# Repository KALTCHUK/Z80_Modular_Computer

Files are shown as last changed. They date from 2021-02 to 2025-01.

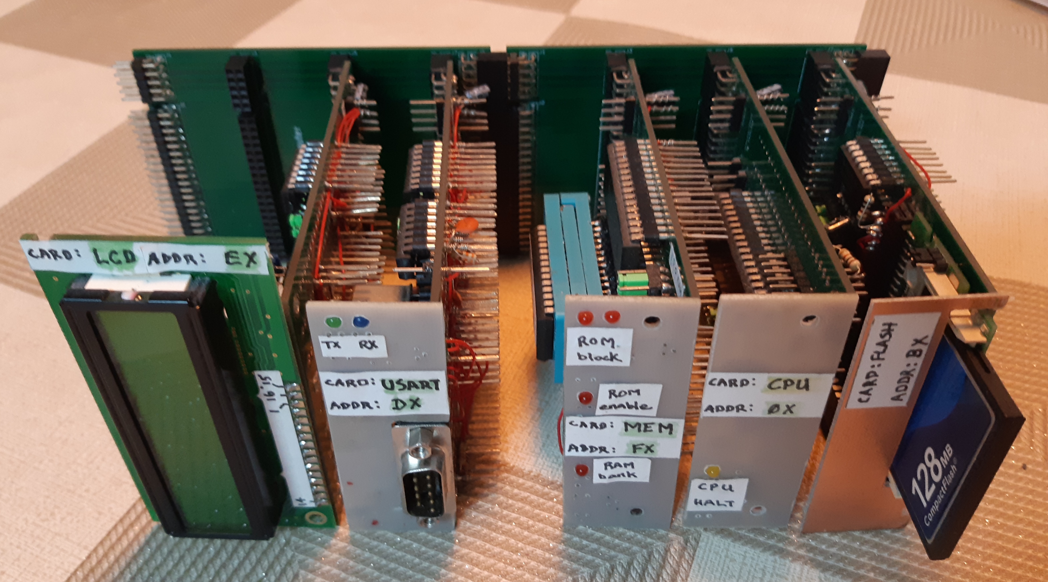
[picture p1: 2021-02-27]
pics and vids/assembly_full_1.jpg

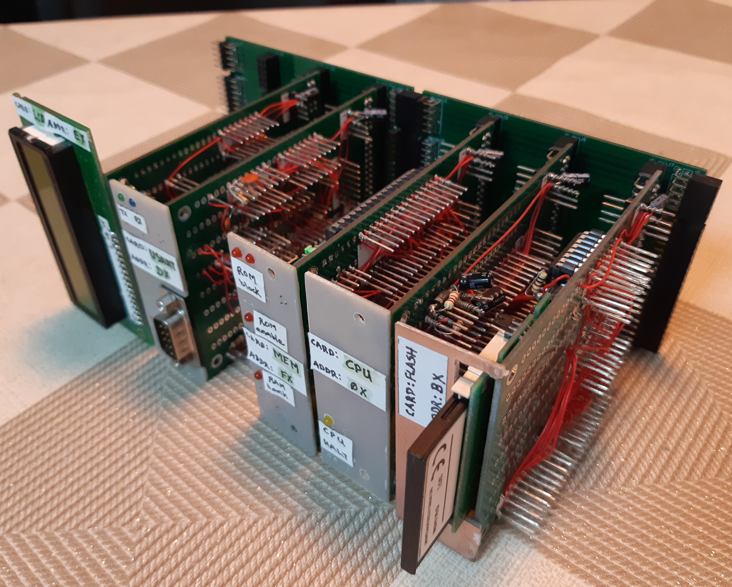
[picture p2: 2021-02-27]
pics and vids/assembly_full_2.jpg

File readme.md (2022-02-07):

# Proton - Z80 Modular Computer #

## Licence ##
This project is made public under the terms of the strongly-reciprocal variant of the CERN Open Hardware Licence version 2. By using any part of this project you abide to this licence.

## Overview ##
Two years ago I was searching for some ICs in my component drawers and came across a Z80 CPU and an Intel 8251 USART. I had an instant flashback and remembered my first contact with a microprocessor back in 1982. It was a Z80. After a few minutes of nostalgia I decided to make good use of these components and build a computer. 

Of course I couldn't avoid thinking about this "new project" with my Systems Engineer mindset. So, I established a few initial goals:

- This project is a hobby, so it has to be fun.
- It should use mainly technologies available in the 1980's.
- The computer has to run commercial software.
- The architecture should be modular allowing for new cards with specific functions.
- It also has to be a hardware/software development platform for students, hobbyists and enthusiasts.

After some research I decided to design the hardware fully compatible with CP/M 2.2.

One and a half years later, I finally had my wire wrapped computer running CP/M. I could write programs using WordStar and compile them with BDS C compiler, Microsoft Basic compiler or SLR Z80 macro assembler. It was fun, exciting and challenging. After that, I decided it was time to turn the prototype into a finished product.

It's gratifying to see that in two years, alone, I was able to transform an idea into a commercial product.

The content of this repo is a small portion of the knowledge gathered during these two years developing the Proton Z80 Modular Computer. Most of the information and results are in my logbook - a notebook (paper, not a computer), where I write everything before executing. During this period, I was the system engineer, hardware engineer, software engineer and project manager. Why did it take me so long to complete this project? Because it's a weekend hobby and also because sometimes I had to wait many weeks to receive some components and PCBs.  

Ricardo Kaltchuk

Ashdod - IL, october 2021.

## About the final product. ##

Is it perfect? No. 
Is it state of the art? No. 
Does I meet the initial goal? Yes. 
Am I happy with it? For sure!

## Github directories ##

All directory names are self-explanatory and you'll find a readme file inside each one with some additional info.

## What's most important ##

Well, if you want to build your own Proton Z80 Modular Computer, you'll need to check at least these directories:

- CPM build,
- CPM software,
- KiCAD files,
- Monitor build,
- System manuals (Proton and Monitor) and
- pics.

## You want your own Proton? So follow these steps: ##

1) Order the PCBs. You can order from PCBway and JLC PCB with the codes in the Proton Manual.
2) Buy the components according to the bill of materials in the Proton Manual.
3) Assemble the cards.
4) Download the software from Github.
5) Burn the EEPROM and microcontrollers.
6) Configure the jumpers on the cards according to instructions in the Proton Manual.
7) Assemble the rack (optional) and insert the cards.

Ready to start! Now you can transfer all the CP/M software from your computer to the Proton.

In the Proton User's Manual there's a section called "Building Procedure" which describes in details all the steps listed above. I suggest you read ALL the manual before starting.

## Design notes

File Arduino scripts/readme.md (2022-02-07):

## What you'll find in this directory ##
Only Arduino scripts. Nothing relevant for the Proton assembly, except if you intend to build your own EEPROM programmer. In this case, you should take a look at EProg_1.3. There you'll find the Arduino script used on the EPROG - EEPROM Programmer, that I made. The circuit diagram and PCB layout are in the "KiCAD files" directory. It's important to note that I designed the EPROG specifically to be used with the W27C512.

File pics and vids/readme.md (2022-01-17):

## What you'll find in this directory ##
Pictures and videos of the Proton, from wire wrapped ptototype phase to final products. Also a few videos of CP/M and the Monitor demo.

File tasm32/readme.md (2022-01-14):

## What you'll find in this directory ##
Tasm is a macro assembler for Z80 and few other CPUs. It runs on DOS and is quite robust and simple. I used it to compile all assembly files in "CPM build" and "Monitor build". The compilation generates a .OBJ file, which is a HEX in Intel format file.

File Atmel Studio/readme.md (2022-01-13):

## What you'll find in this directory ##
Several "projects" built with Atmel Studio. Most of them are only some tests I made in order to get familiar with Atmel Studio, AVRISP mkII programmer and ATmega328 microcontroller.

The important thing here is the directory called "preTTY". (It's called preTTY because I started working on it before the TTY Card was complete). There you'll find the firmware used on the microcontrollers from the TTY Card (two ATmega328, one for each serial port). Both microcontrollers have exactly the same firmware.

Before beginning the Proton project I already had a good experience using Arduino. But, for the TTY Card, I couldn't simply plug an Arduind board and that's it. So I used only the Arduino's microcontroller "bareback", with no bootloader, running at 20MHz.

Yeah, yeah, I know, I'm using sequencial logic to implement combinational tasks. Who cares? It was challenging and I did it.

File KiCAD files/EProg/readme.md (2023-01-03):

## What you'll find in this directory ##
The KiCAD files for a EEPROM programmer, specifically, the W27C512, a 64KB EEPROM, which I used on the Proton MEM Card.

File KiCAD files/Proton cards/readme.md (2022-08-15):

## What you'll find in this directory ##
Each subdirectory contains the KiCAD files for a specific Proton card, assembled in the rack. They all contain the circuit diagrams. Most of them also have the PCB layouts and some even have the Gerber files I sent to the PCB manufacturers (PCBway and JLC PCB)).

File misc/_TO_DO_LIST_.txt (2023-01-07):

- DO-08:
	- design PCB
	- assemble and test

- DI-08:
	- write firmware.
	- build and test prototype
	- design PCB
	- assemble and test

- RS485:
	- design PCB
	- assemble and test

------------------------------------------------------------------
Some ideas for new cards:

- PWM, stepper motor, fast counter, analog I/O (4-20mA, RTD, TC?)
- audio card for .WAV play
- VGA and PS2 keyboard (FPGA, STM32?)

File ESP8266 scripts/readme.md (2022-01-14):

## What you'll find in this directory ##
When I was almost finishing the Proton prototype I had this idea to use an ESP8266 connected to one of the serial ports of the TTY Card and access the Proton via telnet. I didn't complete the idea, but some of the experiences are here. I managed to connect the ESP8266 and the telnet cliente when they were in the same network (WiFi), but didn't succeed using dynamic DNS. To be continued...

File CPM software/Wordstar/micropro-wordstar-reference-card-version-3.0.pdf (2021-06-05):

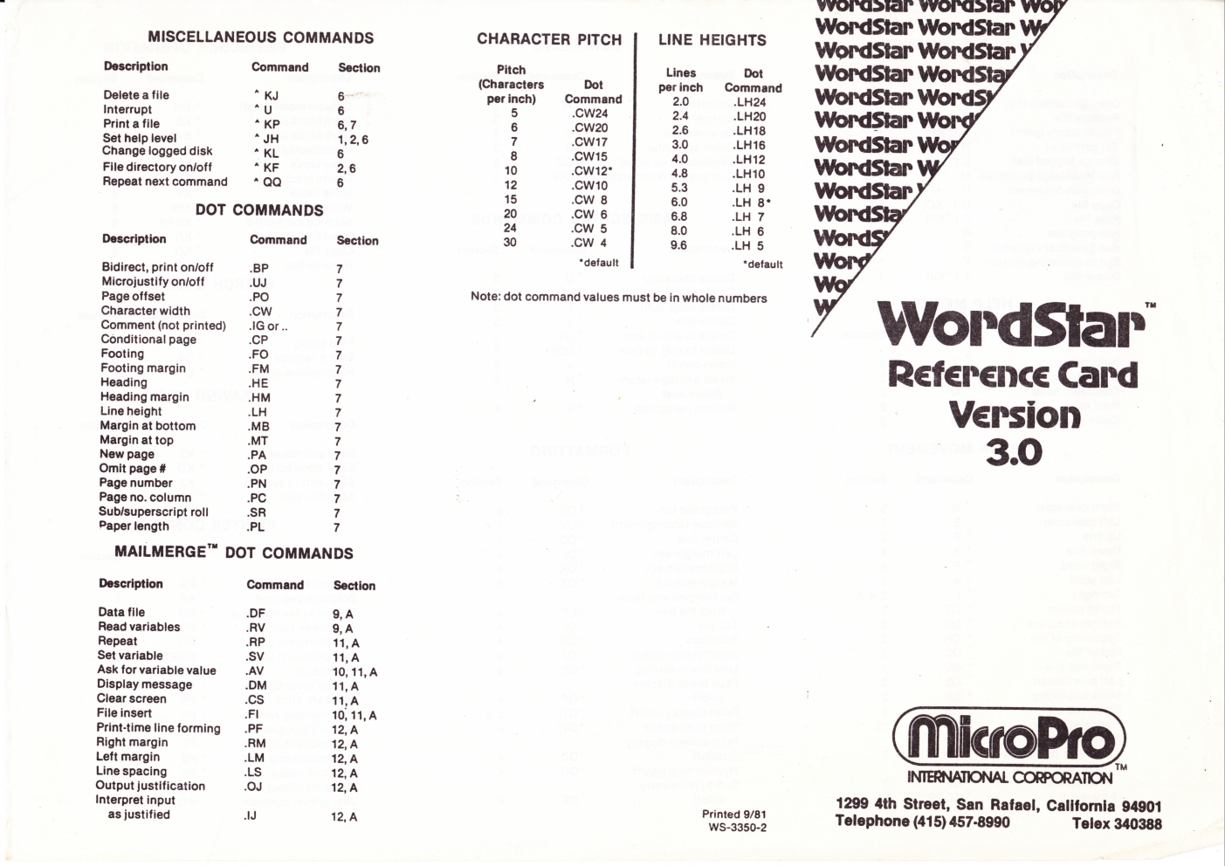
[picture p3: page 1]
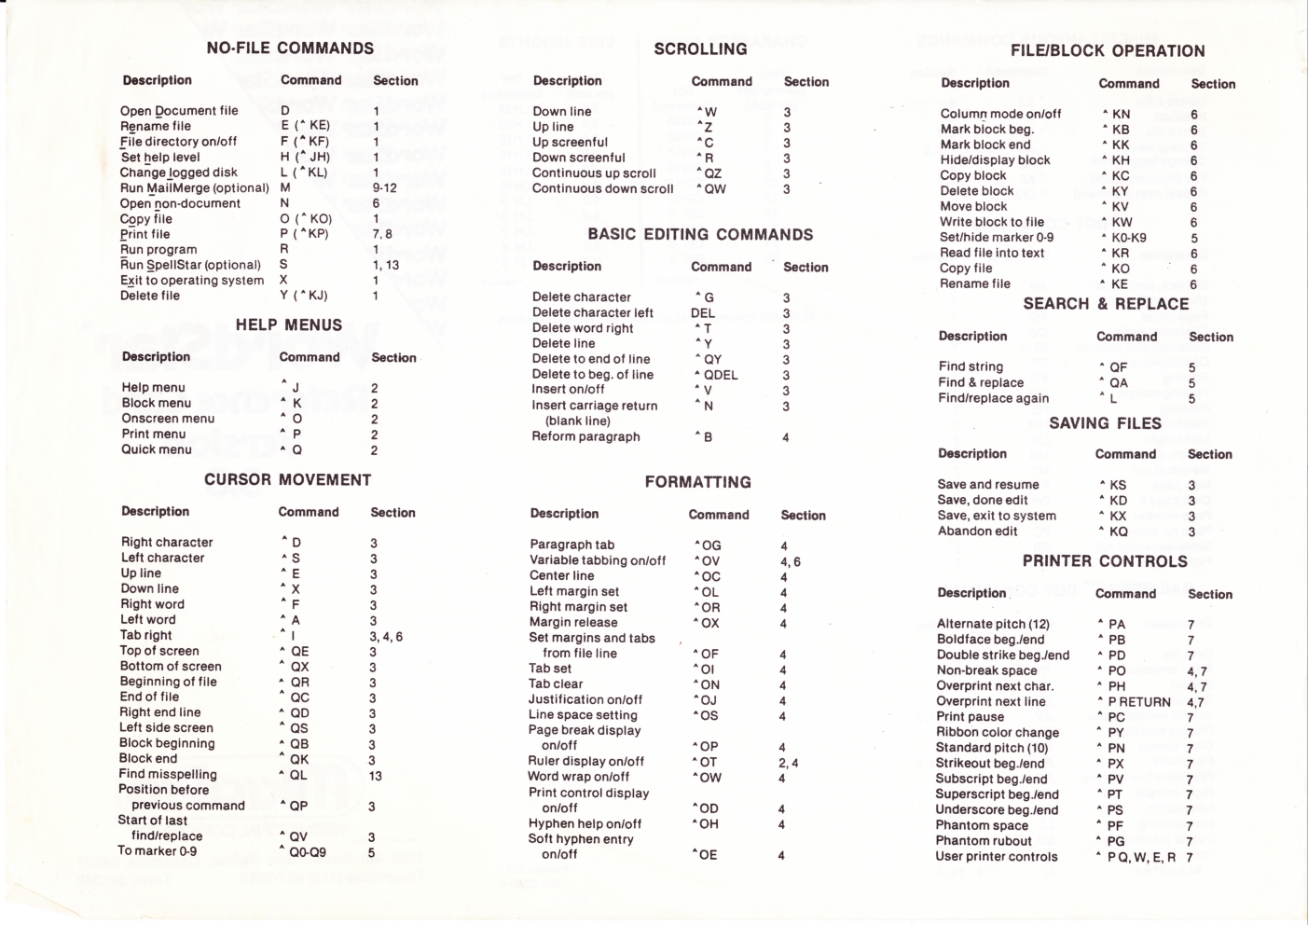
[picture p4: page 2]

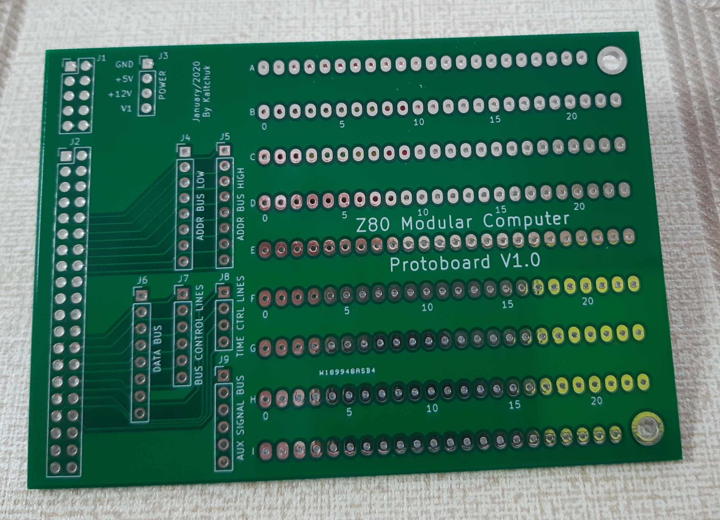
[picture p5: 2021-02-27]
pics and vids/protoboard_1.jpg

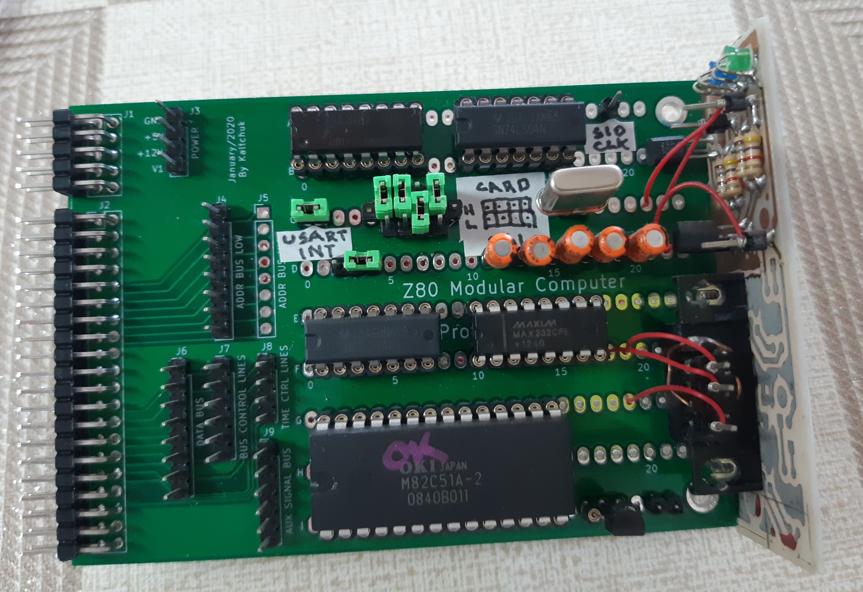
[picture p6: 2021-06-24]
pics and vids/proto_usart_1.jpg

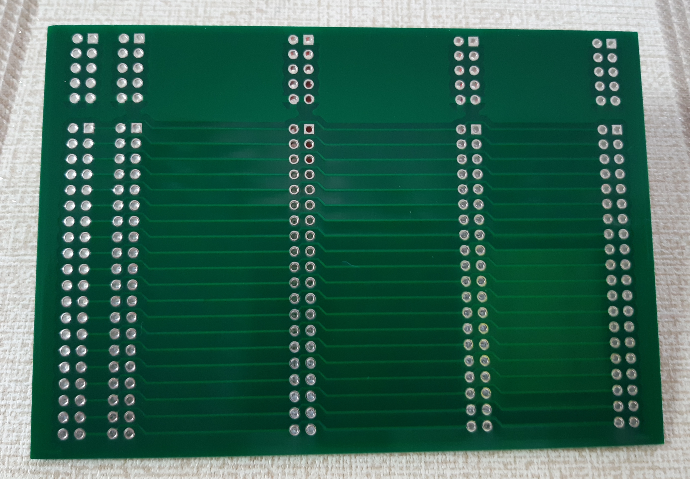
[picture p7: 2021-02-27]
pics and vids/backplane_2.jpg

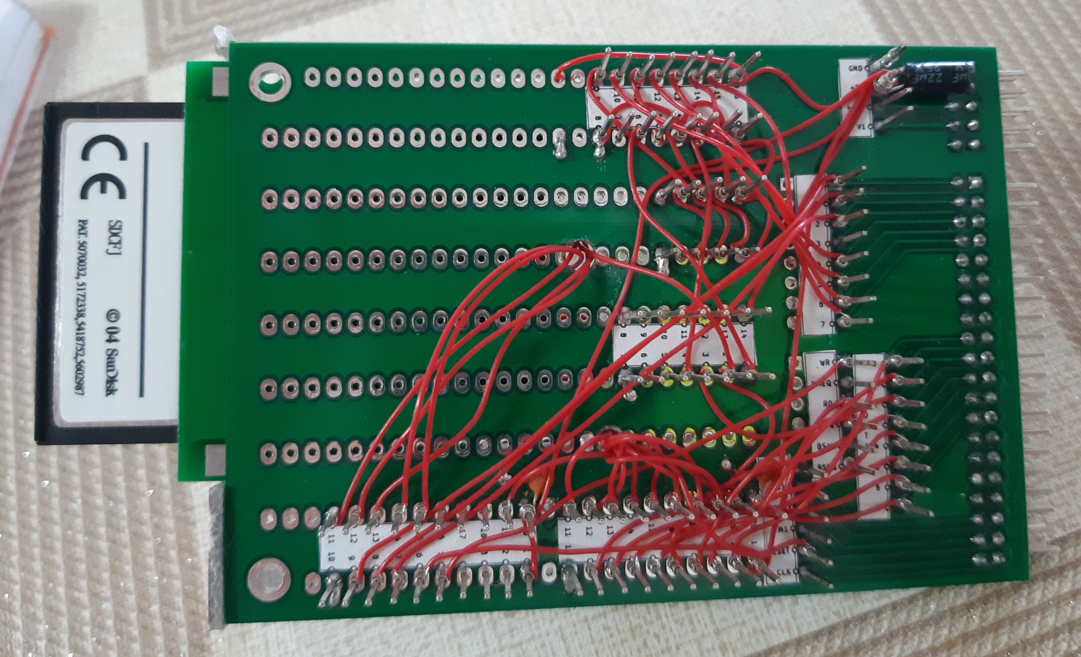
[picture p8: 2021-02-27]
pics and vids/proto_flash_2.jpg

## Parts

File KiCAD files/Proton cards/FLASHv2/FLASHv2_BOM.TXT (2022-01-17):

REFERENCE	VALUE		DESCRIPTION								QTY
-----------------------------------------------------------------------------------------------------------
    C1	10uF		Capacitor_THT:CP_Radial_D5.0mm_P2.50mm						1
  C2-C6	10nF		Capacitor_THT:C_Disc_D3.8mm_W2.6mm_P2.50mm					5
    J1	card addr	Connector_PinHeader_2.54mm:PinHeader_2x04_P2.54mm_Vertical			1
    J2	Power Bus	Connector_PinHeader_2.54mm:PinHeader_2x05_P2.54mm_90_deg_female			1
    J3	Signal Bus	Connector_PinHeader_2.54mm:PinHeader_2x20_P2.54mm_90_deg_female			1
    J4	IDE connector	Connector_PinHeader_2.00mm:PinHeader_2x22_P2.00mm_90_deg_female +		1
			IDE 44 Pin Male to CF Compact Flash Male Adapter Connector +
			Compact Flash 128MB
    R6	1k		Resistor_THT:R_Axial_DIN0207_L6.3mm_D2.5mm_P10.16mm_Horizontal			1
    RN1	4x10k		Resistor_THT:R_Array_SIP5							1
    U1	74LS04		Package_DIP:DIP-14_W7.62mm_Socket_LongPads + 14 pin DIP socket			1
    U2	74LS85		Package_DIP:DIP-16_W7.62mm_Socket_LongPads + 16 pin DIP socket			1
  U3, U4		74LS245	Package_DIP:DIP-20_W7.62mm_Socket_LongPads +20 pin DIP socket		2

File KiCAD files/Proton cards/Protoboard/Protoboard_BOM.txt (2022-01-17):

    J1	Power Bus	Connector_PinHeader_2.54mm:PinHeader_2x05_P2.54mm_Vertical	~	1
    J2	Signal Bus	Connector_PinHeader_2.54mm:PinHeader_2x20_P2.54mm_Vertical	~	1
    J3	Power	Connector_PinHeader_2.54mm:PinHeader_1x04_P2.54mm_Vertical	~	1
    J4	ADDR LO	Connector_PinHeader_2.54mm:PinHeader_1x08_P2.54mm_Vertical	~	1
    J5	ADDR HI	Connector_PinHeader_2.54mm:PinHeader_1x08_P2.54mm_Vertical	~	1
    J6	DATA	Connector_PinHeader_2.54mm:PinHeader_1x08_P2.54mm_Vertical	~	1
    J7	BUS CTRL	Connector_PinHeader_2.54mm:PinHeader_1x06_P2.54mm_Vertical	~	1
    J8	TIME CTRL	Connector_PinHeader_2.54mm:PinHeader_1x04_P2.54mm_Vertical	~	1
    J9	AUX SIGNAL	Connector_PinHeader_2.54mm:PinHeader_1x06_P2.54mm_Vertical	~	1

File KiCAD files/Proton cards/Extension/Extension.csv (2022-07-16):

Source: | C:\Users\kaltc\Documents\GitHub\Z80_Modular_Computer\KiCAD files\Extension\Extension.kicad_sch
Date: | 16/07/2022 6:46:03
Tool: | Eeschema (6.0.4)
Generator: | C:\Program Files\KiCad\6.0\bin\scripting\plugins/bom_csv_grouped_by_value.py
Component Count: | 4
Individual Components:
Item | Qty | Reference(s) | Value | LibPart | Footprint | Datasheet
 |  | J1 | Conn_02x05_Odd_Even | Connector_Generic:Conn_02x05_Odd_Even | Connector_PinHeader_2.54mm:PinHeader_2x05_P2.54mm_Vertical | ~
 |  | J2 | Conn_02x20_Odd_Even | Connector_Generic:Conn_02x20_Odd_Even | Connector_PinHeader_2.54mm:PinHeader_2x20_P2.54mm_Vertical | ~
 |  | J3 | Conn_02x05_Odd_Even | Connector_Generic:Conn_02x05_Odd_Even | Connector_PinHeader_2.54mm:PinHeader_2x05_P2.54mm_Vertical | ~
 |  | J4 | Conn_02x20_Odd_Even | Connector_Generic:Conn_02x20_Odd_Even | Connector_PinHeader_2.54mm:PinHeader_2x20_P2.54mm_Vertical | ~
Collated Components:
Item | Qty | Reference(s) | Value | LibPart | Footprint | Datasheet
1 | 2 | J1, J3 | Conn_02x05_Odd_Even | Connector_Generic:Conn_02x05_Odd_Even | Connector_PinHeader_2.54mm:PinHeader_2x05_P2.54mm_Vertical | ~
2 | 2 | J2, J4 | Conn_02x20_Odd_Even | Connector_Generic:Conn_02x20_Odd_Even | Connector_PinHeader_2.54mm:PinHeader_2x20_P2.54mm_Vertical | ~

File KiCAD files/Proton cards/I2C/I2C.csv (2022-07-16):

Source: | C:\Users\kaltc\Documents\GitHub\Z80_Modular_Computer\KiCAD files\I2C\I2C.kicad_sch
Date: | 16/07/2022 6:00:42
Tool: | Eeschema (6.0.4)
Generator: | C:\Program Files\KiCad\6.0\bin\scripting\plugins/bom_csv_grouped_by_value.py
Component Count: | 33
Individual Components:
Item | Qty | Reference(s) | Value | LibPart | Footprint | Datasheet
 |  | BT1 | 3V | Device:Battery_Cell | MyStuff:Battery-Holder_CR2032 | ~
 |  | C1 | 10nF | Device:C | Capacitor_THT:C_Disc_D3.8mm_W2.6mm_P2.50mm | ~
 |  | C2 | 10nF | Device:C | Capacitor_THT:C_Disc_D3.8mm_W2.6mm_P2.50mm | ~
 |  | C3 | 10nF | Device:C | Capacitor_THT:C_Disc_D3.8mm_W2.6mm_P2.50mm | ~
 |  | C4 | 10nF | Device:C | Capacitor_THT:C_Disc_D3.8mm_W2.6mm_P2.50mm | ~
 |  | C5 | 10nF | Device:C | Capacitor_THT:C_Disc_D3.8mm_W2.6mm_P2.50mm | ~
 |  | C6 | 10nF | Device:C | Capacitor_THT:C_Disc_D3.8mm_W2.6mm_P2.50mm | ~
 |  | C7 | 10nF | Device:C | Capacitor_THT:C_Disc_D3.8mm_W2.6mm_P2.50mm | ~
 |  | C8 | 10nF | Device:C | Capacitor_THT:C_Disc_D3.8mm_W2.6mm_P2.50mm | ~
 |  | C9 | 10uF | Device:CP | Capacitor_THT:CP_Radial_D5.0mm_P2.50mm
 |  | C10 | 33pF | Device:C | Capacitor_THT:C_Disc_D3.8mm_W2.6mm_P2.50mm | ~
 |  | C11 | 33pF | Device:C | Capacitor_THT:C_Disc_D3.8mm_W2.6mm_P2.50mm | ~
 |  | H1 | MountingHole | Mechanical:MountingHole | MountingHole:MountingHole_3mm_Pad_TopBottom | ~
 |  | H2 | MountingHole | Mechanical:MountingHole | MountingHole:MountingHole_3mm_Pad_TopBottom | ~
 |  | J1 | card addr | Connector_Generic:Conn_02x04_Odd_Even | Connector_PinHeader_2.54mm:PinHeader_2x04_P2.54mm_Vertical | ~
 |  | J2 | Power Bus | Connector_Generic:Conn_02x05_Odd_Even | Connector_PinHeader_2.54mm:PinHeader_2x05_P2.54mm_Vertical | ~
 |  | J3 | Signal Bus | Connector_Generic:Conn_02x20_Odd_Even | Connector_PinHeader_2.54mm:PinHeader_2x20_P2.54mm_Vertical | ~
 |  | J4 | I2C int | Connector:Conn_01x04_Male | Connector_PinHeader_2.54mm:PinHeader_1x04_P2.54mm_Vertical | ~
 |  | J5 | I2C ext | Connector_Generic:Conn_02x02_Top_Bottom | Connector_PinHeader_2.54mm:PinHeader_2x02_P2.54mm_Vertical | ~
 |  | R1 | 6k8 | Device:R | Resistor_THT:R_Axial_DIN0207_L6.3mm_D2.5mm_P10.16mm_Horizontal | ~
 |  | R2 | 6k8 | Device:R | Resistor_THT:R_Axial_DIN0207_L6.3mm_D2.5mm_P10.16mm_Horizontal | ~
 |  | RN1 | 4x10k | Device:R_Network04 | Resistor_THT:R_Array_SIP5 | http://www.vishay.com/docs/31509/csc.pdf
 |  | RN2 | 4x10k | Device:R_Network04 | Resistor_THT:R_Array_SIP5 | http://www.vishay.com/docs/31509/csc.pdf
 |  | U1 | 74LS85 | 74xx:74LS85 | Package_DIP:DIP-16_W7.62mm_Socket_LongPads | http://www.ti.com/lit/gpn/sn74LS85
 |  | U2 | 74LS74 | 74xx:74LS74 | Package_DIP:DIP-14_W7.62mm_Socket_LongPads | 74xx/74hc_hct74.pdf
 |  | U3 | 74LS04 | 74xx:74LS04 | Package_DIP:DIP-14_W7.62mm_Socket_LongPads | http://www.ti.com/lit/gpn/sn74LS04
 |  | U4 | 74LS08 | 74xx:74LS08 | Package_DIP:DIP-14_W7.62mm_Socket_LongPads | http://www.ti.com/lit/gpn/sn74LS08
 |  | U5 | 74LS245 | 74xx:74LS245 | Package_DIP:DIP-20_W7.62mm_Socket_LongPads | http://www.ti.com/lit/gpn/sn74LS245
 |  | U6 | AT89C4051-24P | MCU_Microchip_8051:AT89C4051-24P | Package_DIP:DIP-20_W7.62mm_Socket_LongPads | http://ww1.microchip.com/downloads/en/DeviceDoc/doc1001.pdf
 |  | U7 | DS1307+ | Timer_RTC:DS1307+ | Package_DIP:DIP-8_W7.62mm_Socket_LongPads | https://datasheets.maximintegrated.com/en/ds/DS1307.pdf
 |  | U8 | FM24C64B | Memory_NVRAM:FM24C64B | Package_DIP:DIP-8_W7.62mm_Socket_LongPads | http://www.cypress.com/file/41651/download
 |  | Y1 | 24MHz | Device:Crystal | Crystal:Crystal_HC49-U_Vertical | ~
 |  | Y2 | 32.768kHz | Device:Crystal_Small | Crystal:Crystal_Round_D1.5mm_Vertical | ~
Collated Components:
Item | Qty | Reference(s) | Value | LibPart | Footprint | Datasheet
1 | 1 | BT1 | 3V | Device:Battery_Cell | MyStuff:Battery-Holder_CR2032 | ~
2 | 8 | C1, C2, C3, C4, C5, C6, C7, C8 | 10nF | Device:C | Capacitor_THT:C_Disc_D3.8mm_W2.6mm_P2.50mm | ~
3 | 1 | C9 | 10uF | Device:CP | Capacitor_THT:CP_Radial_D5.0mm_P2.50mm
4 | 2 | C10, C11 | 33pF | Device:C | Capacitor_THT:C_Disc_D3.8mm_W2.6mm_P2.50mm | ~
5 | 2 | H1, H2 | MountingHole | Mechanical:MountingHole | MountingHole:MountingHole_3mm_Pad_TopBottom | ~
6 | 1 | J1 | card addr | Connector_Generic:Conn_02x04_Odd_Even | Connector_PinHeader_2.54mm:PinHeader_2x04_P2.54mm_Vertical | ~
7 | 1 | J2 | Power Bus | Connector_Generic:Conn_02x05_Odd_Even | Connector_PinHeader_2.54mm:PinHeader_2x05_P2.54mm_Vertical | ~
8 | 1 | J3 | Signal Bus | Connector_Generic:Conn_02x20_Odd_Even | Connector_PinHeader_2.54mm:PinHeader_2x20_P2.54mm_Vertical | ~
9 | 1 | J4 | I2C int | Connector:Conn_01x04_Male | Connector_PinHeader_2.54mm:PinHeader_1x04_P2.54mm_Vertical | ~
10 | 1 | J5 | I2C ext | Connector_Generic:Conn_02x02_Top_Bottom | Connector_PinHeader_2.54mm:PinHeader_2x02_P2.54mm_Vertical | ~
11 | 2 | R1, R2 | 6k8 | Device:R | Resistor_THT:R_Axial_DIN0207_L6.3mm_D2.5mm_P10.16mm_Horizontal | ~
12 | 2 | RN1, RN2 | 4x10k | Device:R_Network04 | Resistor_THT:R_Array_SIP5 | http://www.vishay.com/docs/31509/csc.pdf
13 | 1 | U1 | 74LS85 | 74xx:74LS85 | Package_DIP:DIP-16_W7.62mm_Socket_LongPads | http://www.ti.com/lit/gpn/sn74LS85
14 | 1 | U2 | 74LS74 | 74xx:74LS74 | Package_DIP:DIP-14_W7.62mm_Socket_LongPads | 74xx/74hc_hct74.pdf
15 | 1 | U3 | 74LS04 | 74xx:74LS04 | Package_DIP:DIP-14_W7.62mm_Socket_LongPads | http://www.ti.com/lit/gpn/sn74LS04
16 | 1 | U4 | 74LS08 | 74xx:74LS08 | Package_DIP:DIP-14_W7.62mm_Socket_LongPads | http://www.ti.com/lit/gpn/sn74LS08
17 | 1 | U5 | 74LS245 | 74xx:74LS245 | Package_DIP:DIP-20_W7.62mm_Socket_LongPads | http://www.ti.com/lit/gpn/sn74LS245
18 | 1 | U6 | AT89C4051-24P | MCU_Microchip_8051:AT89C4051-24P | Package_DIP:DIP-20_W7.62mm_Socket_LongPads | http://ww1.microchip.com/downloads/en/DeviceDoc/doc1001.pdf
19 | 1 | U7 | DS1307+ | Timer_RTC:DS1307+ | Package_DIP:DIP-8_W7.62mm_Socket_LongPads | https://datasheets.maximintegrated.com/en/ds/DS1307.pdf
20 | 1 | U8 | FM24C64B | Memory_NVRAM:FM24C64B | Package_DIP:DIP-8_W7.62mm_Socket_LongPads | http://www.cypress.com/file/41651/download
21 | 1 | Y1 | 24MHz | Device:Crystal | Crystal:Crystal_HC49-U_Vertical | ~
22 | 1 | Y2 | 32.768kHz | Device:Crystal_Small | Crystal:Crystal_Round_D1.5mm_Vertical | ~

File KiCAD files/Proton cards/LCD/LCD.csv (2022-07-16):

Source: | C:\Users\kaltc\Documents\GitHub\Z80_Modular_Computer\KiCAD files\LCD\LCD.kicad_sch
Date: | 16/07/2022 7:41:25
Tool: | Eeschema (6.0.4)
Generator: | C:\Program Files\KiCad\6.0\bin\scripting\plugins/bom_csv_grouped_by_value.py
Component Count: | 12
Individual Components:
Item | Qty | Reference(s) | Value | LibPart | Footprint | Datasheet
 |  | C1 | 10uF | Device:CP
 |  | J1 | card addr | Connector_Generic:Conn_02x04_Odd_Even |  | ~
 |  | J2 | Power Bus | Connector_Generic:Conn_02x05_Odd_Even |  | ~
 |  | J3 | Signal Bus | Connector_Generic:Conn_02x20_Odd_Even |  | ~
 |  | J4 | LCD connector | Connector:Conn_01x16_Female |  | ~
 |  | R1 | 10k | Device:R |  | ~
 |  | R2 | 10k | Device:R |  | ~
 |  | R3 | 10k | Device:R |  | ~
 |  | R4 | 10k | Device:R |  | ~
 |  | RV1 | 10k | Device:R_POT_TRIM
 |  | U1 | 74LS04 | 74xx:74LS04 |  | http://www.ti.com/lit/gpn/sn74LS04
 |  | U2 | 74LS85 | 74xx:74LS85 |  | http://www.ti.com/lit/gpn/sn74LS85
Collated Components:
Item | Qty | Reference(s) | Value | LibPart | Footprint | Datasheet
1 | 1 | C1 | 10uF | Device:CP
2 | 1 | J1 | card addr | Connector_Generic:Conn_02x04_Odd_Even |  | ~
3 | 1 | J2 | Power Bus | Connector_Generic:Conn_02x05_Odd_Even |  | ~
4 | 1 | J3 | Signal Bus | Connector_Generic:Conn_02x20_Odd_Even |  | ~
5 | 1 | J4 | LCD connector | Connector:Conn_01x16_Female |  | ~
6 | 4 | R1, R2, R3, R4 | 10k | Device:R |  | ~
7 | 1 | RV1 | 10k | Device:R_POT_TRIM
8 | 1 | U1 | 74LS04 | 74xx:74LS04 |  | http://www.ti.com/lit/gpn/sn74LS04
9 | 1 | U2 | 74LS85 | 74xx:74LS85 |  | http://www.ti.com/lit/gpn/sn74LS85

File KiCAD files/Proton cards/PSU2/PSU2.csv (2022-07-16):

Source: | C:\Users\kaltc\Documents\GitHub\Z80_Modular_Computer\KiCAD files\PSU2\PSU2.kicad_sch
Date: | 16/07/2022 6:23:53
Tool: | Eeschema (6.0.4)
Generator: | C:\Program Files\KiCad\6.0\bin\scripting\plugins/bom_csv_grouped_by_value.py
Component Count: | 20
Individual Components:
Item | Qty | Reference(s) | Value | LibPart | Footprint | Datasheet
 |  | D1 | LED | Device:LED | LED_THT:LED_D3.0mm | ~
 |  | D2 | LED | Device:LED | LED_THT:LED_D3.0mm | ~
 |  | D3 | LED | Device:LED | LED_THT:LED_D3.0mm | ~
 |  | H1 | MountingHole | Mechanical:MountingHole | MyStuff:Mounting_Hole_0.2in | ~
 |  | H2 | MountingHole | Mechanical:MountingHole | MyStuff:Mounting_Hole_0.2in | ~
 |  | J1 | Ext switch | Connector_Generic:Conn_01x02 | Connector_PinHeader_2.54mm:PinHeader_1x02_P2.54mm_Vertical | ~
 |  | J2 | To switch | Connector_Generic:Conn_01x02 | Connector_PinHeader_2.54mm:PinHeader_1x02_P2.54mm_Vertical | ~
 |  | J3 | Mains | Connector_Generic:Conn_01x02 | MyStuff:IEC60320_2pin | ~
 |  | J4 | Vo enable | Connector_Generic:Conn_02x02_Odd_Even | Connector_PinHeader_2.54mm:PinHeader_2x02_P2.54mm_Vertical | ~
 |  | J5 | Power bus | Connector_Generic:Conn_02x05_Odd_Even | Connector_PinHeader_2.54mm:PinHeader_2x05_P2.54mm_Vertical | ~
 |  | J6 | Mech support | Connector_Generic:Conn_02x05_Odd_Even | Connector_PinHeader_2.54mm:PinHeader_2x05_P2.54mm_Vertical | ~
 |  | K1 | SRD-05VDC-SL-C | Relay:Y14x-1C-xxDS | MyStuff:Relay_SPDT_Songel-15x19mm | http://www.hsinda.com.cn/en/imgdown.asp?FileName=UploadFiles/201431310240386.pdf
 |  | PS1 | MT3608_2-24V_2A | Converter_DCDC:MEE1S0512SC | MyStuff:MT3608_2-24V_2A | https://power.murata.com/pub/data/power/ncl/kdc_mee1.pdf
 |  | PS2 | XPJ-01B_5V_10W | Converter_ACDC:IRM-10-5 | MyStuff:Converter_ACDC_5V_10W_XPJ-01B | https://www.meanwell.com/Upload/PDF/IRM-10/IRM-10-SPEC.PDF
 |  | R1 | 1k2 | Device:R | Resistor_THT:R_Axial_DIN0207_L6.3mm_D2.5mm_P7.62mm_Horizontal | ~
 |  | R2 | 390 | Device:R | Resistor_THT:R_Axial_DIN0207_L6.3mm_D2.5mm_P7.62mm_Horizontal | ~
 |  | R3 | 330 | Device:R | Resistor_THT:R_Axial_DIN0207_L6.3mm_D2.5mm_P7.62mm_Horizontal | ~
 |  | R4 | 240 | Device:R | Resistor_THT:R_Axial_DIN0207_L6.3mm_D2.5mm_P7.62mm_Horizontal | ~
 |  | R5 | 150 | Device:R | Resistor_THT:R_Axial_DIN0207_L6.3mm_D2.5mm_P7.62mm_Horizontal | ~
 |  | U1 | LM317_TO-220 | Regulator_Linear:LM317_TO-220 | Package_TO_SOT_THT:TO-220-3_Vertical | http://www.ti.com/lit/ds/symlink/lm317.pdf
Collated Components:
Item | Qty | Reference(s) | Value | LibPart | Footprint | Datasheet
1 | 3 | D1, D2, D3 | LED | Device:LED | LED_THT:LED_D3.0mm | ~
2 | 2 | H1, H2 | MountingHole | Mechanical:MountingHole | MyStuff:Mounting_Hole_0.2in | ~
3 | 1 | J1 | Ext switch | Connector_Generic:Conn_01x02 | Connector_PinHeader_2.54mm:PinHeader_1x02_P2.54mm_Vertical | ~
4 | 1 | J2 | To switch | Connector_Generic:Conn_01x02 | Connector_PinHeader_2.54mm:PinHeader_1x02_P2.54mm_Vertical | ~
5 | 1 | J3 | Mains | Connector_Generic:Conn_01x02 | MyStuff:IEC60320_2pin | ~
6 | 1 | J4 | Vo enable | Connector_Generic:Conn_02x02_Odd_Even | Connector_PinHeader_2.54mm:PinHeader_2x02_P2.54mm_Vertical | ~
7 | 1 | J5 | Power bus | Connector_Generic:Conn_02x05_Odd_Even | Connector_PinHeader_2.54mm:PinHeader_2x05_P2.54mm_Vertical | ~
8 | 1 | J6 | Mech support | Connector_Generic:Conn_02x05_Odd_Even | Connector_PinHeader_2.54mm:PinHeader_2x05_P2.54mm_Vertical | ~
9 | 1 | K1 | SRD-05VDC-SL-C | Relay:Y14x-1C-xxDS | MyStuff:Relay_SPDT_Songel-15x19mm | http://www.hsinda.com.cn/en/imgdown.asp?FileName=UploadFiles/201431310240386.pdf
10 | 1 | PS1 | MT3608_2-24V_2A | Converter_DCDC:MEE1S0512SC | MyStuff:MT3608_2-24V_2A | https://power.murata.com/pub/data/power/ncl/kdc_mee1.pdf
11 | 1 | PS2 | XPJ-01B_5V_10W | Converter_ACDC:IRM-10-5 | MyStuff:Converter_ACDC_5V_10W_XPJ-01B | https://www.meanwell.com/Upload/PDF/IRM-10/IRM-10-SPEC.PDF
12 | 1 | R1 | 1k2 | Device:R | Resistor_THT:R_Axial_DIN0207_L6.3mm_D2.5mm_P7.62mm_Horizontal | ~
13 | 1 | R2 | 390 | Device:R | Resistor_THT:R_Axial_DIN0207_L6.3mm_D2.5mm_P7.62mm_Horizontal | ~
14 | 1 | R3 | 330 | Device:R | Resistor_THT:R_Axial_DIN0207_L6.3mm_D2.5mm_P7.62mm_Horizontal | ~
15 | 1 | R4 | 240 | Device:R | Resistor_THT:R_Axial_DIN0207_L6.3mm_D2.5mm_P7.62mm_Horizontal | ~
16 | 1 | R5 | 150 | Device:R | Resistor_THT:R_Axial_DIN0207_L6.3mm_D2.5mm_P7.62mm_Horizontal | ~
17 | 1 | U1 | LM317_TO-220 | Regulator_Linear:LM317_TO-220 | Package_TO_SOT_THT:TO-220-3_Vertical | http://www.ti.com/lit/ds/symlink/lm317.pdf

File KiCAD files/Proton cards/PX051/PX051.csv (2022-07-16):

Source: | C:\Users\kaltc\Documents\GitHub\Z80_Modular_Computer\KiCAD files\PX051\PX051.kicad_sch
Date: | 16/07/2022 7:23:38
Tool: | Eeschema (6.0.4)
Generator: | C:\Program Files\KiCad\6.0\bin\scripting\plugins/bom_csv_grouped_by_value.py
Component Count: | 26
Individual Components:
Item | Qty | Reference(s) | Value | LibPart | Footprint | Datasheet
 |  | C1 | 10nF | Device:C |  | ~
 |  | C2 | 10nF | Device:C |  | ~
 |  | C3 | 10nF | Device:C |  | ~
 |  | C4 | 10uF | Device:CP | Capacitor_THT:CP_Radial_D5.0mm_P2.50mm
 |  | C5 | 10nF | Device:C |  | ~
 |  | C6 | 10uF | Device:CP | Capacitor_THT:CP_Radial_D5.0mm_P2.50mm
 |  | J1 | card addr | Connector_Generic:Conn_02x04_Odd_Even | Connector_PinHeader_2.54mm:PinHeader_2x04_P2.54mm_Vertical | ~
 |  | J2 | Power Bus | Connector_Generic:Conn_02x05_Odd_Even | Connector_PinHeader_2.54mm:PinHeader_2x05_P2.54mm_Vertical | ~
 |  | J3 | Signal Bus | Connector_Generic:Conn_02x20_Odd_Even | Connector_PinHeader_2.54mm:PinHeader_2x20_P2.54mm_Vertical | ~
 |  | Q1 | BC547 | Transistor_BJT:BC547 | Package_TO_SOT_THT:TO-92_Inline | http://www.fairchildsemi.com/ds/BC/BC547.pdf
 |  | Q2 | BC328 | Transistor_BJT:BC328 | Package_TO_SOT_THT:TO-92_Inline | http://www.redrok.com/PNP_BC327_-45V_-800mA_0.625W_Hfe100_TO-92.pdf
 |  | Q3 | BC547 | Transistor_BJT:BC547 | Package_TO_SOT_THT:TO-92_Inline | http://www.fairchildsemi.com/ds/BC/BC547.pdf
 |  | Q4 | BC328 | Transistor_BJT:BC328 | Package_TO_SOT_THT:TO-92_Inline | http://www.redrok.com/PNP_BC327_-45V_-800mA_0.625W_Hfe100_TO-92.pdf
 |  | R1 | 82k | Device:R | Resistor_THT:R_Axial_DIN0207_L6.3mm_D2.5mm_P7.62mm_Horizontal | ~
 |  | R2 | 12k | Device:R | Resistor_THT:R_Axial_DIN0207_L6.3mm_D2.5mm_P7.62mm_Horizontal | ~
 |  | R3 | 82k | Device:R | Resistor_THT:R_Axial_DIN0207_L6.3mm_D2.5mm_P7.62mm_Horizontal | ~
 |  | R4 | 12k | Device:R | Resistor_THT:R_Axial_DIN0207_L6.3mm_D2.5mm_P7.62mm_Horizontal | ~
 |  | R5 | 10k | Device:R | Resistor_THT:R_Axial_DIN0207_L6.3mm_D2.5mm_P7.62mm_Horizontal | ~
 |  | R6 | 10k | Device:R |  | ~
 |  | R7 | 10k | Device:R |  | ~
 |  | RN1 | 4x10k | Device:R_Network04 | Resistor_THT:R_Array_SIP5 | http://www.vishay.com/docs/31509/csc.pdf
 |  | U1 | 74LS85 | 74xx:74LS85 | Package_DIP:DIP-16_W7.62mm_Socket_LongPads | http://www.ti.com/lit/gpn/sn74LS85
 |  | U2 | 74LS04 | 74xx:74LS04 | Package_DIP:DIP-14_W7.62mm_Socket_LongPads | http://www.ti.com/lit/gpn/sn74LS04
 |  | U3 | 8255A | Interface:8255A | Package_DIP:DIP-40_W15.24mm | http://aturing.umcs.maine.edu/~meadow/courses/cos335/Intel8255A.pdf
 |  | U4 | AT89C4051-24P | MCU_Microchip_8051:AT89C4051-24P | Package_DIP:DIP-20_W7.62mm | http://ww1.microchip.com/downloads/en/DeviceDoc/doc1001.pdf
 |  | U5 | 74LS04 | 74xx:74LS04 |  | http://www.ti.com/lit/gpn/sn74LS04
Collated Components:
Item | Qty | Reference(s) | Value | LibPart | Footprint | Datasheet
1 | 4 | C1, C2, C3, C5 | 10nF | Device:C |  | ~
2 | 2 | C4, C6 | 10uF | Device:CP | Capacitor_THT:CP_Radial_D5.0mm_P2.50mm
3 | 1 | J1 | card addr | Connector_Generic:Conn_02x04_Odd_Even | Connector_PinHeader_2.54mm:PinHeader_2x04_P2.54mm_Vertical | ~
4 | 1 | J2 | Power Bus | Connector_Generic:Conn_02x05_Odd_Even | Connector_PinHeader_2.54mm:PinHeader_2x05_P2.54mm_Vertical | ~
5 | 1 | J3 | Signal Bus | Connector_Generic:Conn_02x20_Odd_Even | Connector_PinHeader_2.54mm:PinHeader_2x20_P2.54mm_Vertical | ~
6 | 2 | Q1, Q3 | BC547 | Transistor_BJT:BC547 | Package_TO_SOT_THT:TO-92_Inline | http://www.fairchildsemi.com/ds/BC/BC547.pdf
7 | 2 | Q2, Q4 | BC328 | Transistor_BJT:BC328 | Package_TO_SOT_THT:TO-92_Inline | http://www.redrok.com/PNP_BC327_-45V_-800mA_0.625W_Hfe100_TO-92.pdf
8 | 2 | R1, R3 | 82k | Device:R | Resistor_THT:R_Axial_DIN0207_L6.3mm_D2.5mm_P7.62mm_Horizontal | ~
9 | 2 | R2, R4 | 12k | Device:R | Resistor_THT:R_Axial_DIN0207_L6.3mm_D2.5mm_P7.62mm_Horizontal | ~
10 | 1 | R5 | 10k | Device:R | Resistor_THT:R_Axial_DIN0207_L6.3mm_D2.5mm_P7.62mm_Horizontal | ~
11 | 2 | R6, R7 | 10k | Device:R |  | ~
12 | 1 | RN1 | 4x10k | Device:R_Network04 | Resistor_THT:R_Array_SIP5 | http://www.vishay.com/docs/31509/csc.pdf
13 | 1 | U1 | 74LS85 | 74xx:74LS85 | Package_DIP:DIP-16_W7.62mm_Socket_LongPads | http://www.ti.com/lit/gpn/sn74LS85
14 | 1 | U2 | 74LS04 | 74xx:74LS04 | Package_DIP:DIP-14_W7.62mm_Socket_LongPads | http://www.ti.com/lit/gpn/sn74LS04
15 | 1 | U3 | 8255A | Interface:8255A | Package_DIP:DIP-40_W15.24mm | http://aturing.umcs.maine.edu/~meadow/courses/cos335/Intel8255A.pdf
16 | 1 | U4 | AT89C4051-24P | MCU_Microchip_8051:AT89C4051-24P | Package_DIP:DIP-20_W7.62mm | http://ww1.microchip.com/downloads/en/DeviceDoc/doc1001.pdf
17 | 1 | U5 | 74LS04 | 74xx:74LS04 |  | http://www.ti.com/lit/gpn/sn74LS04

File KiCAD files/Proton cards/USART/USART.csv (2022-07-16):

Source: | C:\Users\kaltc\Documents\GitHub\Z80_Modular_Computer\KiCAD files\USART\USART.kicad_sch
Date: | 16/07/2022 8:11:27
Tool: | Eeschema (6.0.4)
Generator: | C:\Program Files\KiCad\6.0\bin\scripting\plugins/bom_csv_grouped_by_value.py
Component Count: | 40
Individual Components:
Item | Qty | Reference(s) | Value | LibPart | Footprint | Datasheet
 |  | C1 | 22pF | Device:C |  | ~
 |  | C2 | 1uF | Device:C_Polarized |  | ~
 |  | C3 | 1uF | Device:C_Polarized |  | ~
 |  | C4 | 1uF | Device:C_Polarized |  | ~
 |  | C5 | 1uF | Device:C_Polarized |  | ~
 |  | C6 | 1uF | Device:C_Polarized |  | ~
 |  | C7 | 100nF | Device:C |  | ~
 |  | C9 | 10uF | Device:C_Polarized |  | ~
 |  | C10 | 10nF | Device:C |  | ~
 |  | D1 | LED | Device:LED |  | ~
 |  | D2 | LED | Device:LED |  | ~
 |  | J1 | Card addr | Connector_Generic:Conn_02x04_Odd_Even |  | ~
 |  | J2 | Power Bus | Connector_Generic:Conn_02x05_Odd_Even |  | ~
 |  | J3 | Signal Buss | Connector_Generic:Conn_02x20_Odd_Even |  | ~
 |  | J4 | RS232 | Connector:DB9_Male |  | ~
 |  | J5 | INT enable | Connector_Generic:Conn_02x01 |  | ~
 |  | J6 | baud rate | Connector_Generic:Conn_01x03 |  | ~
 |  | J7 | Conn_01x03 | Connector_Generic:Conn_01x03 |  | ~
 |  | J8 | Conn_01x04 | Connector_Generic:Conn_01x04 |  | ~
 |  | Q1 | BC328 | Transistor_BJT:BC328 | Package_TO_SOT_THT:TO-92_Inline | http://www.redrok.com/PNP_BC327_-45V_-800mA_0.625W_Hfe100_TO-92.pdf
 |  | Q2 | BC328 | Transistor_BJT:BC328 | Package_TO_SOT_THT:TO-92_Inline | http://www.redrok.com/PNP_BC327_-45V_-800mA_0.625W_Hfe100_TO-92.pdf
 |  | Q3 | BC547 | Transistor_BJT:BC547 | Package_TO_SOT_THT:TO-92_Inline | http://www.fairchildsemi.com/ds/BC/BC547.pdf
 |  | R1 | 10k | Device:R |  | ~
 |  | R2 | 10k | Device:R |  | ~
 |  | R3 | 10k | Device:R |  | ~
 |  | R4 | 10k | Device:R |  | ~
 |  | R5 | 180 | Device:R |  | ~
 |  | R6 | 3k3 | Device:R |  | ~
 |  | R7 | 180 | Device:R |  | ~
 |  | R8 | 330 | Device:R |  | ~
 |  | R9 | 3k3 | Device:R |  | ~
 |  | R10 | 330 | Device:R |  | ~
 |  | R11 | 22k | Device:R |  | ~
 |  | R12 | 10k | Device:R |  | ~
 |  | U1 | 74LS04 | 74xx:74LS04 |  | http://www.ti.com/lit/gpn/sn74LS04
 |  | U2 | 74LS85 | 74xx:74LS85 |  | http://www.ti.com/lit/gpn/sn74LS85
 |  | U3 | 8251 | USART_8251:8251 | Package_DIP:DIP-28_W15.24mm
 |  | U4 | 74LS74 | 74xx:74LS74 |  | 74xx/74hc_hct74.pdf
 |  | U5 | MAX232 | Interface_UART:MAX232 |  | http://www.ti.com/lit/ds/symlink/max232.pdf
 |  | Y1 | 2.4576MHz | Device:Crystal |  | ~
Collated Components:
Item | Qty | Reference(s) | Value | LibPart | Footprint | Datasheet
1 | 1 | C1 | 22pF | Device:C |  | ~
2 | 5 | C2, C3, C4, C5, C6 | 1uF | Device:C_Polarized |  | ~
3 | 1 | C7 | 100nF | Device:C |  | ~
4 | 1 | C9 | 10uF | Device:C_Polarized |  | ~
5 | 1 | C10 | 10nF | Device:C |  | ~
6 | 2 | D1, D2 | LED | Device:LED |  | ~
7 | 1 | J1 | Card addr | Connector_Generic:Conn_02x04_Odd_Even |  | ~
8 | 1 | J2 | Power Bus | Connector_Generic:Conn_02x05_Odd_Even |  | ~
9 | 1 | J3 | Signal Buss | Connector_Generic:Conn_02x20_Odd_Even |  | ~
10 | 1 | J4 | RS232 | Connector:DB9_Male |  | ~
11 | 1 | J5 | INT enable | Connector_Generic:Conn_02x01 |  | ~
12 | 1 | J6 | baud rate | Connector_Generic:Conn_01x03 |  | ~
13 | 1 | J7 | Conn_01x03 | Connector_Generic:Conn_01x03 |  | ~
14 | 1 | J8 | Conn_01x04 | Connector_Generic:Conn_01x04 |  | ~
15 | 2 | Q1, Q2 | BC328 | Transistor_BJT:BC328 | Package_TO_SOT_THT:TO-92_Inline | http://www.redrok.com/PNP_BC327_-45V_-800mA_0.625W_Hfe100_TO-92.pdf
16 | 1 | Q3 | BC547 | Transistor_BJT:BC547 | Package_TO_SOT_THT:TO-92_Inline | http://www.fairchildsemi.com/ds/BC/BC547.pdf
17 | 5 | R1, R2, R3, R4, R12 | 10k | Device:R |  | ~
18 | 2 | R5, R7 | 180 | Device:R |  | ~
19 | 2 | R6, R9 | 3k3 | Device:R |  | ~
20 | 2 | R8, R10 | 330 | Device:R |  | ~
21 | 1 | R11 | 22k | Device:R |  | ~
22 | 1 | U1 | 74LS04 | 74xx:74LS04 |  | http://www.ti.com/lit/gpn/sn74LS04
23 | 1 | U2 | 74LS85 | 74xx:74LS85 |  | http://www.ti.com/lit/gpn/sn74LS85
24 | 1 | U3 | 8251 | USART_8251:8251 | Package_DIP:DIP-28_W15.24mm
25 | 1 | U4 | 74LS74 | 74xx:74LS74 |  | 74xx/74hc_hct74.pdf
26 | 1 | U5 | MAX232 | Interface_UART:MAX232 |  | http://www.ti.com/lit/ds/symlink/max232.pdf
27 | 1 | Y1 | 2.4576MHz | Device:Crystal |  | ~

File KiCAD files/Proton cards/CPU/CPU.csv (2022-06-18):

Item | Qty | Reference(s) | Value | LibPart | Footprint | Datasheet
1 | 3 | C1, C2, C3 | 10n | Device:C | Capacitor_THT:C_Disc_D3.8mm_W2.6mm_P2.50mm | ~
2 | 2 | C4, C7 | 10uF | Device:CP | Capacitor_THT:CP_Radial_D5.0mm_P2.50mm
3 | 1 | C5 | 22p | Device:C | Capacitor_THT:C_Disc_D3.8mm_W2.6mm_P2.50mm | ~
4 | 1 | C6 | 100n | Device:C | Capacitor_THT:C_Disc_D3.8mm_W2.6mm_P2.50mm | ~
5 | 2 | D1, D3 | LED | Device:LED | LED_THT:LED_D3.0mm | ~
6 | 1 | D2 | 1N4148 | Diode:1N4148 | Diode_THT:D_DO-35_SOD27_P7.62mm_Horizontal | https://assets.nexperia.com/documents/d-sheet/1N4148_1N4448.pdf
7 | 1 | J1 | Signal Bus | Connector_Generic:Conn_02x20_Odd_Even | Connector_PinHeader_2.54mm:PinHeader_2x20_P2.54mm_Vertical | ~
8 | 1 | J2 | Power Bus | Connector_Generic:Conn_02x05_Odd_Even | Connector_PinHeader_2.54mm:PinHeader_2x05_P2.54mm_Vertical | ~
9 | 1 | J3 | INT | Connector_Generic:Conn_02x01 | Connector_PinHeader_2.54mm:PinHeader_2x01_P2.54mm_Vertical | ~
10 | 1 | J4 | EXT RESET/INT | Connector_Generic:Conn_02x02_Odd_Even | Connector_PinHeader_2.54mm:PinHeader_2x02_P2.54mm_Vertical | ~
11 | 1 | J5 | Reset | Connector_Generic:Conn_02x01 | Connector_PinHeader_2.54mm:PinHeader_2x01_P2.54mm_Vertical | ~
12 | 1 | J6 | clock selector | Connector_Generic:Conn_02x03_Odd_Even | Connector_PinHeader_2.54mm:PinHeader_2x03_P2.54mm_Vertical | ~
13 | 1 | Q1 | BC328 | Transistor_BJT:BC328 | Package_TO_SOT_THT:TO-92_Inline | http://www.redrok.com/PNP_BC327_-45V_-800mA_0.625W_Hfe100_TO-92.pdf
14 | 2 | R1, R2 | 330R | Device:R | Resistor_THT:R_Axial_DIN0207_L6.3mm_D2.5mm_P10.16mm_Horizontal | ~
15 | 2 | R3, R6 | 270R | Device:R | Resistor_THT:R_Axial_DIN0207_L6.3mm_D2.5mm_P10.16mm_Horizontal | ~
16 | 1 | R4 | 100R | Device:R | Resistor_THT:R_Axial_DIN0207_L6.3mm_D2.5mm_P10.16mm_Horizontal | ~
17 | 1 | R5 | 1k | Device:R | Resistor_THT:R_Axial_DIN0207_L6.3mm_D2.5mm_P10.16mm_Horizontal | ~
18 | 1 | R7 | 3.3k | Device:R | Resistor_THT:R_Axial_DIN0207_L6.3mm_D2.5mm_P10.16mm_Horizontal | ~
19 | 1 | RN1 | 4x10k | Device:R_Network04 | Resistor_THT:R_Array_SIP5 | http://www.vishay.com/docs/31509/csc.pdf
20 | 1 | U1 | 74LS00 | 74xx:74LS00 | Package_DIP:DIP-14_W7.62mm_Socket_LongPads | http://www.ti.com/lit/gpn/sn74ls00
21 | 1 | U2 | 74LS74 | 74xx:74LS74 | Package_DIP:DIP-14_W7.62mm_Socket_LongPads | 74xx/74hc_hct74.pdf
22 | 1 | U3 | Z80CPU | CPU:Z80CPU | Package_DIP:DIP-40_W25.4mm_Socket_LongPads | www.zilog.com/manage_directlink.php?filepath=docs/z80/um0080
23 | 1 | Y1 | 4MHz | Device:Crystal_Small | Crystal:Crystal_HC49-U_Vertical | ~

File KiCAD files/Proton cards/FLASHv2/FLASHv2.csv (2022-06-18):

Item | Qty | Reference(s) | Value | LibPart | Footprint | Datasheet
1 | 1 | C1 | 10uF | Device:CP | Capacitor_THT:CP_Radial_D5.0mm_P2.50mm
2 | 5 | C2, C3, C4, C5, C6 | 10nF | Device:C | Capacitor_THT:C_Disc_D3.8mm_W2.6mm_P2.50mm | ~
3 | 1 | J1 | card addr | Connector_Generic:Conn_02x04_Odd_Even | Connector_PinHeader_2.54mm:PinHeader_2x04_P2.54mm_Vertical | ~
4 | 1 | J2 | Power Bus | Connector_Generic:Conn_02x05_Odd_Even | Connector_PinHeader_2.54mm:PinHeader_2x05_P2.54mm_Vertical | ~
5 | 1 | J3 | Signal Bus | Connector_Generic:Conn_02x20_Odd_Even | Connector_PinHeader_2.54mm:PinHeader_2x20_P2.54mm_Vertical | ~
6 | 1 | J4 | IDE connector | Connector_Generic:Conn_02x22_Odd_Even | Connector_PinHeader_2.00mm:PinHeader_2x22_P2.00mm_Vertical | ~
7 | 1 | R6 | 1k | Device:R | Resistor_THT:R_Axial_DIN0207_L6.3mm_D2.5mm_P10.16mm_Horizontal | ~
8 | 1 | RN1 | 4x10k | Device:R_Network04 | Resistor_THT:R_Array_SIP5 | http://www.vishay.com/docs/31509/csc.pdf
9 | 1 | U1 | 74LS04 | 74xx:74LS04 | Package_DIP:DIP-14_W7.62mm_Socket_LongPads | http://www.ti.com/lit/gpn/sn74LS04
10 | 1 | U2 | 74LS85 | 74xx:74LS85 | Package_DIP:DIP-16_W7.62mm_Socket_LongPads | http://www.ti.com/lit/gpn/sn74LS85
11 | 2 | U3, U4 | 74LS245 | 74xx:74LS245 | Package_DIP:DIP-20_W7.62mm_Socket_LongPads | http://www.ti.com/lit/gpn/sn74LS245

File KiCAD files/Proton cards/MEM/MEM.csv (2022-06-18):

Item | Qty | Reference(s) | Value | LibPart | Footprint | Datasheet
1 | 1 | C1 | 10uF | Device:CP | Capacitor_THT:CP_Radial_D5.0mm_P2.50mm
2 | 7 | C2, C3, C4, C5, C6, C7, C8 | 10nF | Device:C | Capacitor_THT:C_Disc_D3.8mm_W2.6mm_P2.50mm | ~
3 | 4 | D1, D2, D3, D4 | LED | Device:LED | LED_THT:LED_D3.0mm | ~
4 | 1 | J1 | card addr | Connector_Generic:Conn_02x04_Odd_Even | Connector_PinHeader_2.54mm:PinHeader_2x04_P2.54mm_Vertical | ~
5 | 1 | J2 | Power Bus | Connector_Generic:Conn_02x05_Odd_Even | Connector_PinHeader_2.54mm:PinHeader_2x05_P2.54mm_Vertical | ~
6 | 1 | J3 | Signal Bus | Connector_Generic:Conn_02x20_Odd_Even | Connector_PinHeader_2.54mm:PinHeader_2x20_P2.54mm_Vertical | ~
7 | 1 | J4 | RAM bank | Connector_Generic:Conn_02x03_Odd_Even | Connector_PinHeader_2.54mm:PinHeader_2x03_P2.54mm_Vertical | ~
8 | 1 | J5 | ROM block | Connector_Generic:Conn_02x02_Odd_Even | Connector_PinHeader_2.54mm:PinHeader_2x02_P2.54mm_Vertical | ~
9 | 2 | R1, R2 | 10k | Device:R | Resistor_THT:R_Axial_DIN0207_L6.3mm_D2.5mm_P10.16mm_Horizontal | ~
10 | 1 | RN1 | 4x10k | Device:R_Network04 | Resistor_THT:R_Array_SIP5 | http://www.vishay.com/docs/31509/csc.pdf
11 | 1 | RN2 | 4x220 | Device:R_Network04 | Resistor_THT:R_Array_SIP5 | http://www.vishay.com/docs/31509/csc.pdf
12 | 1 | U1 | 74LS139 | 74xx:74LS139 | Package_DIP:DIP-16_W7.62mm_Socket_LongPads | http://www.ti.com/lit/gpn/sn74LS139
13 | 1 | U2 | 74LS04 | 74xx:74LS04 | Package_DIP:DIP-14_W7.62mm_Socket_LongPads | http://www.ti.com/lit/gpn/sn74LS04
14 | 1 | U3 | 74LS74 | 74xx:74LS74 | Package_DIP:DIP-14_W7.62mm_Socket_LongPads | 74xx/74hc_hct74.pdf
15 | 1 | U4 | 74LS85 | 74xx:74LS85 | Package_DIP:DIP-16_W7.62mm_Socket_LongPads | http://www.ti.com/lit/gpn/sn74LS85
16 | 1 | U5 | SN74LS07N | 74xx:SN74LS07N | Package_DIP:DIP-14_W7.62mm_Socket_LongPads | www.ti.com/lit/ds/symlink/sn74ls07.pdf
17 | 1 | U6 | 628128 | Memory_RAM:628128_DIP32_SSOP32 | Package_DIP:DIP-32_W15.24mm_Socket_LongPads | http://www.futurlec.com/Datasheet/Memory/628128.pdf
18 | 1 | U7 | W27C512 | Memory_EPROM:27C512 | Socket:DIP_Socket-28_W11.9_W12.7_W15.24_W17.78_W18.5_3M_228-1277-00-0602J | http://ww1.microchip.com/downloads/en/DeviceDoc/doc0015.pdf

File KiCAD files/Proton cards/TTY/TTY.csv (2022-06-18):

Item | Qty | Reference(s) | Value | LibPart | Footprint | Datasheet
1 | 4 | C1, C2, C7, C8 | 22pF | Device:C | Capacitor_THT:C_Disc_D3.8mm_W2.6mm_P2.50mm | ~
2 | 1 | C3 | 10uF | Device:C_Polarized |  | ~
3 | 8 | C4, C5, C6, C9, C10, C11, C12, C13 | 10nF | Device:C | Capacitor_THT:C_Disc_D3.8mm_W2.6mm_P2.50mm | ~
4 | 5 | C14, C15, C16, C17, C18 | 1uF | Device:C_Polarized |  | ~
5 | 4 | D1, D2, D3, D4 | LED | Device:LED | LED_THT:LED_D3.0mm | ~
6 | 1 | J1 | Power Bus | Connector_Generic:Conn_02x05_Odd_Even | Connector_PinHeader_2.54mm:PinHeader_2x05_P2.54mm_Vertical | ~
7 | 1 | J2 | Signal Buss | Connector_Generic:Conn_02x20_Odd_Even | Connector_PinHeader_2.54mm:PinHeader_2x20_P2.54mm_Vertical | ~
8 | 2 | J3, J5 | TTL/RS232 | Connector_Generic:Conn_01x03 | Connector_PinHeader_2.54mm:PinHeader_1x03_P2.54mm_Vertical | ~
9 | 1 | J4 | Card addr | Connector_Generic:Conn_02x04_Odd_Even | Connector_PinHeader_2.54mm:PinHeader_2x04_P2.54mm_Vertical | ~
10 | 1 | J6 | TTY1 | Connector_Generic:Conn_02x03_Odd_Even | Connector_PinHeader_2.54mm:PinHeader_2x03_P2.54mm_Vertical | ~
11 | 1 | J7 | TTY0 | Connector_Generic:Conn_02x02_Odd_Even | Connector_PinHeader_2.54mm:PinHeader_2x02_P2.54mm_Vertical | ~
12 | 1 | J8 | DB9 | Connector:DB9_Male_MountingHoles | Connector_Dsub:DSUB-9_Male_Horizontal_P2.77x2.84mm_EdgePinOffset4.94mm_Housed_MountingHolesOffset7.48mm | ~
13 | 2 | RN1, RN2 | 4x10k | Device:R_Network04 | Resistor_THT:R_Array_SIP5 | http://www.vishay.com/docs/31509/csc.pdf
14 | 1 | RN3 | 4x220 | Device:R_Network04 | Resistor_THT:R_Array_SIP5 | http://www.vishay.com/docs/31509/csc.pdf
15 | 1 | U1 | 74LS07 | 74xx:74LS07 | Package_DIP:DIP-14_W7.62mm_Socket_LongPads | www.ti.com/lit/ds/symlink/sn74ls07.pdf
16 | 1 | U2 | 74LS74 | 74xx:74LS74 | Package_DIP:DIP-14_W7.62mm_Socket_LongPads | 74xx/74hc_hct74.pdf
17 | 2 | U3, U4 | ATmega328P-PU | TTY-rescue:ATmega328P-PU-MCU_Microchip_ATmega | Package_DIP:DIP-28_W7.62mm_Socket_LongPads | http://ww1.microchip.com/downloads/en/DeviceDoc/ATmega328_P%20AVR%20MCU%20with%20picoPower%20Technology%20Data%20Sheet%2040001984A.pdf
18 | 1 | U5 | 74LS08 | 74xx:74LS08 | Package_DIP:DIP-14_W7.62mm_Socket_LongPads | http://www.ti.com/lit/gpn/sn74LS08
19 | 1 | U6 | 74LS85 | 74xx:74LS85 | Package_DIP:DIP-16_W7.62mm_Socket_LongPads | http://www.ti.com/lit/gpn/sn74LS85
20 | 1 | U7 | 74LS00 | 74xx:74LS00 | Package_DIP:DIP-14_W7.62mm_Socket_LongPads | http://www.ti.com/lit/gpn/sn74ls00
21 | 1 | U8 | 74LS245 | 74xx:74LS245 | Package_DIP:DIP-20_W7.62mm_Socket_LongPads | http://www.ti.com/lit/gpn/sn74LS245
22 | 1 | U9 | MAX232 | Interface_UART:MAX232 | Package_DIP:DIP-16_W7.62mm_Socket_LongPads | http://www.ti.com/lit/ds/symlink/max232.pdf
23 | 2 | Y1, Y2 | 20MHz | Device:Crystal | Crystal:Crystal_HC49-U_Vertical | ~

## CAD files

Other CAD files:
CPM build/kbios2_0.obj
kbuild/kbios128.obj
Keil/clock/Objects/clock.obj
Keil/i2c_manager/Objects/i2c_manager.obj
Keil/square wave/Objects/sw10.obj
Monitor build/Monitor 1/kmonitor1_3.obj
Monitor build/Monitor 2/monitor_2_0.obj
Ride7/DO-8/DO-8.obj
Ride7/gpio_test/toggle_bit.obj
Ride7/serial_and_timer_test/serial_and_timer_test.obj
Ride7/serial_test/serial_test.obj
Ride7/timer-counter_test/timer-counter_test.obj
tasm32/diskboot.obj
CPM build/kbios128e.obj
Monitor build/Monitor 1/kmonitor1_2.obj
Monitor build/Monitor 2/monitor_2_3.obj
Ride7/gpio_test/flicker.obj
tasm32/kbios2_0_diskboot.obj
CPM build/kcpm221.obj
CPM build/romboot.obj
Monitor build/Monitor 1/mbios128.obj
Monitor build/Monitor 2/kbios128d.obj
Monitor build/Monitor 2/mbios2_0.obj
Monitor build/Monitor 2/romboot.obj

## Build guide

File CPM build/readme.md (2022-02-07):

## What you'll find in this directory ##
Here is all you need to put on the EEPROM to boot and run CP/M. We have:

- kbios2_0 - the customized BIOS for the Proton,
- kcpm221 - a slightly customized version of CP/M 2.2 and
- romboot - a small portion of software that transfers the BIOS and CP/M from EEPROM to RAM.

There are also some older versions of kbios and kcpm that I kept just for documentation reasons.

Special thanks to Grant Searle, from Wales, for his magnificent work on the BIOS, specially the disk functions, which I used as a starting point for my KBIOS.

For all of them, you'll find three kinds of files:

1) .ASM, the source file with syntax for TASM Z80 compiler.
2) .LST, the list result after compilation.
3) .OBJ, the HEX (Intel format) result after compilation.

So you have to put romboot.obj, kcpm221.obj and kbios2_0.obj on the EEPROM. How? Read the "Building Procedure" section in the Proton User's Manual. Be aware that the destination addresses are not the same seen in the HEX files. Depending on which ROM block will be used to boot, a displacement must be added.

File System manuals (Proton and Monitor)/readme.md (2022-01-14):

## What you'll find in this directory ##
Here are the user's manuals for the Monitor 2.3 and for the Proton.

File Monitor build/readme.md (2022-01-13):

## What you'll find in this directory ##
Go strait to subdirectory "Monitor 2". All you need to know about Monitor booting/running on Proton is there.

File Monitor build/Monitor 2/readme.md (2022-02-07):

## What you'll find in this directory ##
Here is all you need to put on the EEPROM to boot and run Monitor. We have:

- mbios2_0 - the customized BIOS for the Proton,
- monitor_2_3 - the latest version of Monitor and
- romboot - a small portion of software that transfers the BIOS and Monitor from EEPROM to RAM.

There are also some older versions of kbios and Monitor that I kept just for documentation reasons.

For all of them, you'll find three kinds of files:

1) .ASM, the source file with syntax for TASM Z80 compiler.
2) .LST, the list result after compilation.
3) .OBJ, the HEX (Intel format) result after compilation.

So you have to put romboot.obj, monitor_2_3.obj and mbios2_0.obj on the EEPROM. How? Read the "Building Procedure" section in the Proton User's Manual. Be aware that the destination addresses are not the same seen in the HEX files. Depending on which ROM block will be used to boot, a displacement must be added.

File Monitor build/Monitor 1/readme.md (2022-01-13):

## What you'll find in this directory ##
Don't waste your time here. Only old outdated stuff kept for sentimental reasons.

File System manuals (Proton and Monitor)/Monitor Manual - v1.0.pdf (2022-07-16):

# Monitor 2.3

# User’s Manual - version 1.0

# For use with the Proton Z80 Modular Computer

# Written by Ricardo Kaltchuk kaltchuk@gmail.com

# Index

Introduction | 3
Memory Commands | 5
READ aaaa | 5
WRITE aaaa,c1 c2 cN | 5
COPY aaaa-bbbb,cccc | 5
FILL aaaa-bbbb,cc | 6
COMPARE aaaa,bbbb | 6
HEX2COM aaaa | 6
RUN aaaa | 6
Disk Drive Commands | 7
DREAD d,ttt,ss | 7
DOWN d,ttt,ss | 8
UP d,ttt,ss | 8
VERIFY d | 8
FORMAT d | 9
FLASH | 9
Other Commands | 10
XMODEM r aaaa | 10
XMODEM s aaaa-bbbb | 10
BOOT | 10

# Introduction

Monitor is a very basic operating system designed for the Proton Z80 Modular Computer. It was intended to serve as a first way to interact with the hardware during the development of the Proton. It was crucial to test and implement the BIOS for CP/M.

Version 1.0 was monolithic and ran on ROM (bottom 16K) with 48KB of RAM and had a few basic memory access functions. Differently, version 2.0 was built with the same concept of CP/M, i.e. the Monitor per se and a BIOS, which is almost the same BIOS used by CP/M.

When Proton resets (cold boot), the bottom 16KB are allocated to ROM and the upper 48KB are allocated to RAM. Jumper J5 on MEM Card specifies which of the four ROM blocks will be used. Normally CP/M resides on block 0 and Monitor on block 1. The RAM bank is selected by jumper J4 on MEM Card.The bootloader copies the BIOS to RAM address E620h and the Monitor to RAM address D000h. The following diagram shows the memory allocation after boot is completed:

| Address
MBIOS | FFFF E620
MONITOR | D000
TPA | 0100
Page 0 | 0000

Page 0 is the first 256-byte block of memory and is used by the BIOS and the Monitor for information exchange and function calls. Please check the documentation on CP/M for details about page 0 and its structure. The Transient Program Area - TPA, is a block of almost 52KB, between page 0 and the Monitor, which can be used to store data and user-written programs.

After the bootloader copies the BIOS and the Monitor to RAM, it swaps to full RAM configuration, i.e, all 64KB become RAM. From this point on, Monitor is in control, exhibits a prompt (‘>’) and waits for a command.

Z80 Modular Computer by Kaltchuk 2020.
MBIOS 2.1.
Monitor by Kaltchuk 2020

>

If the user types “? <ENTER>”, the Monitor will show a list of all available commands.

>?

MONITOR 2.3 - Dec/2021.
Options: | READ aaaa | read from memory.
| WRITE aaaa,c1 c2 cN | write to memory.
| COPY aaaa-bbbb,cccc | copy memory block.
| FILL aaaa-bbbb,cc | fill memory block.
| COMPARE aaaa,bbbb | compare memory areas.
| FLASH | initialize Flash Card.
| DREAD d,ttt,ss | read from disk.
| DOWN d,ttt,ss | download one sector from disk.
| UP d,ttt,ss | upload one sector to disk.
| VERIFY d | verify disk.
| FORMAT d | format disk.
| XMODEM r aaaa | receive file using xmodem protocol.
| XMODEM s aaaa-bbbb | send memory block using xmodem protocol.
| HEX2COM aaaa | convert intel hex to executable.
| RUN aaaa | run program.
| BOOT | warm boot.

The following pages detail each command.

# Memory Commands

## READ aaaa

Read and display one memory block (256 bytes), starting from address “aaaa” (four characters in hexadecimal). After that, the user can type <ENTER> to read the next block or <ESC> to abort the command. Example:

>READ 0000
>ADDR: 00 01 02 03 04 05 06 07 08 09 0A 0B 0C 0D 0E 0F 0123456789ABCDEF >----- ----------------------------------------------- ----------------
>0000: C3 23 E6 00 00 C3 FF FF FF FF 7F FF FF FF FF FF .# |
>0010: FF 6D FF FE F4 EB 9E FB FD 3B 7E DD 67 BE FB FE .m.......;~.g... >0020: D7 DF F3 F9 DF FF FE FE FF 7B B7 FF FF FE FF BB .........{...... >0030: FF EF FF 58 EA FB FD DF DF FE 6A E7 A1 FF DD C7 ...X......j.....
>0040: 3E FF FE FF EF EF FF FF FF 7F FF FF FF FF FF 7F > |
>0050: 7D BF FE EA F6 DE 3F BD F3 7F DF 6B 9E AC FB F9 }.....?....k.... >0060: FF FF F7 DD 57 FF EA 7F FF 7F F9 C8 7E DD FE F8 ....W.......~... >0070: EF FA B5 FA DF EF 23 BD 6E CB B7 DB FB E8 77 13 ......#.n.....w. >0080: 52 45 41 44 20 30 30 30 30 00 30 2C 30 30 00 30 READ 0000.0,00.0 >0090: 30 00 7E BE FF E6 7F 5F FF DE F7 FE AE 8E BB F9 0.~...._........ >00A0: 7F FF FF BF DF ED FD FD 75 FA 5E 9F B7 FD FF E7 ........u.^..... >00B0: DE FF 7C 7D 3E DF B6 3F DE AB 33 4F BD FE D7 D7 ..|}>..?..3O....
>00C0: F7 FF B9 FE FD FF EB FF FF E7 F7 FD FD FE FF FF |
>00D0: FF 3B DF 9B FD FF F7 F7 DD FF FF 92 EF BF 3F F7 .; | ?.
>00E0: FF FD 7F AE EF BF FF FF FF 9D FF F1 BF BC 67 FB | g.
>00F0: 7F EB FE CB FE FF DD 1F 7A 2C 38 99 B1 B7 22 7B ........z,8..."{ >#================= <ENTER> = next page, <ESC> = quit =================#

## WRITE aaaa,c1 c2 cN

Write a list of bytes to memory, starting at address “aaaa” (four characters in hexadecimal). The bytes are all two characters hexadecimal separated by space. Example of use:

>WRITE 0200,21 7F A0 35

## COPY aaaa-bbbb,cccc

Copy a memory block, from address “aaaa” to “bbbb” (included), to address “cccc”. All addresses are four characters in hexadecimal. Example of use:

>COPY 0100-02FF,A000

## FILL aaaa-bbbb,cc

Fill a memory area, from address “aaaa” to “bbbb” (included), with byte “cc” (two characters hexadecimal). All addresses are four characters in hexadecimal. Example of use:

>FILL 1000-10FF,AA

## COMPARE aaaa,bbbb

Compare memory areas “aaaa” and “bbbb”, 16 bytes at a time and display the results. All addresses are four characters in hexadecimal. On the first line it prints the content of the first address and on the second line, the content of the second address. If the contents are equal it will print “=”, indicating that we have a match. After that, the user can type <ENTER> to compare the next line or <ESC> to abort the command. Example of use:

>COMPARE 0100 0200

>0100: F7 F7 FF FF FF FE FF FF FF FF FF DF BF FF FF FF >0200: F3 FF 6D == == FF == == EF == == FF FF == == ==
> | <ENTER> = next line, <ESC> = quit

## HEX2COM aaaa

Convert a program in Intel hex format, starting at memory address “aaaa”, to an executable program written to the address specified in the original hex file. Let's say that the user wrote an assembly program in Windows, with a text editor and compiled it with TASM, which generates a .OBJ file, in Intel hex format. This file can be downloaded to the Z80MC with XMODEM and converted to an executable with HEX2COM. Example of use:

>HEX2COM 1000

## RUN aaaa

Run (execute) a user written program, starting at address “aaaa” (four characters in hexadecimal). The user’s program should end with a jump to address 0000 (JP 0000), so a warm boot is performed and Monitor can resume command. Example of use:

>RUN 0200

# Disk Drive Commands

## DREAD d,ttt,ss

Read one sector (512 bytes) from disk “d”, starting at track “ttt” and sector “ss”. “d” must be one of the 16 drives, a letter from ‘a’ to ‘p’. “ttt” is a three character hexadecimal track, from 000 to 1FF; and “ss” is a two character hexadecimal sector, from 00 to 1F. Actually, this command copies the sector to RAM address E400h and shows the memory content like in the read command, but 32 lines at a time. Example of use:

>DREAD C,000,00
> DTS: C-0000-00 ,LBA: E0008000 (DISKPAD = E400)
>ADDR: 00 01 02 03 04 05 06 07 08 09 0A 0B 0C 0D 0E 0F 0123456789ABCDEF >----- ----------------------------------------------- ---------------->E000: 00 53 54 41 52 53 20 20 20 43 20 20 00 00 00 0E .STARS C ....
>E010: 04 00 00 00 00 00 00 00 00 00 00 00 00 00 00 00 |
>E020: 00 43 43 32 20 20 20 20 20 43 4F 4D 01 00 00 08 .CC2 COM....
>E030: 08 00 09 00 0A 00 0B 00 0C 00 00 00 00 00 00 00 |
>E040: 00 43 4C 49 4E 4B 20 20 20 43 4F 4D 00 00 00 2C .CLINK COM...,
>E050: 0D 00 0E 00 00 00 00 00 00 00 00 00 00 00 00 00 |
>E060: 00 43 20 20 20 20 20 20 20 43 43 43 00 00 00 0C .C | CCC....
>E070: 0F 00 00 00 00 00 00 00 00 00 00 00 00 00 00 00 |
>E080: 00 44 45 46 46 20 20 20 20 43 52 4C 00 00 00 60 .DEFF CRL...`
>E090: 10 00 11 00 12 00 00 00 00 00 00 00 00 00 00 00 |
>E0A0: 00 44 45 46 46 32 20 20 20 43 52 4C 00 00 00 2A .DEFF2 CRL...*
>E0B0: 13 00 14 00 00 00 00 00 00 00 00 00 00 00 00 00 |
>E0C0: 00 53 54 44 49 4F 20 20 20 48 20 20 00 00 00 0E .STDIO H ....
>E0D0: 15 00 00 00 00 00 00 00 00 00 00 00 00 00 00 00 |
>E0E0: 00 43 43 4F 4E 46 49 47 20 43 4F 4D 01 00 00 1C .CCONFIG COM....
>E0F0: 16 00 17 00 18 00 19 00 1A 00 00 00 00 00 00 00 |
>E100: 00 48 45 4C 4C 4F 20 20 20 43 20 20 00 00 00 02 .HELLO C ....
>E110: 1B 00 00 00 00 00 00 00 00 00 00 00 00 00 00 00 |
>E120: 00 48 45 4C 4C 4F 20 20 20 43 52 4C 00 00 00 06 .HELLO CRL....
>E130: 1C 00 00 00 00 00 00 00 00 00 00 00 00 00 00 00 |
>E140: 00 48 45 4C 4C 4F 20 20 20 43 4F 4D 00 00 00 1C .HELLO COM....
>E150: 1D 00 00 00 00 00 00 00 00 00 00 00 00 00 00 00 |
>E160: 00 53 54 41 52 53 20 20 20 43 52 4C 00 00 00 0F .STARS CRL....
>E170: 1E 00 00 00 00 00 00 00 00 00 00 00 00 00 00 00 |
>E180: 00 53 54 41 52 53 20 20 20 43 4F 4D 00 00 00 27 .STARS COM...'
>E190: 1F 00 20 00 00 00 00 00 00 00 00 00 00 00 00 00 |
>E1A0: 00 43 4C 49 42 20 20 20 20 43 4F 4D 00 00 00 2A .CLIB COM...*
>E1B0: 21 00 22 00 00 00 00 00 00 00 00 00 00 00 00 00 !." |
>E1C0: 00 44 20 20 20 20 20 20 20 43 4F 4D 00 00 00 0E .D | COM....
>E1D0: 2E 00 00 00 00 00 00 00 00 00 00 00 00 00 00 00 |
>E1E0: 00 54 41 52 47 45 54 20 20 43 20 20 00 00 00 1E .TARGET C ....
>E1F0: 29 00 00 00 00 00 00 00 00 00 00 00 00 00 00 00 ) |
>#================= <ENTER> = next page, <ESC> = quit =================#

## DOWN d,ttt,ss

Download one sector (512 bytes) from disk “d”, track “ttt”, sector “ss”. “d” must be one of the 16 drives, a letter from ‘a’ to ‘p’. “ttt” is a three character hexadecimal track, from 000 to 1FF; and “ss” is a two character hexadecimal sector, from 00 to 1F. The content is downloaded to RAM address E400h. Actually, this command does exactly the same as dread, but does not display the content, which can be read with a read e400 command. Example of use:

>DOWN P,0A5,1F

## UP d,ttt,ss

Upload one sector (512 bytes) from RAM E400h to disk “d”, track “ttt”, sector “ss”. “d” must be one of the 16 drives, a letter from ‘a’ to ‘p’. “ttt” is a three character hexadecimal track, from 000 to 1FF; and “ss” is a two character hexadecimal sector, from 00 to 1F. Example of use:

>UP C,002,0F

## VERIFY d

Verify the integrity of disk “d”. “d” must be one of the 16 drives, a letter from ‘a’ to ‘p’. This command is executed in four steps. First, the original content of the sector is copied to memory; second, the sector is written with a predefined sequence of characters; third, the sector is read again and compared with the written sequence; forth, the original content is uploaded back to the disk. In fact, steps 2 and 3 are executed four times, each time with a different pattern (00, FFh, 55h and AAh).

This command takes several minutes (23 minutes @ 8MHz) to verify all 16384 sectors of the selected disk. The operation can be aborted at any time by typing <ESC>. Example of use:

>VERIFY M

Track 0000 |
Track 0001 |
Track 0002 |
Track 0003 |
…
Track 01FC |
Track 01FD |
Track 01FE |
Track 01FF |
>

## FORMAT d

Format disk “d” using CP/M standard. “d” must be one of the 16 drives, a letter from ‘a’ to ‘p’. If drive ‘a’ is selected, the first track will be reserved and formatting will be performed on track 001. This is done so the user can write CP/M and the BIOS on track 000 for disk boot. This command does not erase the disk. It only initializes the file allocation table and makes the disk look empty if accessed by CP/M. Example of use:

>FORMAT M
Format drive M (y/n)? y
Format complete.
>

## FLASH

Initialize the Flash Card so it can be accessed by the CPU. The Monitor doesn't need a Flash Card to operate. If the BIOS tries to initialize the Flash Card during the boot and the card isn't present, it will block. Due to this fact, the BIOS does not initialize the Flash Card during the boot. A Flash Card initialization must be performed prior to any drive operation. All the commands that deal with drive operations (DREAD, UP, DOWN, VERIFY or FORMAT) check if the Flash Card has been initialized and automatically execute a FLASH command if necessary. This command only needs to be executed if a user-written program will be executed and no other disk drive
command has been executed after the last reset. If an operation on the compact flash is performed before initializing the Flash Card, the results are unpredictable and may eventually corrupt the data on the compact flash. Example of use:

>FLASH
FLASH Card initialized.
>

# Other Commands

## XMODEM r aaaa

or

## XMODEM s aaaa-bbbb

In the first form, a file is received using xmodem protocol and saved at RAM address “aaaa”. It is the user’s responsibility to assure that the data received will be written only inside the TPA.

In the second form, a block of memory, from “aaaa” to “bbbb”, is sent using xmodem protocol. All addresses are four characters in hexadecimal. Xmodem protocol works with blocks (records) of 128 bytes. So even if you want to send 1 byte to the host, actually 128 bytes will be sent.

Remember that Monitor is not a development platform, so it doesn't have a text editor nor a compiler; so any program that the user wants to run must be written on another computer, compiled and transferred to the Z80MC via the XMODEM command. (Unless you want to do it the hard way). Examples of use:

>XMODEM R 1000
File received.
>
>XMODEM S 1000-1100
File transmitted.
>

## BOOT

Performs a warm boot.

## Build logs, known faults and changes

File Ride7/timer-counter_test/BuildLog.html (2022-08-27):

----------------Make Started: 'timer-counter_test' in configuration 'Standard'--------------------------

Building C:\Users\kaltc\Documents\GitHub\Z80_Modular_Computer\Ride7\timer-counter_test\timer-counter_test.c

Running: 80C51 Compiler

"C:\Users\kaltc\Documents\Raisonance\Ride\Bin\RC51.EXE" "C:\Users\kaltc\Documents\GitHub\Z80_Modular_Computer\Ride7\timer-counter_test\timer-counter_test.c" QUIET GENERATEDEPFILE OJ("C:\Users\kaltc\Documents\GitHub\Z80_Modular_Computer\Ride7\timer-counter_test\timer-counter_test.obj") PIN("C:\Users\kaltc\Documents\Raisonance\Ride\Inc;C:\Users\kaltc\Documents\Raisonance\Ride\Inc\51") PIN("C:\Users\kaltc\Documents\Raisonance\Ride\\inc\51\Atmel") NOAM CD PR("C:\Users\kaltc\Documents\GitHub\Z80_Modular_Computer\Ride7\timer-counter_test\timer-counter_test.lst") FP(NOFLOAT) IP NOIS UNSIGNEDCHAR ET(CHAR) PR PL(60) PW(80) OE(1) OT("7","SPEED") RB("0") MAXERR("25") MAXWAR("25") SM MOD517(NODP8,NOAU)

RC51 COMPILER V06.20.17.263

Copyright (c) IoTize S.A.S. 1987-2017. All rights reserved. Raisonance is an IoTize brand.

RC51 COMPILATION COMPLETE. 0 WARNING, 0 ERROR

Building C:\Users\kaltc\Documents\GitHub\Z80_Modular_Computer\Ride7\timer-counter_test\timer-counter_test.rapp

Running: 80C51 Linker

"C:\Users\kaltc\Documents\Raisonance\Ride\Bin\LX51.EXE" "C:\Users\kaltc\Documents\GitHub\Z80_Modular_Computer\Ride7\timer-counter_test\timer-counter_test.obj" TO("C:\Users\kaltc\Documents\GitHub\Z80_Modular_Computer\Ride7\timer-counter_test\timer-counter_test.aof") LIBPATH("C:\Users\kaltc\Documents\Raisonance\Ride\Lib\51") GENERATEDEPFILE MAP IX RS(256) RSI(128) CSIZE(65536) XSIZE(65536) DEFN(XSTACKLEN,256) DEFN(TIM1_INIT,E8h) CO(0) DT(0) ID(0) XD(0) BI(0) ABSCODEOFFS(0) XMLM(No,"C:\Users\kaltc\Documents\GitHub\Z80_Modular_Computer\Ride7\timer-counter_test\timer-counter_test-modules.Standard.xml") XMLF(No,8000,"C:\Users\kaltc\Documents\GitHub\Z80_Modular_Computer\Ride7\timer-counter_test\timer-counter_test-flash.Standard.xml")

MS-DOS MCS-51 CODE BANKING LINKER/LOCATOR LX51 V06.20.17.263

Copyright (c) IoTize S.A.S. 1987-2017. All rights reserved. Raisonance is an IoTize brand.

LINK/LOCATE RUN COMPLETE, NO ERROR FOUND.

"C:\Users\kaltc\Documents\Raisonance\Ride\Bin\OH51.EXE" "C:\Users\kaltc\Documents\GitHub\Z80_Modular_Computer\Ride7\timer-counter_test\timer-counter_test.aof" HEXext

OMF to HEX/BIN converter V6.20.17.263

Copyright (c) IoTize S.A.S. 1987-2017. All rights reserved. Raisonance is an IoTize brand.

GENERATING EXTENDED HEX FILE: C:\USERS\KALTC\DOCUMENTS\GITHUB\Z80_MODULAR_COMPUTER\RIDE7\TIMER-COUNTER_TEST\TIMER-COUNTER_TEST.HEX

"C:\Users\kaltc\Documents\Raisonance\Ride\Bin\OH51.EXE" "C:\Users\kaltc\Documents\GitHub\Z80_Modular_Computer\Ride7\timer-counter_test\timer-counter_test.aof" BIN NOEVENODD

OMF to HEX/BIN converter V6.20.17.263

Copyright (c) IoTize S.A.S. 1987-2017. All rights reserved. Raisonance is an IoTize brand.

GENERATING BINARY FILE FOR PAGE 00 : C:\USERS\KALTC\DOCUMENTS\GITHUB\Z80_MODULAR_COMPUTER\RIDE7\TIMER-COUNTER_TEST\TIMER-COUNTER_TEST.BIN

=> Content from 0x0000 to 0x0030

Build successful

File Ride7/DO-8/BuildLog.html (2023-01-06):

----------------Make Started: 'DO-8' in configuration 'Standard'--------------------------

Building C:\Users\kaltc\Documents\GitHub\Z80_Modular_Computer\Ride7\DO-8\DO-8.c

Running: 80C51 Compiler

"C:\Users\kaltc\Documents\Raisonance\Ride\Bin\RC51.EXE" "C:\Users\kaltc\Documents\GitHub\Z80_Modular_Computer\Ride7\DO-8\DO-8.c" QUIET GENERATEDEPFILE OJ("C:\Users\kaltc\Documents\GitHub\Z80_Modular_Computer\Ride7\DO-8\DO-8.obj") PIN("C:\Users\kaltc\Documents\Raisonance\Ride\Inc;C:\Users\kaltc\Documents\Raisonance\Ride\Inc\51") PIN("C:\Users\kaltc\Documents\Raisonance\Ride\\inc\51") NOAM CD PR("C:\Users\kaltc\Documents\GitHub\Z80_Modular_Computer\Ride7\DO-8\DO-8.lst") FP(NOFLOAT) IP NOIS UNSIGNEDCHAR ET(CHAR) PR PL(60) PW(80) OE(1) OT("7","SPEED") RB("0") MAXERR("25") MAXWAR("25") SM MOD517(NODP8,NOAU)

RC51 COMPILER V06.20.17.263

Copyright (c) IoTize S.A.S. 1987-2017. All rights reserved. Raisonance is an IoTize brand.

*** WARNING C233 IN LINE 57 OF ModbusSlave.h : using absolute registers together with interrupts can cause register corruptions (mixup of register banks)

RC51 COMPILATION COMPLETE. 1 WARNING, 0 ERROR

Building C:\Users\kaltc\Documents\GitHub\Z80_Modular_Computer\Ride7\DO-8\DO-8.rapp

Running: 80C51 Linker

"C:\Users\kaltc\Documents\Raisonance\Ride\Bin\LX51.EXE" "C:\Users\kaltc\Documents\GitHub\Z80_Modular_Computer\Ride7\DO-8\DO-8.obj" TO("C:\Users\kaltc\Documents\GitHub\Z80_Modular_Computer\Ride7\DO-8\DO-8.aof") LIBPATH("C:\Users\kaltc\Documents\Raisonance\Ride\Lib\51") GENERATEDEPFILE MAP IX RS(256) RSI(128) CSIZE(65536) XSIZE(65536) DEFN(XSTACKLEN,256) DEFN(TIM1_INIT,E8h) CO(0) DT(0) ID(0) XD(0) BI(0) ABSCODEOFFS(0) XMLM(No,"C:\Users\kaltc\Documents\GitHub\Z80_Modular_Computer\Ride7\DO-8\DO-8-modules.Standard.xml") XMLF(No,8000,"C:\Users\kaltc\Documents\GitHub\Z80_Modular_Computer\Ride7\DO-8\DO-8-flash.Standard.xml")

MS-DOS MCS-51 CODE BANKING LINKER/LOCATOR LX51 V06.20.17.263

Copyright (c) IoTize S.A.S. 1987-2017. All rights reserved. Raisonance is an IoTize brand.

LINK/LOCATE RUN COMPLETE, NO ERROR FOUND.

"C:\Users\kaltc\Documents\Raisonance\Ride\Bin\OH51.EXE" "C:\Users\kaltc\Documents\GitHub\Z80_Modular_Computer\Ride7\DO-8\DO-8.aof" HEXext

OMF to HEX/BIN converter V6.20.17.263

Copyright (c) IoTize S.A.S. 1987-2017. All rights reserved. Raisonance is an IoTize brand.

GENERATING EXTENDED HEX FILE: C:\USERS\KALTC\DOCUMENTS\GITHUB\Z80_MODULAR_COMPUTER\RIDE7\DO-8\DO-8.HEX

"C:\Users\kaltc\Documents\Raisonance\Ride\Bin\OH51.EXE" "C:\Users\kaltc\Documents\GitHub\Z80_Modular_Computer\Ride7\DO-8\DO-8.aof" BIN NOEVENODD

OMF to HEX/BIN converter V6.20.17.263

Copyright (c) IoTize S.A.S. 1987-2017. All rights reserved. Raisonance is an IoTize brand.

GENERATING BINARY FILE FOR PAGE 00 : C:\USERS\KALTC\DOCUMENTS\GITHUB\Z80_MODULAR_COMPUTER\RIDE7\DO-8\DO-8.BIN

=> Content from 0x0000 to 0x0A50

Build successful

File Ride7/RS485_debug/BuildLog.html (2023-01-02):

----------------Make Started: 'RS485_debug' in configuration 'Standard'--------------------------

Building C:\Users\kaltc\Documents\GitHub\Z80_Modular_Computer\Ride7\RS485_debug\RS485_debug.c

Running: 80C51 Compiler

"C:\Users\kaltc\Documents\Raisonance\Ride\Bin\RC51.EXE" "C:\Users\kaltc\Documents\GitHub\Z80_Modular_Computer\Ride7\RS485_debug\RS485_debug.c" QUIET GENERATEDEPFILE OJ("C:\Users\kaltc\Documents\GitHub\Z80_Modular_Computer\Ride7\RS485_debug\RS485_debug.obj") PIN("C:\Users\kaltc\Documents\Raisonance\Ride\Inc;C:\Users\kaltc\Documents\Raisonance\Ride\Inc\51") PIN("C:\Users\kaltc\Documents\Raisonance\Ride\\inc\51") NOAM CD PR("C:\Users\kaltc\Documents\GitHub\Z80_Modular_Computer\Ride7\RS485_debug\RS485_debug.lst") FP(NOFLOAT) IP NOIS UNSIGNEDCHAR ET(CHAR) PR PL(60) PW(80) OE(1) OT("7","SPEED") RB("0") MAXERR("25") MAXWAR("25") SM MOD517(NODP8,NOAU)

RC51 COMPILER V06.20.17.263

Copyright (c) IoTize S.A.S. 1987-2017. All rights reserved. Raisonance is an IoTize brand.

*** WARNING C092 IN LINE 48 OF EEPROM.h : 'd' is declared but not used

*** WARNING C092 IN LINE 70 OF EEPROM.h : 'c' is declared but not used

*** WARNING C020 IN LINE 70 OF EEPROM.h : 'c' is assigned a value that is never used

*** WARNING C176 IN LINE 120 OF EEPROM.h : '|' : only one operand have bit type

*** WARNING C233 IN LINE 57 OF ModbusSlave.h : using absolute registers together with interrupts can cause register corruptions (mixup of register banks)

*** WARNING C092 IN LINE 72 OF ModbusSlave.h : 'kTO' is declared but not used

*** WARNING C020 IN LINE 72 OF ModbusSlave.h : 'kTO' is assigned a value that is never used

RC51 COMPILATION COMPLETE. 7 WARNINGS, 0 ERROR

Building C:\Users\kaltc\Documents\GitHub\Z80_Modular_Computer\Ride7\RS485_debug\RS485_debug.rapp

Running: 80C51 Linker

"C:\Users\kaltc\Documents\Raisonance\Ride\Bin\LX51.EXE" "C:\Users\kaltc\Documents\GitHub\Z80_Modular_Computer\Ride7\RS485_debug\RS485_debug.obj" TO("C:\Users\kaltc\Documents\GitHub\Z80_Modular_Computer\Ride7\RS485_debug\RS485_debug.aof") LIBPATH("C:\Users\kaltc\Documents\Raisonance\Ride\Lib\51") GENERATEDEPFILE MAP IX RS(256) RSI(128) CSIZE(65536) XSIZE(65536) DEFN(XSTACKLEN,256) DEFN(TIM1_INIT,E8h) CO(0) DT(0) ID(0) XD(0) BI(0) ABSCODEOFFS(0) XMLM(No,"C:\Users\kaltc\Documents\GitHub\Z80_Modular_Computer\Ride7\RS485_debug\RS485_debug-modules.Standard.xml") XMLF(No,8000,"C:\Users\kaltc\Documents\GitHub\Z80_Modular_Computer\Ride7\RS485_debug\RS485_debug-flash.Standard.xml")

MS-DOS MCS-51 CODE BANKING LINKER/LOCATOR LX51 V06.20.17.263

Copyright (c) IoTize S.A.S. 1987-2017. All rights reserved. Raisonance is an IoTize brand.

UNCALLED SEGMENTS:

?PR?serialRX?RS485_DEBUG

?PR?_wordRead?RS485_DEBUG

LINK/LOCATE RUN COMPLETE, NO ERROR FOUND.

"C:\Users\kaltc\Documents\Raisonance\Ride\Bin\OH51.EXE" "C:\Users\kaltc\Documents\GitHub\Z80_Modular_Computer\Ride7\RS485_debug\RS485_debug.aof" HEXext

OMF to HEX/BIN converter V6.20.17.263

Copyright (c) IoTize S.A.S. 1987-2017. All rights reserved. Raisonance is an IoTize brand.

GENERATING EXTENDED HEX FILE: C:\USERS\KALTC\DOCUMENTS\GITHUB\Z80_MODULAR_COMPUTER\RIDE7\RS485_DEBUG\RS485_DEBUG.HEX

"C:\Users\kaltc\Documents\Raisonance\Ride\Bin\OH51.EXE" "C:\Users\kaltc\Documents\GitHub\Z80_Modular_Computer\Ride7\RS485_debug\RS485_debug.aof" BIN NOEVENODD

OMF to HEX/BIN converter V6.20.17.263

Copyright (c) IoTize S.A.S. 1987-2017. All rights reserved. Raisonance is an IoTize brand.

GENERATING BINARY FILE FOR PAGE 00 : C:\USERS\KALTC\DOCUMENTS\GITHUB\Z80_MODULAR_COMPUTER\RIDE7\RS485_DEBUG\RS485_DEBUG.BIN

=> Content from 0x0000 to 0x0820

Build successful

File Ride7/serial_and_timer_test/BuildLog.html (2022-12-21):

----------------Make Started: 'serial_and_timer_test' in configuration 'Standard'--------------------------

Building C:\Users\kaltc\Documents\GitHub\Z80_Modular_Computer\Ride7\serial_and_timer_test\serial_and_timer_test.c

Running: 80C51 Compiler

"C:\Users\kaltc\Documents\Raisonance\Ride\Bin\RC51.EXE" "C:\Users\kaltc\Documents\GitHub\Z80_Modular_Computer\Ride7\serial_and_timer_test\serial_and_timer_test.c" QUIET GENERATEDEPFILE OJ("C:\Users\kaltc\Documents\GitHub\Z80_Modular_Computer\Ride7\serial_and_timer_test\serial_and_timer_test.obj") PIN("C:\Users\kaltc\Documents\Raisonance\Ride\Inc;C:\Users\kaltc\Documents\Raisonance\Ride\Inc\51") PIN("C:\Users\kaltc\Documents\Raisonance\Ride\\inc\51\Atmel") NOAM CD PR("C:\Users\kaltc\Documents\GitHub\Z80_Modular_Computer\Ride7\serial_and_timer_test\serial_and_timer_test.lst") FP(NOFLOAT) IP NOIS UNSIGNEDCHAR ET(CHAR) PR PL(60) PW(80) OE(1) OT("7","SPEED") RB("0") MAXERR("25") MAXWAR("25") SM MOD517(NODP8,NOAU)

RC51 COMPILER V06.20.17.263

Copyright (c) IoTize S.A.S. 1987-2017. All rights reserved. Raisonance is an IoTize brand.

*** WARNING C233 IN LINE 33 OF C:\Users\kaltc\Documents\GitHub\Z80_Modular_Computer\Ride7\serial_and_timer_test\serial_and_timer_test.c : using absolute registers together with interrupts can cause register corruptions (mixup of register banks)

RC51 COMPILATION COMPLETE. 1 WARNING, 0 ERROR

Building C:\Users\kaltc\Documents\GitHub\Z80_Modular_Computer\Ride7\serial_and_timer_test\serial_and_timer_test.rapp

Running: 80C51 Linker

"C:\Users\kaltc\Documents\Raisonance\Ride\Bin\LX51.EXE" "C:\Users\kaltc\Documents\GitHub\Z80_Modular_Computer\Ride7\serial_and_timer_test\serial_and_timer_test.obj" TO("C:\Users\kaltc\Documents\GitHub\Z80_Modular_Computer\Ride7\serial_and_timer_test\serial_and_timer_test.aof") LIBPATH("C:\Users\kaltc\Documents\Raisonance\Ride\Lib\51") GENERATEDEPFILE MAP IX RS(256) RSI(128) CSIZE(65536) XSIZE(65536) DEFN(XSTACKLEN,256) DEFN(TIM1_INIT,E8h) CO(0) DT(0) ID(0) XD(0) BI(0) ABSCODEOFFS(0) XMLM(No,"C:\Users\kaltc\Documents\GitHub\Z80_Modular_Computer\Ride7\serial_and_timer_test\serial_and_timer_test-modules.Standard.xml") XMLF(No,8000,"C:\Users\kaltc\Documents\GitHub\Z80_Modular_Computer\Ride7\serial_and_timer_test\serial_and_timer_test-flash.Standard.xml")

MS-DOS MCS-51 CODE BANKING LINKER/LOCATOR LX51 V06.20.17.263

Copyright (c) IoTize S.A.S. 1987-2017. All rights reserved. Raisonance is an IoTize brand.

LINK/LOCATE RUN COMPLETE, NO ERROR FOUND.

"C:\Users\kaltc\Documents\Raisonance\Ride\Bin\OH51.EXE" "C:\Users\kaltc\Documents\GitHub\Z80_Modular_Computer\Ride7\serial_and_timer_test\serial_and_timer_test.aof" HEXext

OMF to HEX/BIN converter V6.20.17.263

Copyright (c) IoTize S.A.S. 1987-2017. All rights reserved. Raisonance is an IoTize brand.

GENERATING EXTENDED HEX FILE: C:\USERS\KALTC\DOCUMENTS\GITHUB\Z80_MODULAR_COMPUTER\RIDE7\SERIAL_AND_TIMER_TEST\SERIAL_AND_TIMER_TEST.HEX

"C:\Users\kaltc\Documents\Raisonance\Ride\Bin\OH51.EXE" "C:\Users\kaltc\Documents\GitHub\Z80_Modular_Computer\Ride7\serial_and_timer_test\serial_and_timer_test.aof" BIN NOEVENODD

OMF to HEX/BIN converter V6.20.17.263

Copyright (c) IoTize S.A.S. 1987-2017. All rights reserved. Raisonance is an IoTize brand.

GENERATING BINARY FILE FOR PAGE 00 : C:\USERS\KALTC\DOCUMENTS\GITHUB\Z80_MODULAR_COMPUTER\RIDE7\SERIAL_AND_TIMER_TEST\SERIAL_AND_TIMER_TEST.BIN

=> Content from 0x0000 to 0x0062

Build successful

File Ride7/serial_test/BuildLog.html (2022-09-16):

----------------Make Started: 'serial_test' in configuration 'Standard'--------------------------

Building C:\Users\kaltc\Documents\GitHub\Z80_Modular_Computer\Ride7\serial_test\serial_test.c

Running: 80C51 Compiler

"C:\Users\kaltc\Documents\Raisonance\Ride\Bin\RC51.EXE" "C:\Users\kaltc\Documents\GitHub\Z80_Modular_Computer\Ride7\serial_test\serial_test.c" QUIET GENERATEDEPFILE OJ("C:\Users\kaltc\Documents\GitHub\Z80_Modular_Computer\Ride7\serial_test\serial_test.obj") PIN("C:\Users\kaltc\Documents\Raisonance\Ride\Inc;C:\Users\kaltc\Documents\Raisonance\Ride\Inc\51") PIN("C:\Users\kaltc\Documents\Raisonance\Ride\\inc\51\Atmel") NOAM CD PR("C:\Users\kaltc\Documents\GitHub\Z80_Modular_Computer\Ride7\serial_test\serial_test.lst") FP(NOFLOAT) IP NOIS UNSIGNEDCHAR ET(CHAR) PR PL(60) PW(80) OE(1) OT("7","SPEED") RB("0") MAXERR("25") MAXWAR("25") SM MOD517(NODP8,NOAU)

RC51 COMPILER V06.20.17.263

Copyright (c) IoTize S.A.S. 1987-2017. All rights reserved. Raisonance is an IoTize brand.

RC51 COMPILATION COMPLETE. 0 WARNING, 0 ERROR

Building C:\Users\kaltc\Documents\GitHub\Z80_Modular_Computer\Ride7\serial_test\serial_test.rapp

Running: 80C51 Linker

"C:\Users\kaltc\Documents\Raisonance\Ride\Bin\LX51.EXE" "C:\Users\kaltc\Documents\GitHub\Z80_Modular_Computer\Ride7\serial_test\serial_test.obj" TO("C:\Users\kaltc\Documents\GitHub\Z80_Modular_Computer\Ride7\serial_test\serial_test.aof") LIBPATH("C:\Users\kaltc\Documents\Raisonance\Ride\Lib\51") GENERATEDEPFILE MAP IX RS(256) RSI(128) CSIZE(65536) XSIZE(65536) DEFN(XSTACKLEN,256) DEFN(TIM1_INIT,E8h) CO(0) DT(0) ID(0) XD(0) BI(0) ABSCODEOFFS(0) XMLM(No,"C:\Users\kaltc\Documents\GitHub\Z80_Modular_Computer\Ride7\serial_test\serial_test-modules.Standard.xml") XMLF(No,8000,"C:\Users\kaltc\Documents\GitHub\Z80_Modular_Computer\Ride7\serial_test\serial_test-flash.Standard.xml")

MS-DOS MCS-51 CODE BANKING LINKER/LOCATOR LX51 V06.20.17.263

Copyright (c) IoTize S.A.S. 1987-2017. All rights reserved. Raisonance is an IoTize brand.

LINK/LOCATE RUN COMPLETE, NO ERROR FOUND.

"C:\Users\kaltc\Documents\Raisonance\Ride\Bin\OH51.EXE" "C:\Users\kaltc\Documents\GitHub\Z80_Modular_Computer\Ride7\serial_test\serial_test.aof" HEXext

OMF to HEX/BIN converter V6.20.17.263

Copyright (c) IoTize S.A.S. 1987-2017. All rights reserved. Raisonance is an IoTize brand.

GENERATING EXTENDED HEX FILE: C:\USERS\KALTC\DOCUMENTS\GITHUB\Z80_MODULAR_COMPUTER\RIDE7\SERIAL_TEST\SERIAL_TEST.HEX

"C:\Users\kaltc\Documents\Raisonance\Ride\Bin\OH51.EXE" "C:\Users\kaltc\Documents\GitHub\Z80_Modular_Computer\Ride7\serial_test\serial_test.aof" BIN NOEVENODD

OMF to HEX/BIN converter V6.20.17.263

Copyright (c) IoTize S.A.S. 1987-2017. All rights reserved. Raisonance is an IoTize brand.

GENERATING BINARY FILE FOR PAGE 00 : C:\USERS\KALTC\DOCUMENTS\GITHUB\Z80_MODULAR_COMPUTER\RIDE7\SERIAL_TEST\SERIAL_TEST.BIN

=> Content from 0x0000 to 0x005F

Build successful

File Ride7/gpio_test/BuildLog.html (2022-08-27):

----------------Make Started: 'gpio_test' in configuration 'Standard'--------------------------

Building C:\Users\kaltc\Documents\GitHub\Z80_Modular_Computer\Ride7\gpio_test\toggle_bit.c

Running: 80C51 Compiler

"C:\Users\kaltc\Documents\Raisonance\Ride\Bin\RC51.EXE" "C:\Users\kaltc\Documents\GitHub\Z80_Modular_Computer\Ride7\gpio_test\toggle_bit.c" QUIET GENERATEDEPFILE OJ("C:\Users\kaltc\Documents\GitHub\Z80_Modular_Computer\Ride7\gpio_test\toggle_bit.obj") PIN("C:\Users\kaltc\Documents\Raisonance\Ride\Inc;C:\Users\kaltc\Documents\Raisonance\Ride\Inc\51") PIN("C:\Users\kaltc\Documents\Raisonance\Ride\\inc\51") NOAM CD PR("C:\Users\kaltc\Documents\GitHub\Z80_Modular_Computer\Ride7\gpio_test\toggle_bit.lst") FP(NOFLOAT) IP NOIS UNSIGNEDCHAR ET(CHAR) PR PL(60) PW(80) OE(1) OT("7","SPEED") RB("0") MAXERR("25") MAXWAR("25") SM MOD517(NODP8,NOAU)

RC51 COMPILER V06.20.17.263

Copyright (c) IoTize S.A.S. 1987-2017. All rights reserved. Raisonance is an IoTize brand.

RC51 COMPILATION COMPLETE. 0 WARNING, 0 ERROR

Building C:\Users\kaltc\Documents\GitHub\Z80_Modular_Computer\Ride7\gpio_test\gpio_test.rapp

Running: 80C51 Linker

"C:\Users\kaltc\Documents\Raisonance\Ride\Bin\LX51.EXE" "C:\Users\kaltc\Documents\GitHub\Z80_Modular_Computer\Ride7\gpio_test\toggle_bit.obj" TO("C:\Users\kaltc\Documents\GitHub\Z80_Modular_Computer\Ride7\gpio_test\gpio_test.aof") LIBPATH("C:\Users\kaltc\Documents\Raisonance\Ride\Lib\51") GENERATEDEPFILE MAP IX RS(256) RSI(128) CSIZE(65536) XSIZE(65536) DEFN(XSTACKLEN,256) DEFN(TIM1_INIT,E8h) CO(0) DT(0) ID(0) XD(0) BI(0) ABSCODEOFFS(0) XMLM(No,"C:\Users\kaltc\Documents\GitHub\Z80_Modular_Computer\Ride7\gpio_test\gpio_test-modules.Standard.xml") XMLF(No,8000,"C:\Users\kaltc\Documents\GitHub\Z80_Modular_Computer\Ride7\gpio_test\gpio_test-flash.Standard.xml")

MS-DOS MCS-51 CODE BANKING LINKER/LOCATOR LX51 V06.20.17.263

Copyright (c) IoTize S.A.S. 1987-2017. All rights reserved. Raisonance is an IoTize brand.

LINK/LOCATE RUN COMPLETE, NO ERROR FOUND.

"C:\Users\kaltc\Documents\Raisonance\Ride\Bin\OH51.EXE" "C:\Users\kaltc\Documents\GitHub\Z80_Modular_Computer\Ride7\gpio_test\gpio_test.aof" HEXext

OMF to HEX/BIN converter V6.20.17.263

Copyright (c) IoTize S.A.S. 1987-2017. All rights reserved. Raisonance is an IoTize brand.

GENERATING EXTENDED HEX FILE: C:\USERS\KALTC\DOCUMENTS\GITHUB\Z80_MODULAR_COMPUTER\RIDE7\GPIO_TEST\GPIO_TEST.HEX

"C:\Users\kaltc\Documents\Raisonance\Ride\Bin\OH51.EXE" "C:\Users\kaltc\Documents\GitHub\Z80_Modular_Computer\Ride7\gpio_test\gpio_test.aof" BIN NOEVENODD

OMF to HEX/BIN converter V6.20.17.263

Copyright (c) IoTize S.A.S. 1987-2017. All rights reserved. Raisonance is an IoTize brand.

GENERATING BINARY FILE FOR PAGE 00 : C:\USERS\KALTC\DOCUMENTS\GITHUB\Z80_MODULAR_COMPUTER\RIDE7\GPIO_TEST\GPIO_TEST.BIN

=> Content from 0x0000 to 0x0029

Build successful

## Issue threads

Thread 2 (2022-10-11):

Feature request: Buy everything as a kit

LaneaLucy, 2022-10-11:
I would like to buy everything as a kit. It would be cool if this could be made possible

KALTCHUK, 2022-10-12:
Hi, Lanea. There is no kit, at least for now. If you want, I can guide you
through the whole process, with BOMs and diagrams. It requires some skills,
time and dedication.

Regards,

Eng.'. Ricardo Kaltchuk
+972 55 944 1669

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

LaneaLucy, 2022-10-12:
I would really like to buy every part as kit. Buy one thing and get everything. It would be ok to buy one kit per module, but not buy every part alone.

LaneaLucy, 2022-10-12:
Or at least a link that put everything you need into the shopping cart

KALTCHUK, 2022-10-13:
All the cards were manufactured by JLCPCB and all components were bought
from AliExpress, except the aluminum frames for the enclosure.

Besides that, you have to consider that the EEPROM (W27C512) has to be
programmed and also the microcontrollers (ATmega328 ) for the TTY Card
need the firmware that I wrote.

Regards,

Eng.'. Ricardo Kaltchuk
+972 55 944 1669

On Wed, Oct 12, 2022 at 11:12 PM Lanea Lucy ***@***.***>
wrote:

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

LaneaLucy, 2022-10-17:
I would like to buy the components from someone bigger like mouser, Conrad, reichelt or similar, so I don't need to wait for 3 months for them to arrive. Btw, can you give a estimate for the costs of everything?
And programming the 2 shouldn't be a problem for me.
I'm just a little bit lazy

KALTCHUK, 2022-10-19:
Not quite sure about the cost, but something around 10 - 15USD per module
would be my "educated" guess. So that would sum less than 100USD, without
the enclosure. Please consider that I'm using ALiExpress prices as a base.

Regards,

Eng.'. Ricardo Kaltchuk
+972 55 944 1669

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

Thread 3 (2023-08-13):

250kpbs for TTY Card is not usual

Mokona, 2023-08-13:
Hello,

while constructing the computer, I had problems (well, I still have) with the unusual 250kpbs speed that is programmed by default in the 328P. I've tried a couple of USB/TTL adapters and they don't seem to like that (with a logic analyser, the signals are ok, but that's not very practical to communicate with the computer).

Some tools (like minicom) don't even have this speed listed in their configuration.

I would suggest a default speed that is more usual (230400 ?). I haven't try it yet as I still need to figure out where to find Atmel Studio to recompile the 328P.

Mokona, 2023-08-13:
Btw, is the preTTY script in the Arduino scripts folder ok to use too? (that would be easier to use Arduino studio for me).

KALTCHUK, 2023-08-13:
Hi, Silvain.

It's a little bit more complicated. The time base for the USART in
ATMEGA is generated via the CPU clock (external xtal, 20MHz). Above
57.6kbps, the transmission error is quite big. If you change to 16MHz xtal,
the prescaller math will work better for some frequencies. It's a tradeoff.

I suggest you change the default baud rate to 57600bps, flash the
microcontroller and start experimenting with other baud rates. See page 21
of the Proton User's Manual (TTY Card).

Regards,

Eng.'. Ricardo Kaltchuk
+972 55 944 1669

On Sun, Aug 13, 2023 at 2:43 PM Sylvain Glaize ***@***.***>
wrote:

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

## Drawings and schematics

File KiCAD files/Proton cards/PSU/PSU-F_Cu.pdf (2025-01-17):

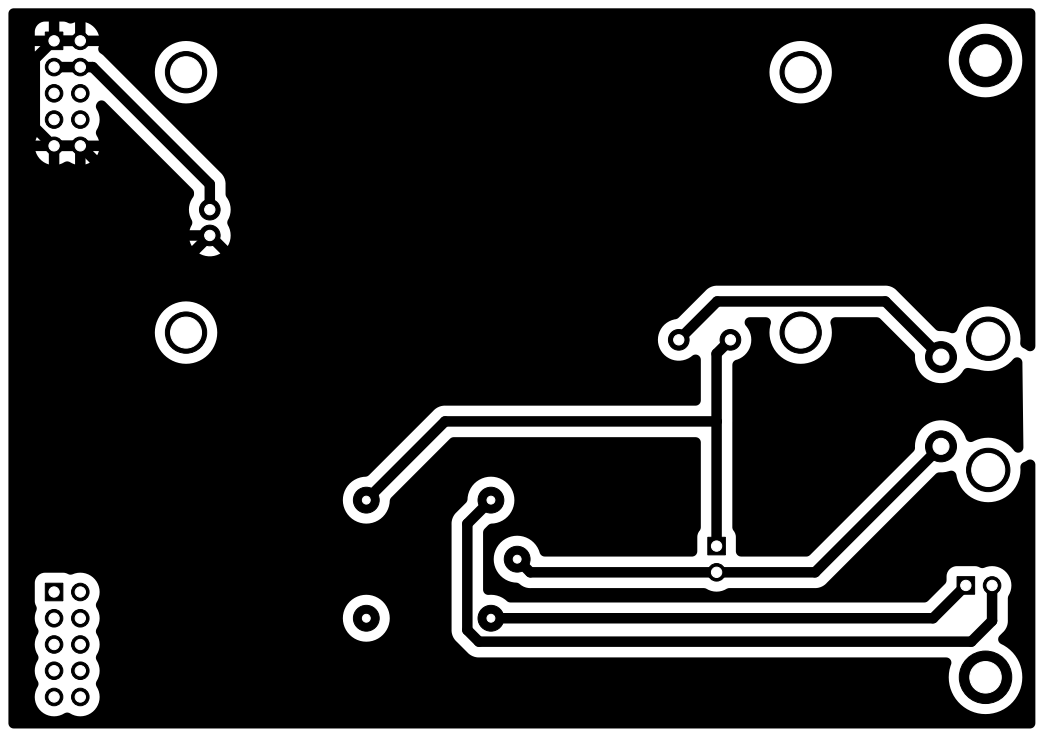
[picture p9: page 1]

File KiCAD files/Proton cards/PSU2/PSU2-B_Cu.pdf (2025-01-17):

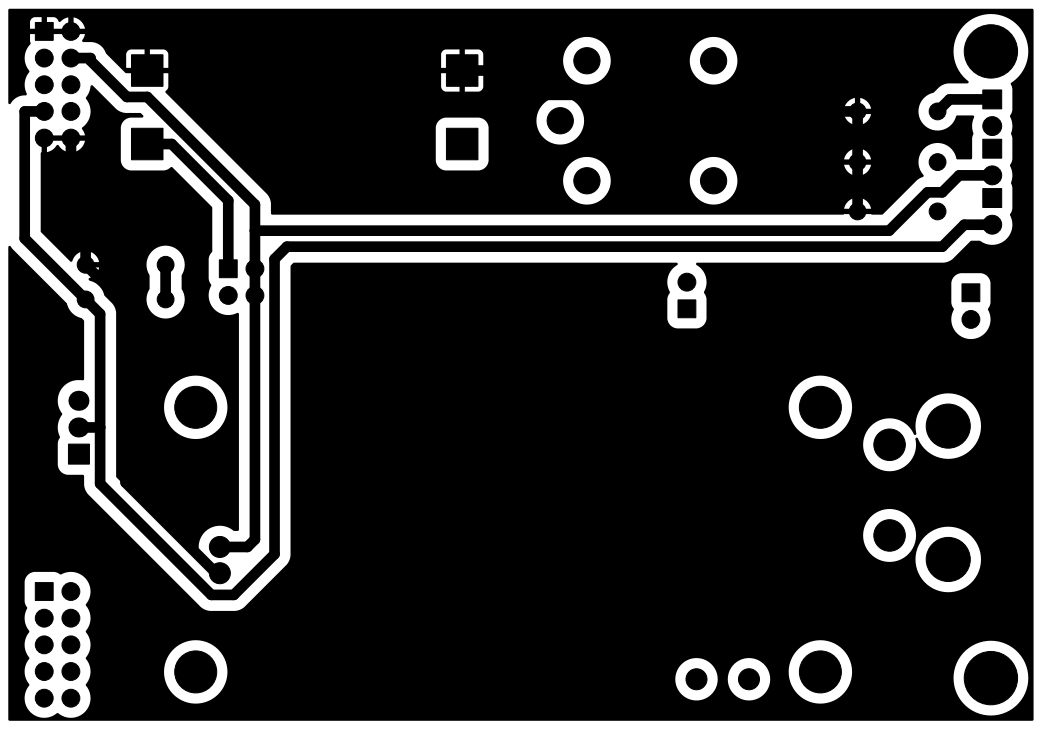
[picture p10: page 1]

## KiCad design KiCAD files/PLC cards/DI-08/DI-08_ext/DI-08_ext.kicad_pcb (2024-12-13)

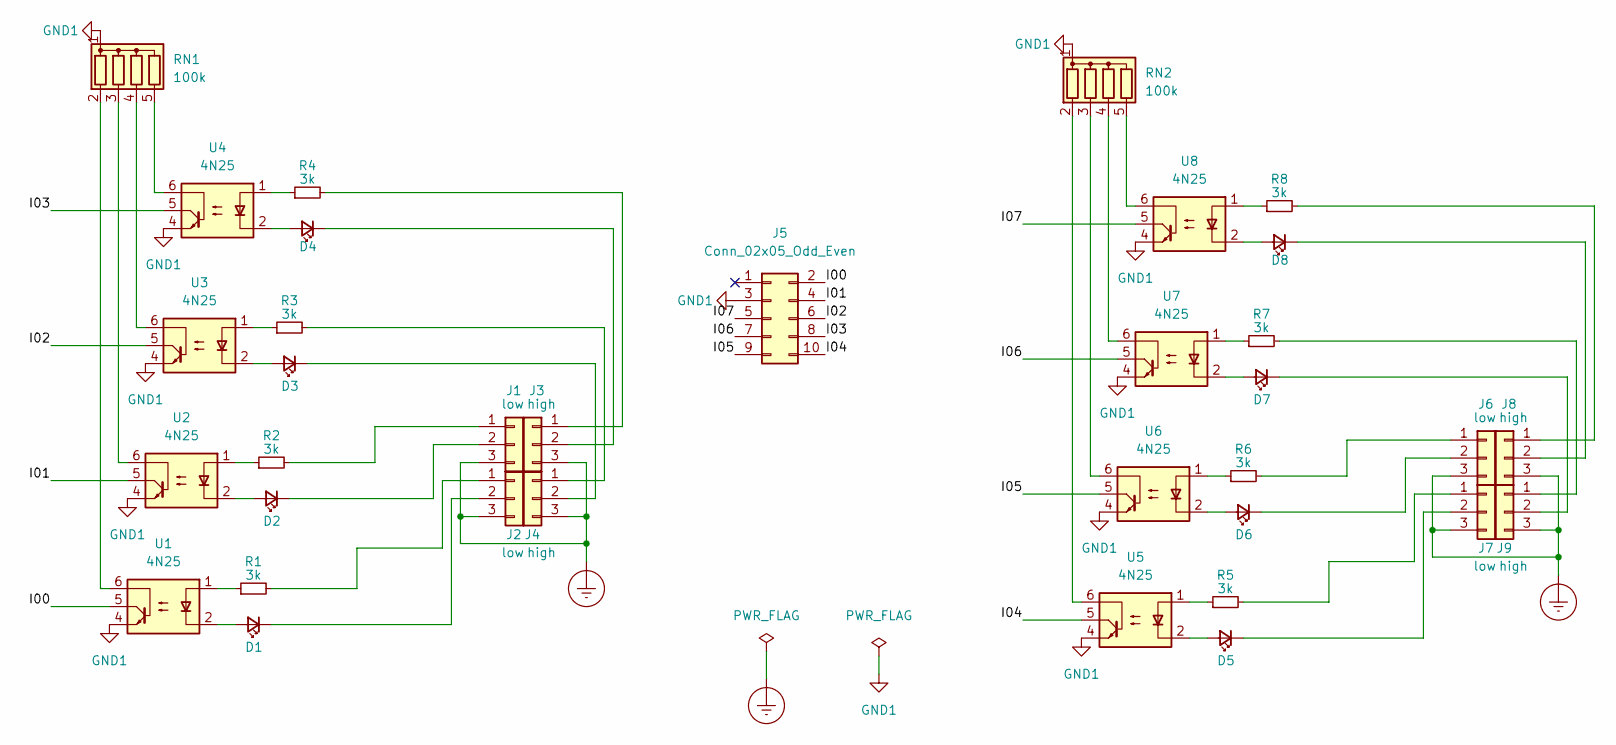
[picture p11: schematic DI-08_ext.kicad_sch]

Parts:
D1, D2, D3, D4, D5, D6, D7, D8: LED_Small; LED_D3.0mm
J1, J2, J6, J7: low; PhoenixContact_MSTBVA_2,5_3-G-5,08_1x03_P5.08mm_Vertical
J3, J4, J8, J9: high; PhoenixContact_MSTBVA_2,5_3-G-5,08_1x03_P5.08mm_Vertical
J5: Conn_02x05_Odd_Even; PinSocket_2x05_P2.54mm_Vertical
R1, R2, R3, R4, R5, R6, R7, R8: 3k; R_Axial_DIN0207_L6.3mm_D2.5mm_P2.54mm_Vertical
RN1, RN2: 100k; R_Array_SIP5
U1, U2, U3, U4, U5, U6, U7, U8: 4N25; DIP-6_W7.62mm_Socket_LongPads

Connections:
/I00: J5.2, U1.5
/I01: J5.4, U2.5
/I02: J5.6, U3.5
/I03: J5.8, U4.5
/I04: J5.10, U5.5
/I05: J5.9, U6.5
/I06: J5.7, U7.5
/I07: J5.5, U8.5
Earth_Protective: J1.3, J2.3, J3.3, J4.3, J6.3, J7.3, J8.3, J9.3
GND1: J5.3, RN1.1 (common), RN2.1 (common), U1.4, U2.4, U3.4, U4.4, U5.4, U6.4, U7.4, U8.4
unnamed: D1.1 (K), J2.2
unnamed: D1.2 (A), U1.2
unnamed: D2.1 (K), J1.2
unnamed: D2.2 (A), U2.2
unnamed: D3.1 (K), J4.2
unnamed: D3.2 (A), U3.2
unnamed: D4.1 (K), J3.2
unnamed: D4.2 (A), U4.2
unnamed: D5.1 (K), J7.2
unnamed: D5.2 (A), U5.2
unnamed: D6.1 (K), J6.2
unnamed: D6.2 (A), U6.2
unnamed: D7.1 (K), J9.2
unnamed: D7.2 (A), U7.2
unnamed: D8.1 (K), J8.2
unnamed: D8.2 (A), U8.2
unnamed: J1.1, R2.2
unnamed: J2.1, R1.2
unnamed: J3.1, R4.2
unnamed: J4.1, R3.2
unnamed: J6.1, R6.2
unnamed: J7.1, R5.2
unnamed: J8.1, R8.2
unnamed: J9.1, R7.2
unnamed: R1.1, U1.1
unnamed: R2.1, U2.1
unnamed: R3.1, U3.1
unnamed: R4.1, U4.1
unnamed: R5.1, U5.1
unnamed: R6.1, U6.1
unnamed: R7.1, U7.1
unnamed: R8.1, U8.1
unnamed: RN1.2 (R1), U1.6
unnamed: RN1.3 (R2), U2.6
unnamed: RN1.4 (R3), U3.6
unnamed: RN1.5 (R4), U4.6
unnamed: RN2.2 (R1), U5.6
unnamed: RN2.3 (R2), U6.6
unnamed: RN2.4 (R3), U7.6
unnamed: RN2.5 (R4), U8.6

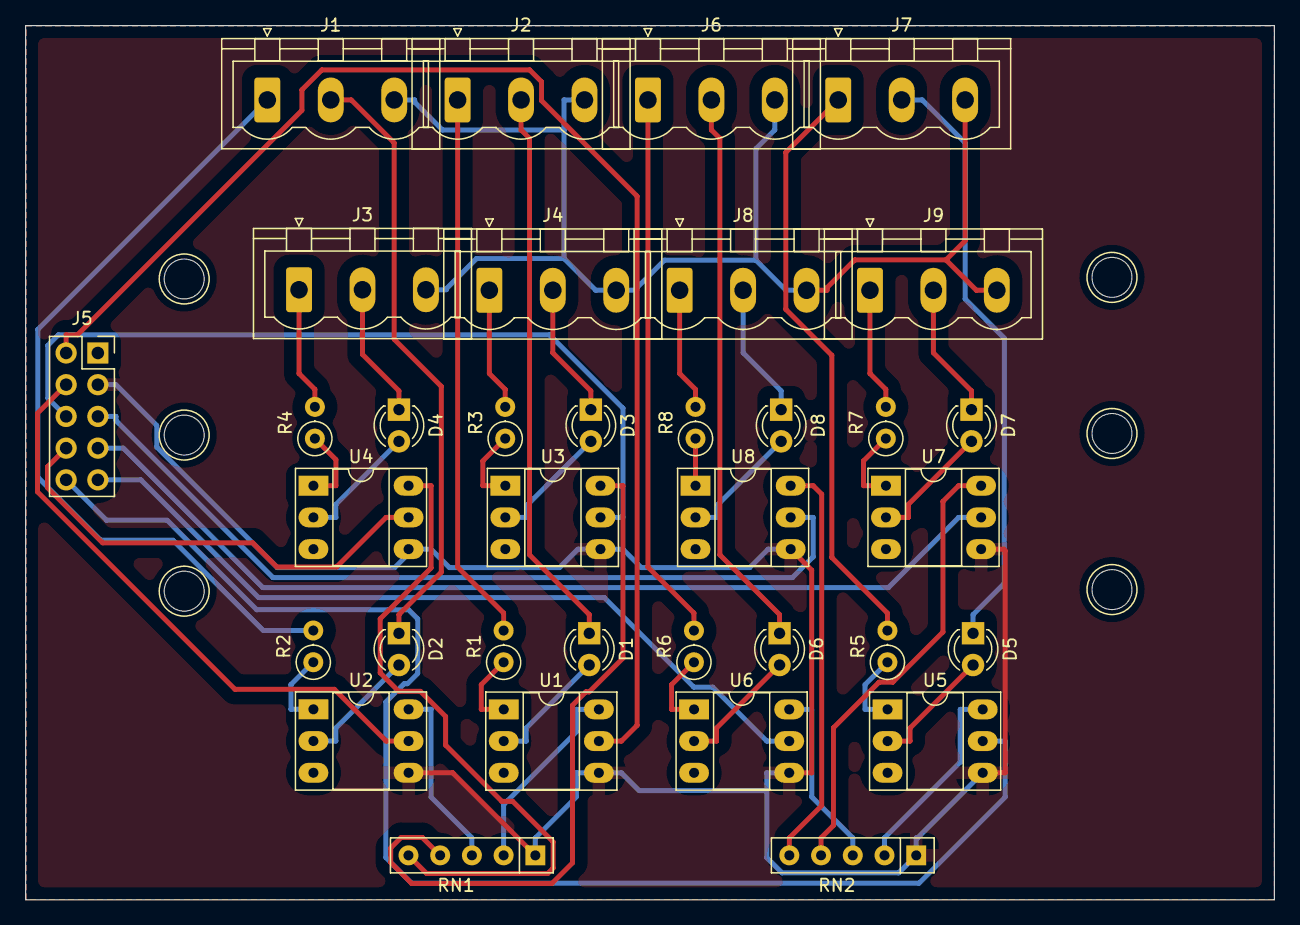
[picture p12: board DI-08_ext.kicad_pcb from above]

Board: 2 copper layers, 100.0 x 70.0 mm, 37 parts (0 on the bottom side), 50 nets.

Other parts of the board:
DRA1, DRA2: DIN_Rail_Adapter; DINRailAdapter_3xM3_PhoenixContact_1201578

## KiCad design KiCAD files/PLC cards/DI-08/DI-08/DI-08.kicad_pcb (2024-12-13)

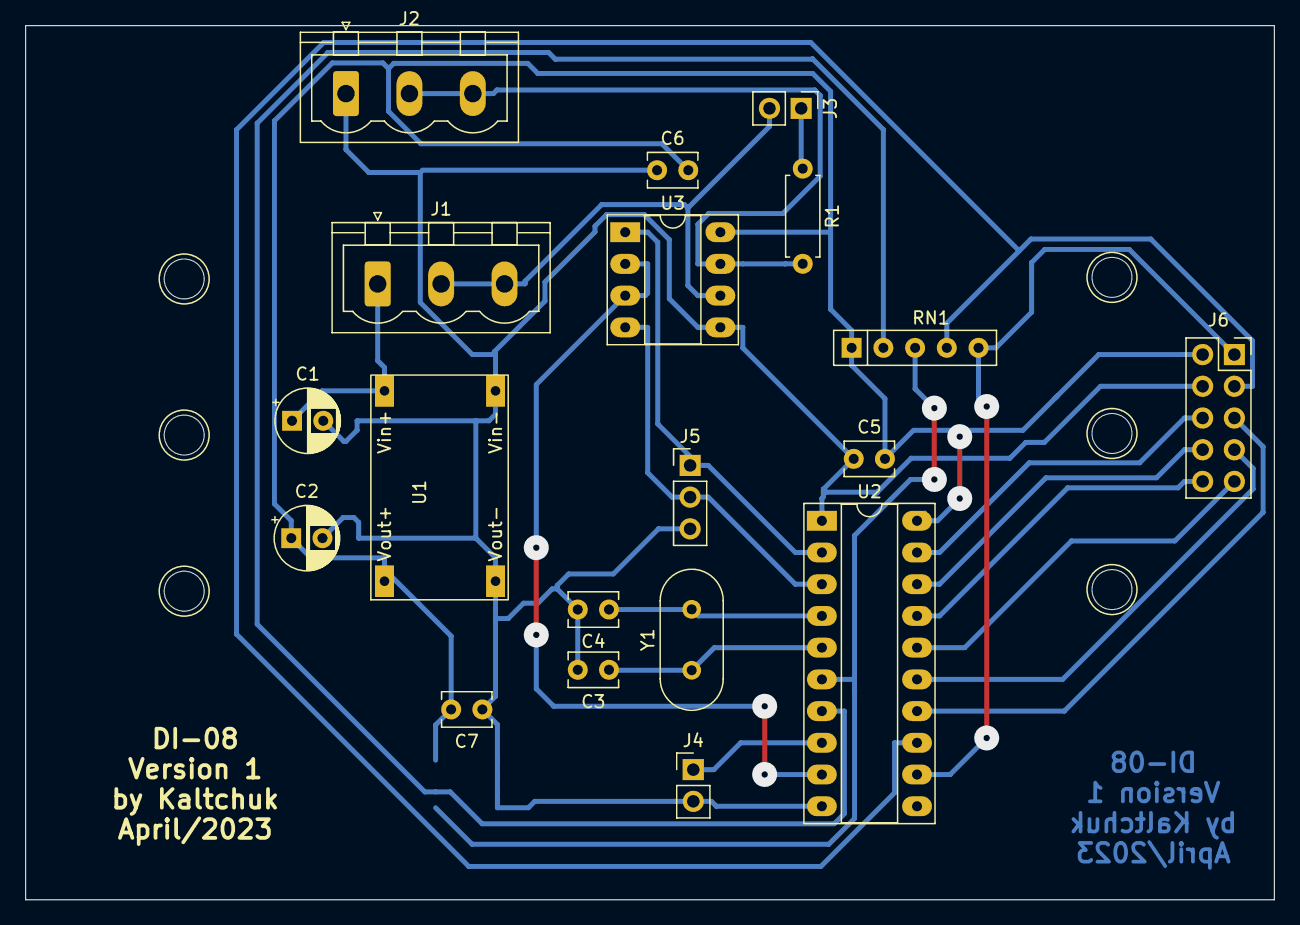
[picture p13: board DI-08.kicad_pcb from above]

Board: 2 copper layers, 100.0 x 70.0 mm, 22 parts (1 on the bottom side), 22 nets.

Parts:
C1: 47uF; CP_Radial_D5.0mm_P2.50mm
C2: 22uF; CP_Radial_D5.0mm_P2.50mm
C3, C4: 33pF; C_Disc_D3.8mm_W2.6mm_P2.50mm
C5, C6, C7: 10nF; C_Disc_D3.8mm_W2.6mm_P2.50mm
DRA1, DRA2: DIN_Rail_Adapter; DINRailAdapter_3xM3_PhoenixContact_1201578
J1: high; PhoenixContact_MSTBVA_2,5_3-G-5,08_1x03_P5.08mm_Vertical
J2: low; PhoenixContact_MSTBVA_2,5_3-G-5,08_1x03_P5.08mm_Vertical
J3: terminal; PinHeader_1x02_P2.54mm_Vertical
J4: factory setup; PinHeader_1x02_P2.54mm_Vertical
J5: TTL comm; PinHeader_1x03_P2.54mm_Vertical
J6: Bridge_female; PinSocket_2x05_P2.54mm_Vertical
R1: 250; R_Axial_DIN0207_L6.3mm_D2.5mm_P7.62mm_Horizontal
RN1: 10k; R_Array_SIP5
U1: DSN-MINI-360
U2: AT89C4051-24P; DIP-20_W7.62mm_Socket_LongPads
U3: SN75176AP; DIP-8_W7.62mm_Socket_LongPads
U4: FM24C64B; SOIC-8_3.9x4.9mm_P1.27mm
Y1: 11.059MHz; Crystal_HC49-U_Vertical

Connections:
+5V: C2.1, C5.2, C6.2, C7.2, J6.2, RN1.1 (common), U1.1 (Vout+), U2.20 (VCC), U3.8 (VCC), U4.8 (VDD)
+24V: C1.1, J1.1, U1.3 (Vin+)
/DE: U2.9 (P3.5), U3.2 (~RE), U3.3 (DE)
/FS: J4.1, U2.8 (P3.4)
/MB-A: J1.2, J1.3, J3.2, U3.6 (A)
/MB-B: J2.2, J2.3, R1.2, U3.7 (B)
/RX: J5.1, U2.2 (P3.0), U3.1 (R)
/SCL: RN1.2 (R1), U2.7 (P3.3), U4.6 (SCL)
/SDA: RN1.3 (R2), U2.6 (P3.2), U4.5 (SDA)
/TX: J5.2, U2.3 (P3.1), U3.4 (D)
GND: C1.2, C2.2, C3.2, C4.2, C5.1, C6.1, C7.1, J2.1, J4.2, J5.3, J6.4, U1.2 (Vout-), U1.4 (Vin-), U2.1 (RST/VPP), U2.10 (GND), U3.5 (GND), U4.1 (A0), U4.2 (A1), U4.3 (A2), U4.4 (VSS)
unnamed: C3.1, U2.5 (XTAL1), Y1.1
unnamed: C4.1, U2.4 (XTAL2), Y1.2
unnamed: J3.1, R1.1
unnamed: J6.1, RN1.5 (R4), U2.12 (P1.0)
unnamed: J6.3, RN1.4 (R3), U2.13 (P1.1)
unnamed: J6.5, U2.14 (P1.2)
unnamed: J6.6, U2.19 (P1.7)
unnamed: J6.7, U2.15 (P1.3)
unnamed: J6.8, U2.18 (P1.6)
unnamed: J6.9, U2.16 (P1.4)
unnamed: J6.10, U2.17 (P1.5)

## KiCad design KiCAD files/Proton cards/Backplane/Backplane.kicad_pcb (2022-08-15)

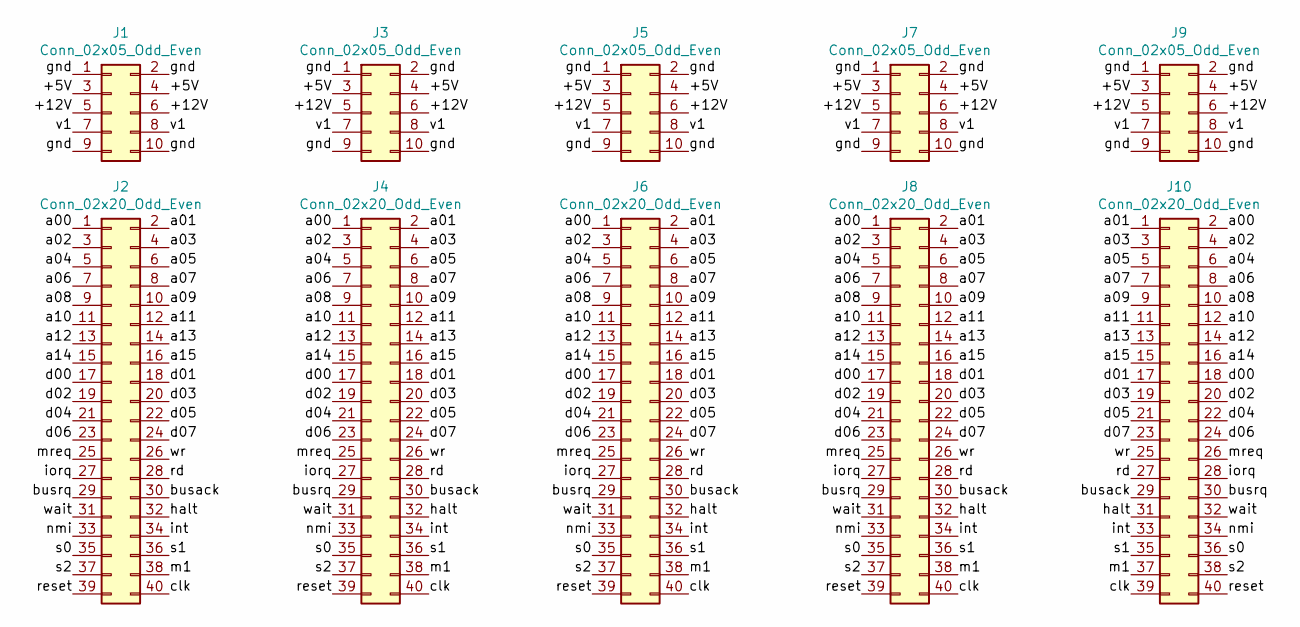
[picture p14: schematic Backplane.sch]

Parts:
J1, J9: Conn_02x05_Odd_Even; PinHeader_2x05_P2.54mm_Horizontal
J2, J10: Conn_02x20_Odd_Even; PinHeader_2x20_P2.54mm_Horizontal
J3, J5, J7: Conn_02x05_Odd_Even; PinHeader_2x05_P2.54mm_Vertical
J4, J6, J8: Conn_02x20_Odd_Even; PinHeader_2x20_P2.54mm_Vertical

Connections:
/+5V: J1.3, J1.4, J3.3, J3.4, J5.3, J5.4, J7.3, J7.4, J9.3, J9.4
/+12V: J1.5, J1.6, J3.5, J3.6, J5.5, J5.6, J7.5, J7.6, J9.5, J9.6
/a00: J2.1, J4.1, J6.1, J8.1, J10.2
/a01: J2.2, J4.2, J6.2, J8.2, J10.1
/a02: J2.3, J4.3, J6.3, J8.3, J10.4
/a03: J2.4, J4.4, J6.4, J8.4, J10.3
/a04: J2.5, J4.5, J6.5, J8.5, J10.6
/a05: J2.6, J4.6, J6.6, J8.6, J10.5
/a06: J2.7, J4.7, J6.7, J8.7, J10.8
/a07: J2.8, J4.8, J6.8, J8.8, J10.7
/a08: J2.9, J4.9, J6.9, J8.9, J10.10
/a09: J2.10, J4.10, J6.10, J8.10, J10.9
/a10: J2.11, J4.11, J6.11, J8.11, J10.12
/a11: J2.12, J4.12, J6.12, J8.12, J10.11
/a12: J2.13, J4.13, J6.13, J8.13, J10.14
/a13: J2.14, J4.14, J6.14, J8.14, J10.13
/a14: J2.15, J4.15, J6.15, J8.15, J10.16
/a15: J2.16, J4.16, J6.16, J8.16, J10.15
/busack: J2.30, J4.30, J6.30, J8.30, J10.29
/busrq: J2.29, J4.29, J6.29, J8.29, J10.30
/clk: J2.40, J4.40, J6.40, J8.40, J10.39
/d00: J2.17, J4.17, J6.17, J8.17, J10.18
/d01: J2.18, J4.18, J6.18, J8.18, J10.17
/d02: J2.19, J4.19, J6.19, J8.19, J10.20
/d03: J2.20, J4.20, J6.20, J8.20, J10.19
/d04: J2.21, J4.21, J6.21, J8.21, J10.22
/d05: J2.22, J4.22, J6.22, J8.22, J10.21
/d06: J2.23, J4.23, J6.23, J8.23, J10.24
/d07: J2.24, J4.24, J6.24, J8.24, J10.23
/gnd: J1.1, J1.2, J1.9, J1.10, J3.1, J3.2, J3.9, J3.10, J5.1, J5.2, J5.9, J5.10, J7.1, J7.2, J7.9, J7.10, J9.1, J9.2, J9.9, J9.10
/halt: J2.32, J4.32, J6.32, J8.32, J10.31
/int: J2.34, J4.34, J6.34, J8.34, J10.33
/iorq: J2.27, J4.27, J6.27, J8.27, J10.28
/mreq: J2.25, J4.25, J6.25, J8.25, J10.26
/nmi: J2.33, J4.33, J6.33, J8.33, J10.34
/rd: J2.28, J4.28, J6.28, J8.28, J10.27
/reset: J2.39, J4.39, J6.39, J8.39, J10.40
/s0: J2.35, J4.35, J6.35, J8.35, J10.36
/s1: J2.36, J4.36, J6.36, J8.36, J10.35
/s2: J2.37, J4.37, J6.37, J8.37, J10.38
/s3: J2.38, J4.38, J6.38, J8.38, J10.37
/v1: J1.7, J1.8, J3.7, J3.8, J5.7, J5.8, J7.7, J7.8, J9.7, J9.8
/wait: J2.31, J4.31, J6.31, J8.31, J10.32
/wr: J2.26, J4.26, J6.26, J8.26, J10.25

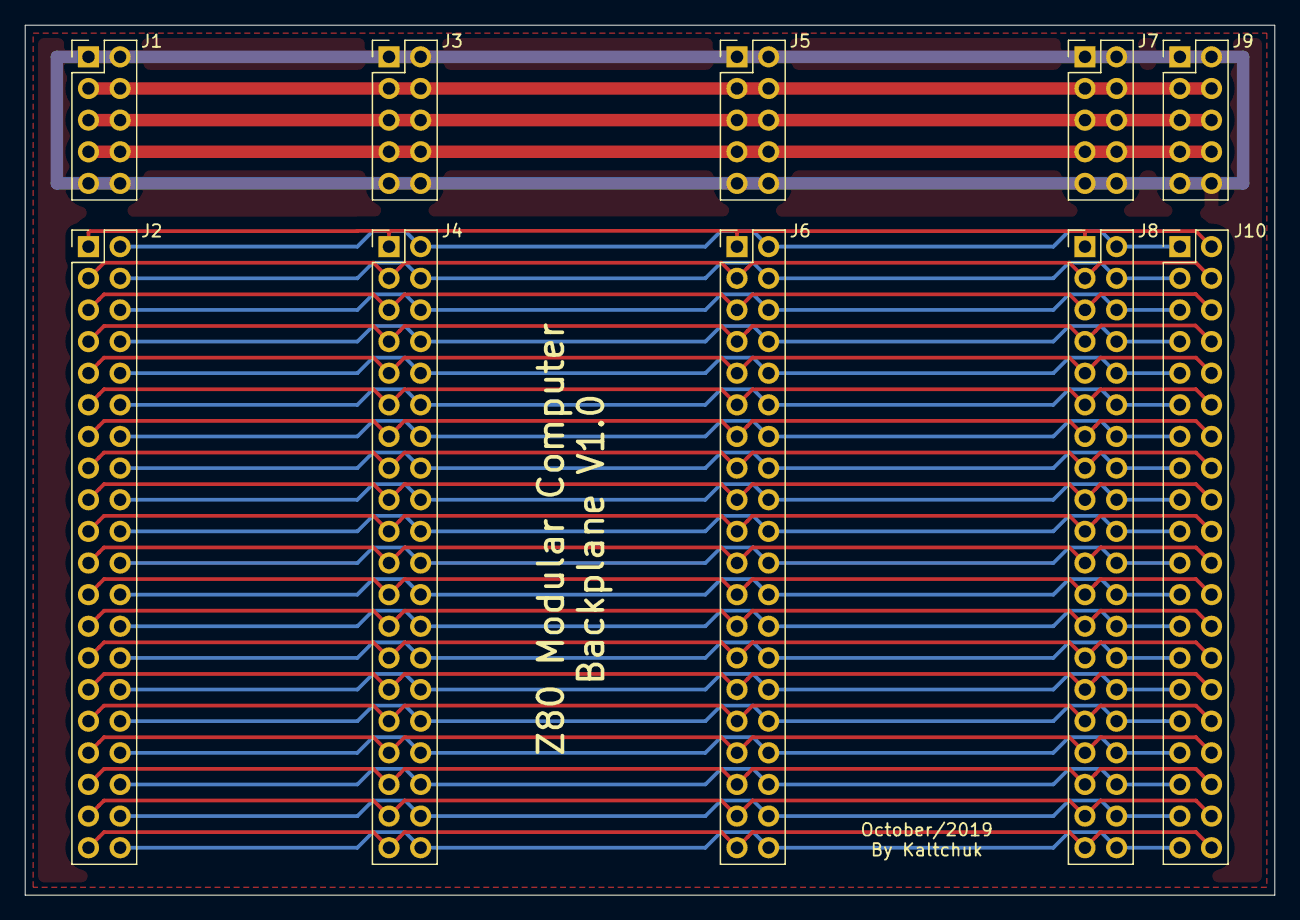
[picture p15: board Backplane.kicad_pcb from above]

Board: 2 copper layers, 100.3 x 69.8 mm, 10 parts (0 on the bottom side), 44 nets.

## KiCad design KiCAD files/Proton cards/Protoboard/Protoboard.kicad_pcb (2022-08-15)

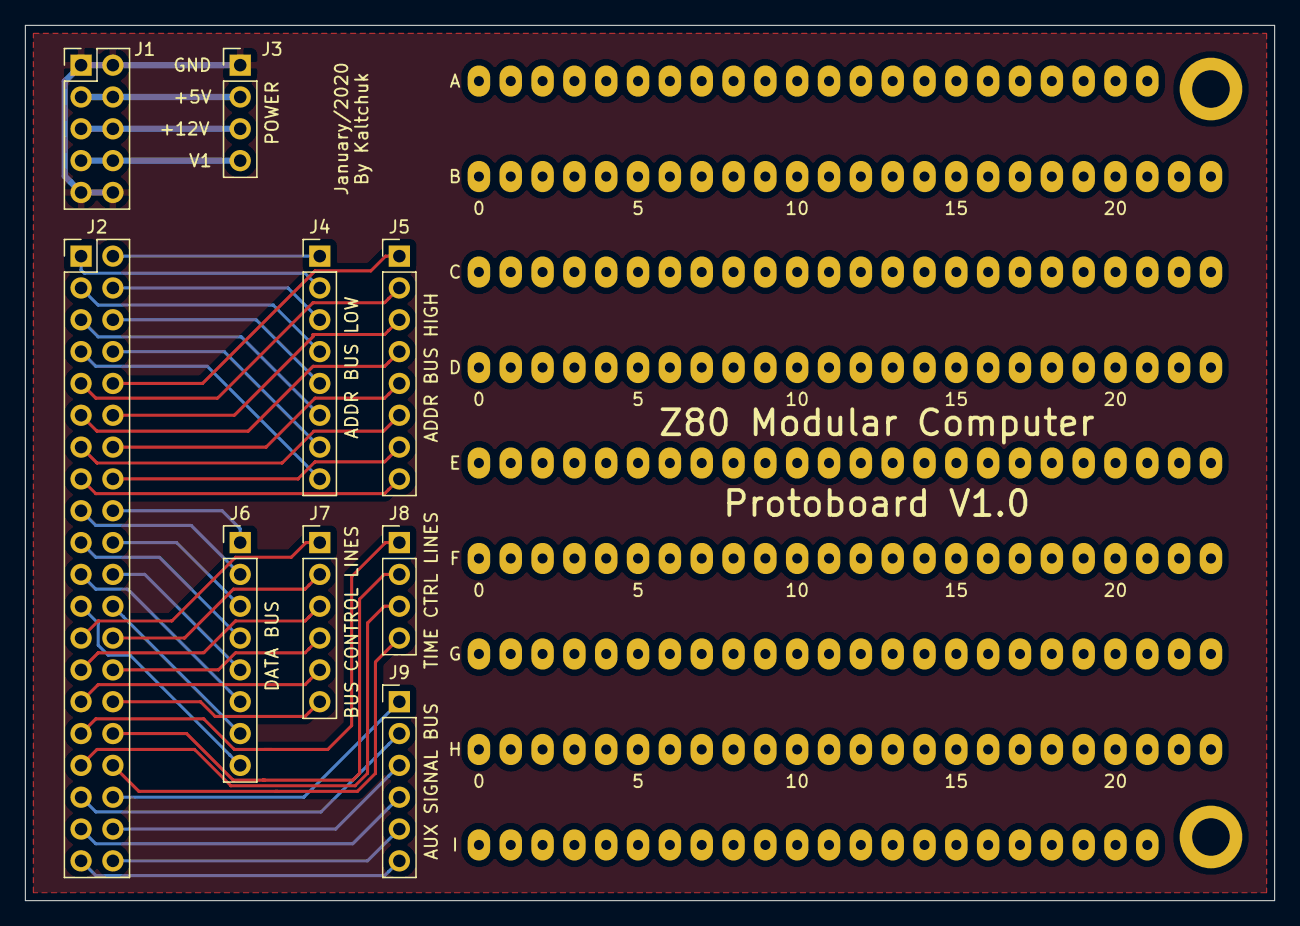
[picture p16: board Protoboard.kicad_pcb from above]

Board: 2 copper layers, 99.7 x 69.8 mm, 9 parts (0 on the bottom side), 44 nets.

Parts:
J1: Conn_02x05; PinHeader_2x05_P2.54mm_Vertical
J2: Conn_02x20; PinHeader_2x20_P2.54mm_Vertical
J3, J8: Conn_01x04; PinHeader_1x04_P2.54mm_Vertical
J4, J5, J6: Conn_01x08; PinHeader_1x08_P2.54mm_Vertical
J7, J9: Conn_01x06; PinHeader_1x06_P2.54mm_Vertical

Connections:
/+5V: J1.3, J1.4, J3.2
/+12V: J1.5, J1.6, J3.3
/a00: J2.2, J4.1
/a01: J2.1, J4.2
/a02: J2.4, J4.3
/a03: J2.3, J4.4
/a04: J2.6, J4.5
/a05: J2.5, J4.6
/a06: J2.8, J4.7
/a07: J2.7, J4.8
/a08: J2.10, J5.1
/a09: J2.9, J5.2
/a10: J2.12, J5.3
/a11: J2.11, J5.4
/a12: J2.14, J5.5
/a13: J2.13, J5.6
/a14: J2.16, J5.7
/a15: J2.15, J5.8
/busack: J2.29, J7.5
/busrq: J2.30, J7.6
/clk: J2.39, J9.6
/d00: J2.18, J6.1
/d01: J2.17, J6.2
/d02: J2.20, J6.3
/d03: J2.19, J6.4
/d04: J2.22, J6.5
/d05: J2.21, J6.6
/d06: J2.24, J6.7
/d07: J2.23, J6.8
/gnd: J1.1, J1.2, J1.9, J1.10, J3.1
/halt: J2.31, J8.1
/int: J2.33, J8.3
/iorq: J2.28, J7.4
/m1: J2.37, J9.4
/mreq: J2.26, J7.2
/nmi: J2.34, J8.4
/rd: J2.27, J7.3
/reset: J2.40, J9.5
/rfsh: J2.38, J9.3
/s0: J2.36, J9.1
/s1: J2.35, J9.2
/v1: J1.7, J1.8, J3.4
/wait: J2.32, J8.2
/wr: J2.25, J7.1

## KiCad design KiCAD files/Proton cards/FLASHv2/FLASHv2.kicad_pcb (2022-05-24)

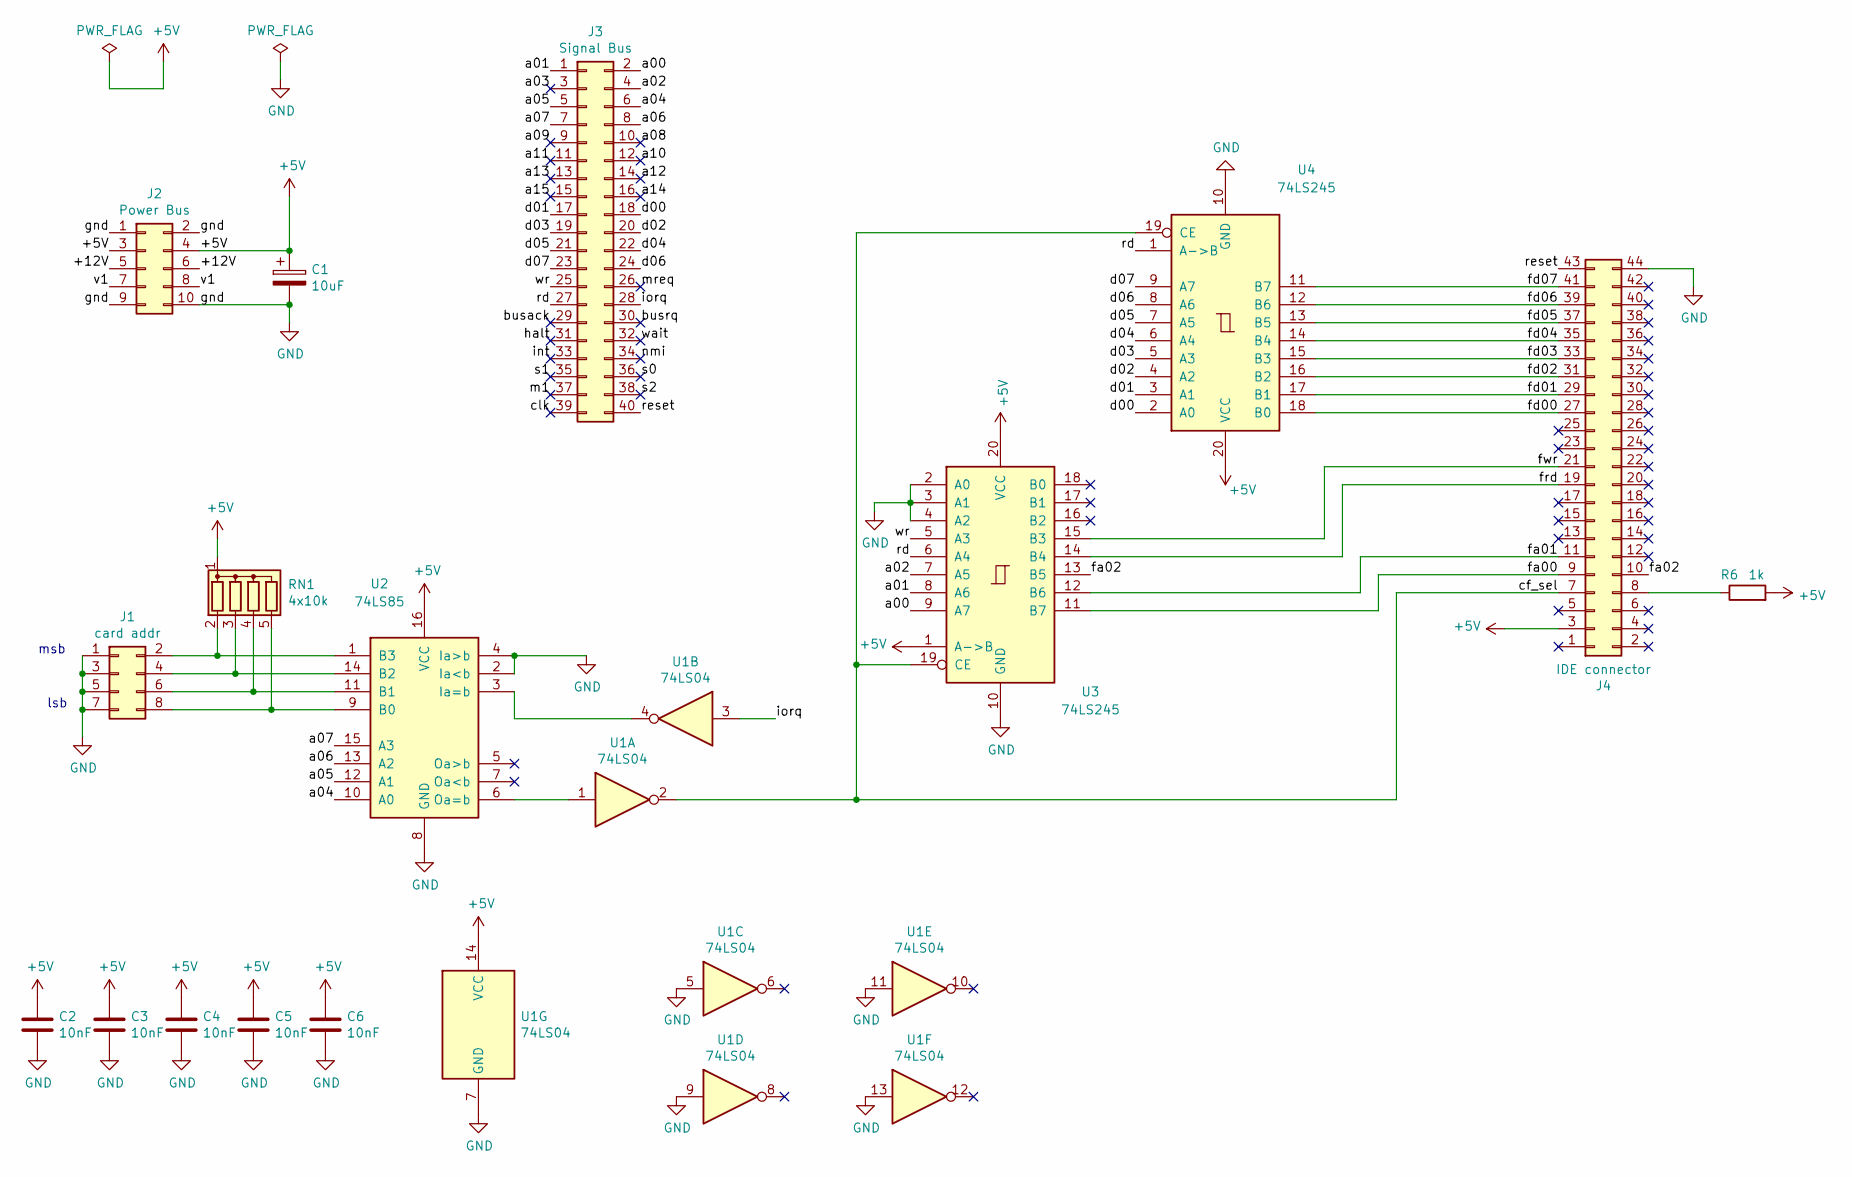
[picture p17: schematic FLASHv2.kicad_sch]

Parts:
C1: 10uF; CP_Radial_D5.0mm_P2.50mm
C2, C3, C4, C5, C6: 10nF; C_Disc_D3.8mm_W2.6mm_P2.50mm
J1: card addr; PinHeader_2x04_P2.54mm_Vertical
J2: Power Bus; PinHeader_2x05_P2.54mm_Vertical
J3: Signal Bus; PinHeader_2x20_P2.54mm_Vertical
J4: IDE connector; PinHeader_2x22_P2.00mm_Vertical
R6: 1k; R_Axial_DIN0207_L6.3mm_D2.5mm_P10.16mm_Horizontal
RN1: 4x10k; R_Array_SIP5
U1: 74LS04; DIP-14_W7.62mm_Socket_LongPads
U2: 74LS85; DIP-16_W7.62mm_Socket_LongPads
U3, U4: 74LS245; DIP-20_W7.62mm_Socket_LongPads

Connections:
+5V: C1.1, C2.1, C3.1, C4.1, C5.1, C6.1, J2.3, J2.4, J4.3, R6.2, RN1.1 (common), U1.14 (VCC), U2.16 (VCC), U3.1 (A->B), U3.20 (VCC), U4.20 (VCC)
/+12V: J2.5, J2.6
/a00: J3.2, U3.9 (A7)
/a01: J3.1, U3.8 (A6)
/a02: J3.4, U3.7 (A5)
/a03: J3.3
/a04: J3.6, U2.10 (A0)
/a05: J3.5, U2.12 (A1)
/a06: J3.8, U2.13 (A2)
/a07: J3.7, U2.15 (A3)
/a08: J3.10
/a09: J3.9
/a10: J3.12
/a11: J3.11
/a12: J3.14
/a13: J3.13
/a14: J3.16
/a15: J3.15
/busack: J3.29
/busrq: J3.30
/cf_sel: J4.7, U1.2, U3.19 (CE), U4.19 (CE)
/clk: J3.39
/d00: J3.18, U4.2 (A0)
/d01: J3.17, U4.3 (A1)
/d02: J3.20, U4.4 (A2)
/d03: J3.19, U4.5 (A3)
/d04: J3.22, U4.6 (A4)
/d05: J3.21, U4.7 (A5)
/d06: J3.24, U4.8 (A6)
/d07: J3.23, U4.9 (A7)
/fa00: J4.9, U3.11 (B7)
/fa01: J4.11, U3.12 (B6)
/fa02: J4.10, U3.13 (B5)
/fd00: J4.27, U4.18 (B0)
/fd01: J4.29, U4.17 (B1)
/fd02: J4.31, U4.16 (B2)
/fd03: J4.33, U4.15 (B3)
/fd04: J4.35, U4.14 (B4)
/fd05: J4.37, U4.13 (B5)
/fd06: J4.39, U4.12 (B6)
/fd07: J4.41, U4.11 (B7)
/frd: J4.19, U3.14 (B4)
/fwr: J4.21, U3.15 (B3)
/halt: J3.31
/int: J3.33
/iorq: J3.28, U1.3
/m1: J3.37
/mreq: J3.26
/nmi: J3.34
/rd: J3.27, U3.6 (A4), U4.1 (A->B)
/reset: J3.40, J4.43
/s0: J3.36
/s1: J3.35
/s2: J3.38
/v1: J2.7, J2.8
/wait: J3.32
/wr: J3.25, U3.5 (A3)
GND: C1.2, C2.2, C3.2, C4.2, C5.2, C6.2, J1.1, J1.3, J1.5, J1.7, J2.1, J2.2, J2.9, J2.10, J4.44, U1.5, U1.7 (GND), U1.9, U1.11, U1.13, U2.2 (Ia<b), U2.4 (Ia>b), U2.8 (GND), U3.2 (A0), U3.3 (A1), U3.4 (A2), U3.10 (GND), U4.10 (GND)
unnamed: J1.2, RN1.2 (R1), U2.1 (B3)
unnamed: J1.4, RN1.3 (R2), U2.14 (B2)
unnamed: J1.6, RN1.4 (R3), U2.11 (B1)
unnamed: J1.8, RN1.5 (R4), U2.9 (B0)
unnamed: J4.8, R6.1
unnamed: U1.1, U2.6 (Oa=b)
unnamed: U1.4, U2.3 (Ia=b)

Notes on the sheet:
lsb
msb

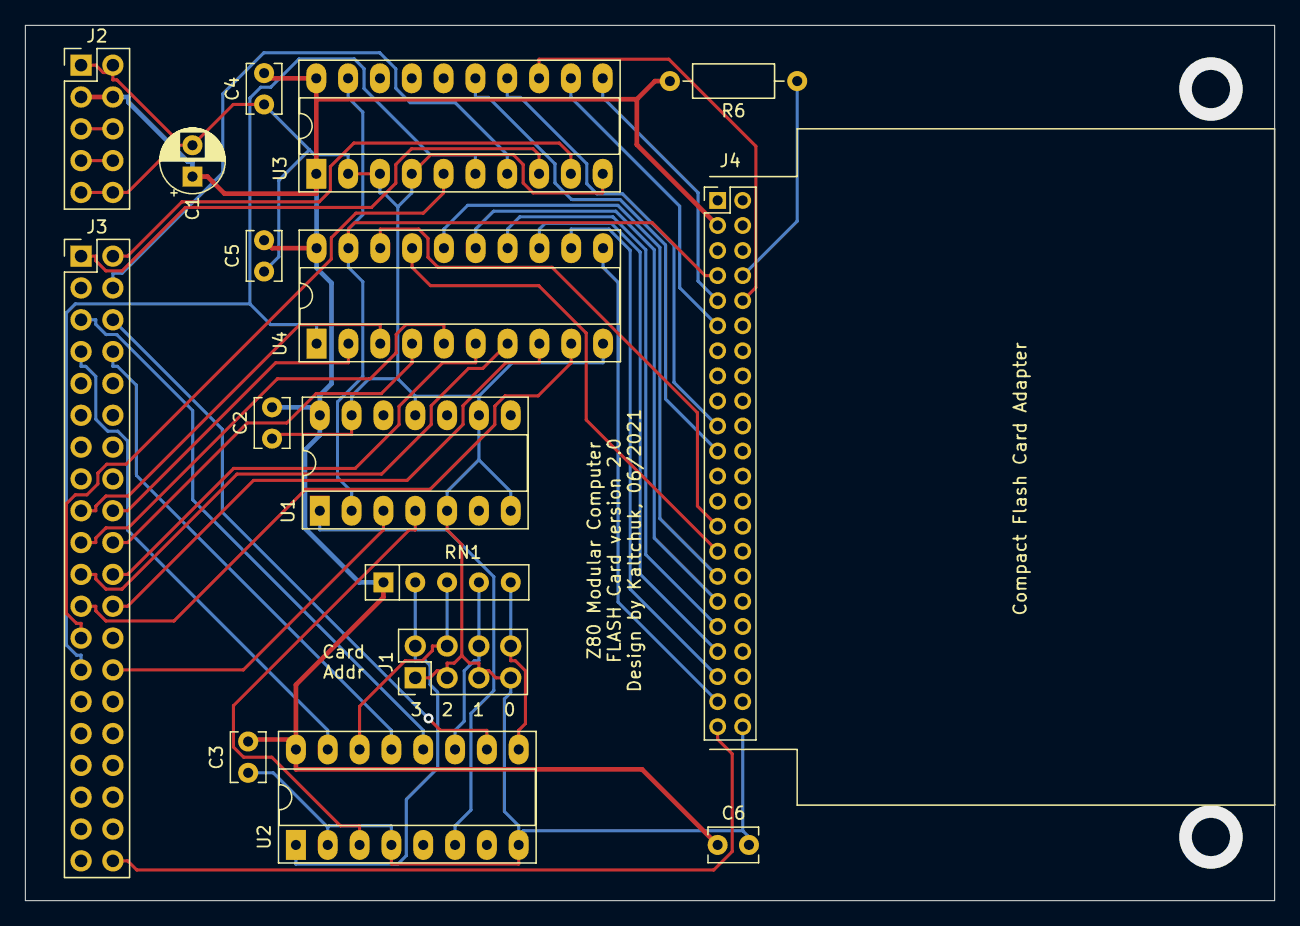
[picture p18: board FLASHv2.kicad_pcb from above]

Board: 2 copper layers, 99.7 x 69.8 mm, 16 parts (0 on the bottom side), 44 nets.

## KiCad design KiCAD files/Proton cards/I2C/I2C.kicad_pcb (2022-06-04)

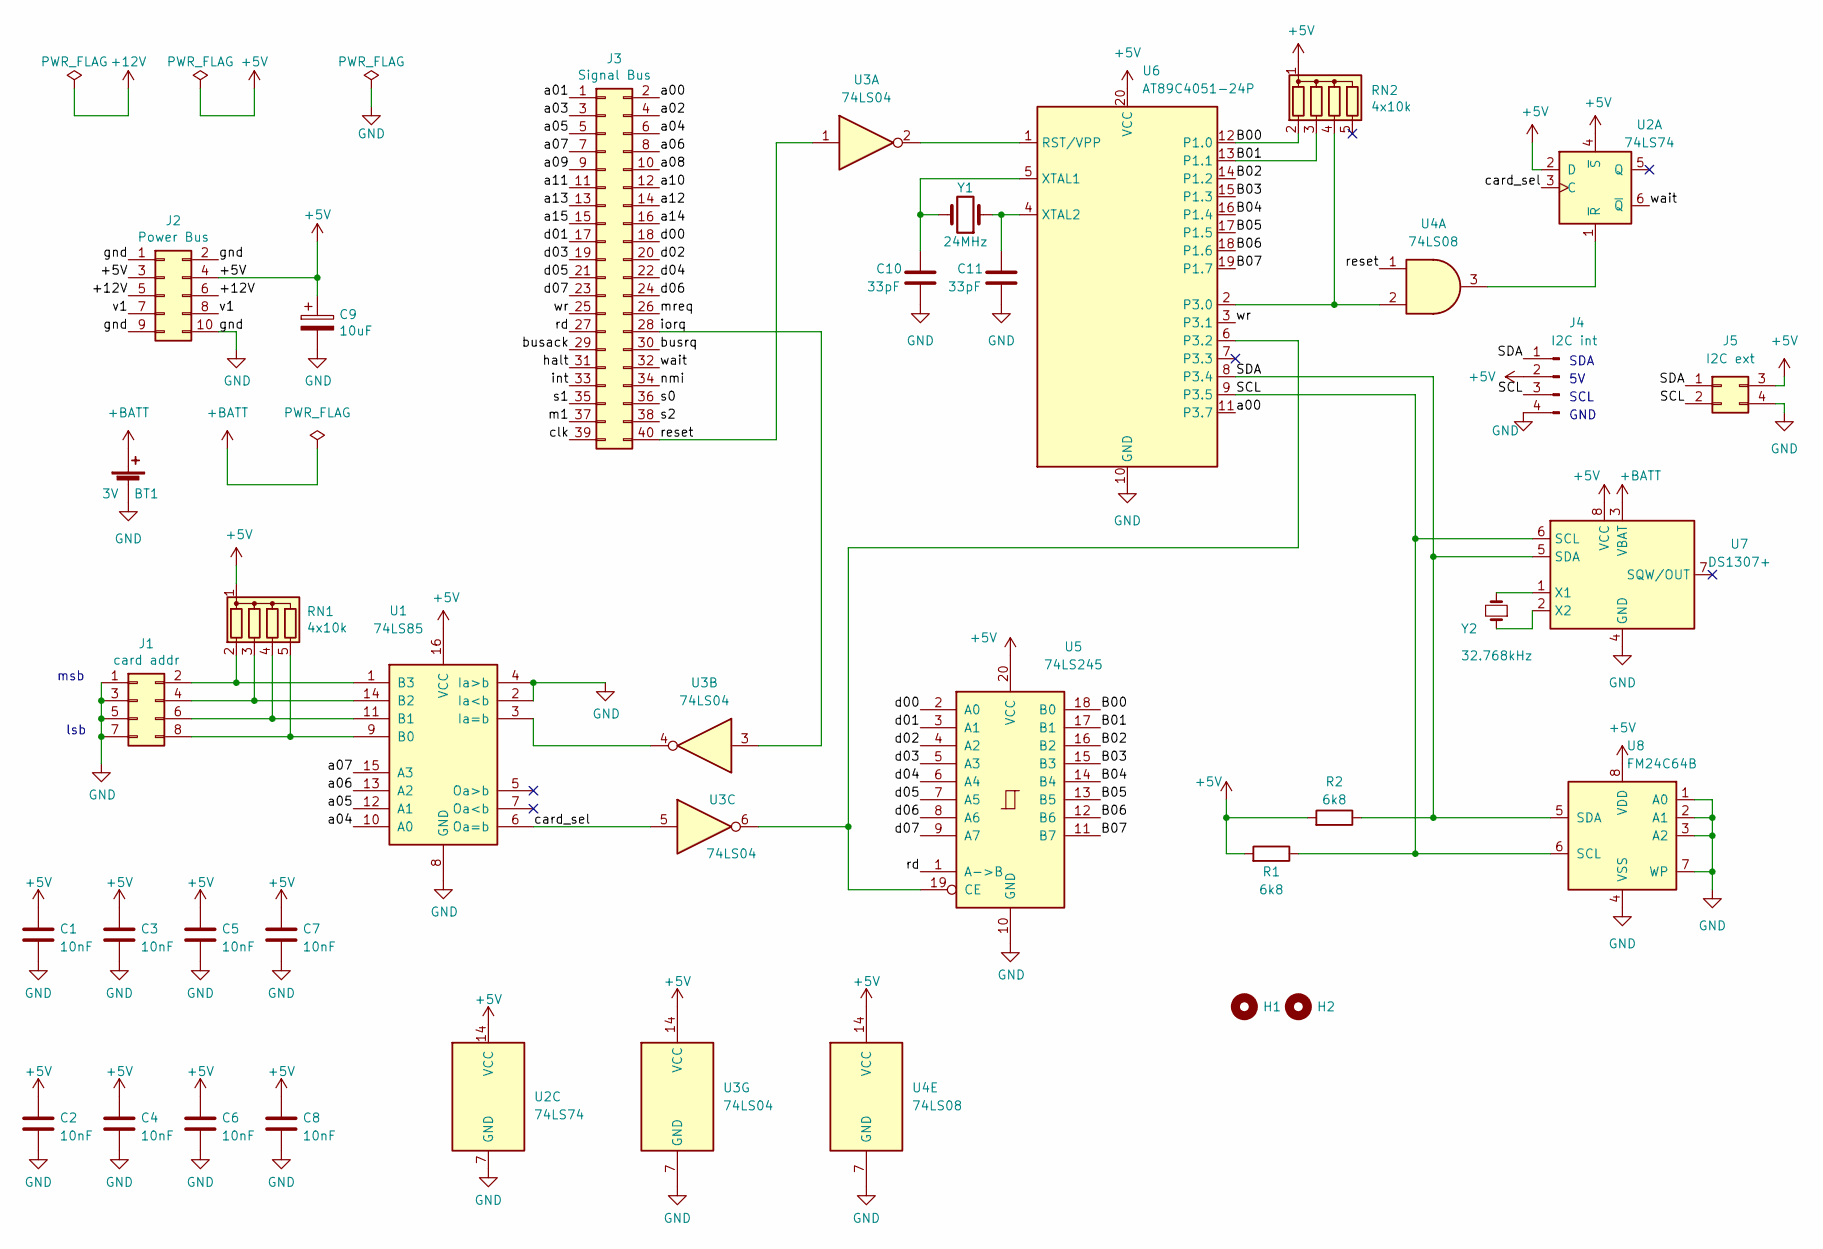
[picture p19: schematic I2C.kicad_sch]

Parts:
BT1: 3V; Battery-Holder_CR2032
C1, C2, C3, C4, C5, C6, C7, C8: 10nF; C_Disc_D3.8mm_W2.6mm_P2.50mm
C9: 10uF; CP_Radial_D5.0mm_P2.50mm
C10, C11: 33pF; C_Disc_D3.8mm_W2.6mm_P2.50mm
H1, H2: (no value)
J1: card addr; PinHeader_2x04_P2.54mm_Vertical
J2: Power Bus; PinHeader_2x05_P2.54mm_Vertical
J3: Signal Bus; PinHeader_2x20_P2.54mm_Vertical
J4: I2C int; PinHeader_1x04_P2.54mm_Vertical
J5: I2C ext; PinHeader_2x02_P2.54mm_Vertical
R1, R2: 6k8; R_Axial_DIN0207_L6.3mm_D2.5mm_P10.16mm_Horizontal
RN1, RN2: 4x10k; R_Array_SIP5
U1: 74LS85; DIP-16_W7.62mm_Socket_LongPads
U2: 74LS74; DIP-14_W7.62mm_Socket_LongPads
U3: 74LS04; DIP-14_W7.62mm_Socket_LongPads
U4: 74LS08; DIP-14_W7.62mm_Socket_LongPads
U5: 74LS245; DIP-20_W7.62mm_Socket_LongPads
U6: AT89C4051-24P; DIP-20_W7.62mm_Socket_LongPads
U7: DS1307+; DIP-8_W7.62mm_Socket_LongPads
U8: FM24C64B; DIP-8_W7.62mm_Socket_LongPads
Y1: 24MHz; Crystal_HC49-U_Vertical
Y2: 32.768kHz; Crystal_Round_D1.5mm_Vertical

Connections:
+5V: C1.1, C2.1, C3.1, C4.1, C5.1, C6.1, C7.1, C8.1, C9.1, J2.3, J2.4, J4.2, J5.3, R1.2, R2.2, RN1.1 (common), RN2.1 (common), U1.16 (VCC), U2.2 (D), U2.4 (~S), U2.14 (VCC), U3.14 (VCC), U4.14 (VCC), U5.20 (VCC), U6.20 (VCC), U7.8 (VCC), U8.8 (VDD)
+12V: J2.5, J2.6
+BATT: BT1.1 (+), U7.3 (VBAT)
/B00: RN2.2 (R1), U5.18 (B0), U6.12 (P1.0)
/B01: RN2.3 (R2), U5.17 (B1), U6.13 (P1.1)
/B02: U5.16 (B2), U6.14 (P1.2)
/B03: U5.15 (B3), U6.15 (P1.3)
/B04: U5.14 (B4), U6.16 (P1.4)
/B05: U5.13 (B5), U6.17 (P1.5)
/B06: U5.12 (B6), U6.18 (P1.6)
/B07: U5.11 (B7), U6.19 (P1.7)
/SCL: J4.3, J5.2, R1.1, U6.9 (P3.5), U7.6 (SCL), U8.6 (SCL)
/SDA: J4.1, J5.1, R2.1, U6.8 (P3.4), U7.5 (SDA), U8.5 (SDA)
/a00: J3.2, U6.11 (P3.7)
/a01: J3.1
/a02: J3.4
/a03: J3.3
/a04: J3.6, U1.10 (A0)
/a05: J3.5, U1.12 (A1)
/a06: J3.8, U1.13 (A2)
/a07: J3.7, U1.15 (A3)
/a08: J3.10
/a09: J3.9
/a10: J3.12
/a11: J3.11
/a12: J3.14
/a13: J3.13
/a14: J3.16
/a15: J3.15
/busack: J3.29
/busrq: J3.30
/card_sel: U1.6 (Oa=b), U2.3 (C), U3.5
/clk: J3.39
/d00: J3.18, U5.2 (A0)
/d01: J3.17, U5.3 (A1)
/d02: J3.20, U5.4 (A2)
/d03: J3.19, U5.5 (A3)
/d04: J3.22, U5.6 (A4)
/d05: J3.21, U5.7 (A5)
/d06: J3.24, U5.8 (A6)
/d07: J3.23, U5.9 (A7)
/halt: J3.31
/int: J3.33
/iorq: J3.28, U3.3
/m1: J3.37
/mreq: J3.26
/nmi: J3.34
/rd: J3.27, U5.1 (A->B)
/reset: J3.40, U3.1, U4.1
/s0: J3.36
/s1: J3.35
/s2: J3.38
/v1: J2.7, J2.8
/wait: J3.32, U2.6 (~Q)
/wr: J3.25, U6.3 (P3.1)
GND: BT1.2 (-), C1.2, C2.2, C3.2, C4.2, C5.2, C6.2, C7.2, C8.2, C9.2, C10.2, C11.2, J1.1, J1.3, J1.5, J1.7, J2.1, J2.2, J2.9, J2.10, J4.4, J5.4, U1.2 (Ia<b), U1.4 (Ia>b), U1.8 (GND), U2.7 (GND), U3.7 (GND), U4.7 (GND), U5.10 (GND), U6.10 (GND), U7.4 (GND), U8.1 (A0), U8.2 (A1), U8.3 (A2), U8.4 (VSS), U8.7 (WP)
unnamed: C10.1, U6.5 (XTAL1), Y1.2
unnamed: C11.1, U6.4 (XTAL2), Y1.1
unnamed: J1.2, RN1.2 (R1), U1.1 (B3)
unnamed: J1.4, RN1.3 (R2), U1.14 (B2)
unnamed: J1.6, RN1.4 (R3), U1.11 (B1)
unnamed: J1.8, RN1.5 (R4), U1.9 (B0)
unnamed: RN2.4 (R3), U4.2, U6.2 (P3.0)
unnamed: U1.3 (Ia=b), U3.4
unnamed: U2.1 (~R), U4.3
unnamed: U3.2, U6.1 (RST/VPP)
unnamed: U3.6, U5.19 (CE), U6.6 (P3.2)
unnamed: U7.1 (X1), Y2.2
unnamed: U7.2 (X2), Y2.1

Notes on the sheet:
SDA
msb
lsb
SCL
GND

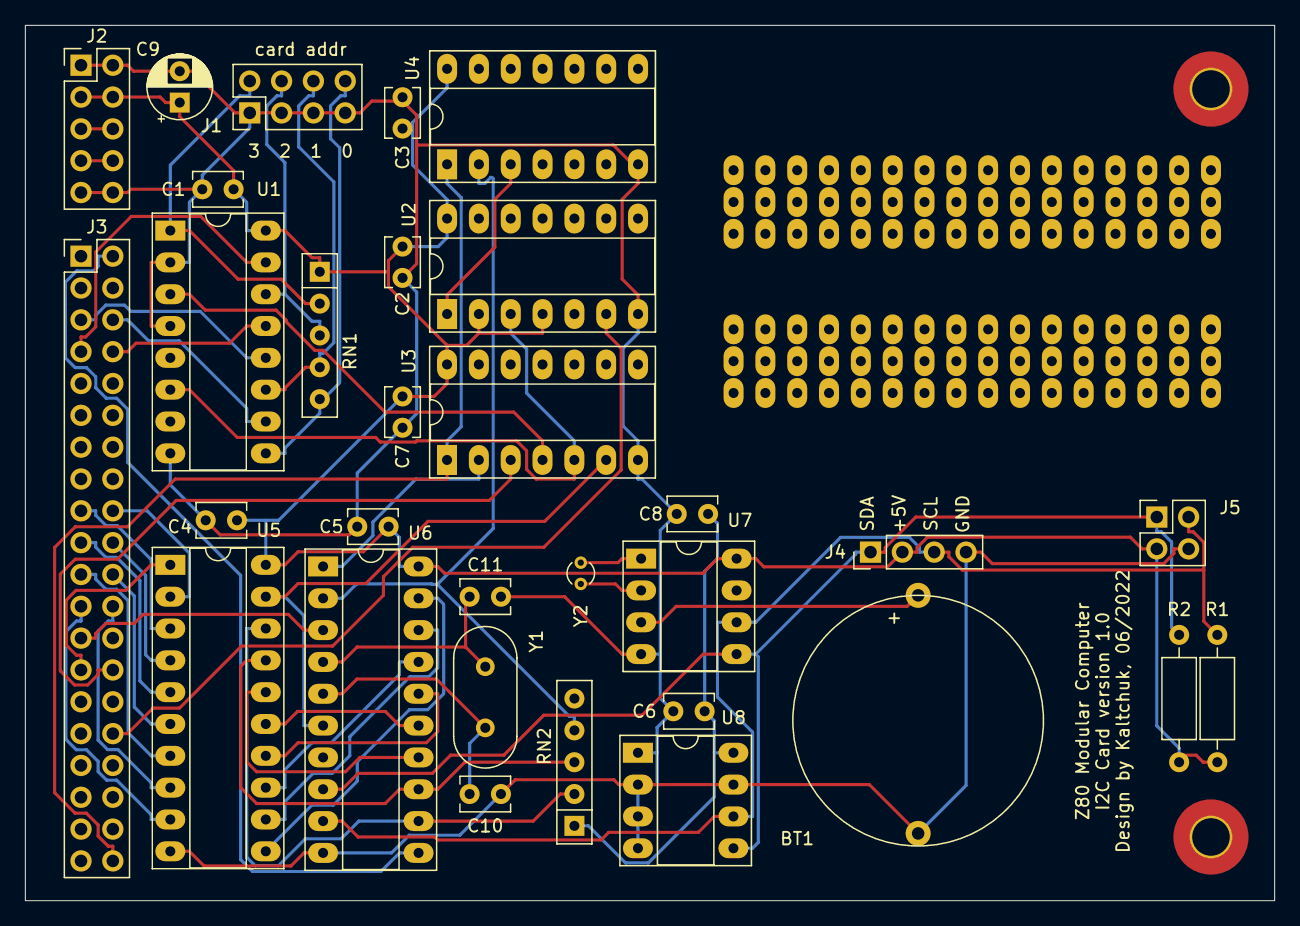
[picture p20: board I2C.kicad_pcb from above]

Board: 2 copper layers, 99.7 x 69.8 mm, 33 parts (0 on the bottom side), 47 nets.

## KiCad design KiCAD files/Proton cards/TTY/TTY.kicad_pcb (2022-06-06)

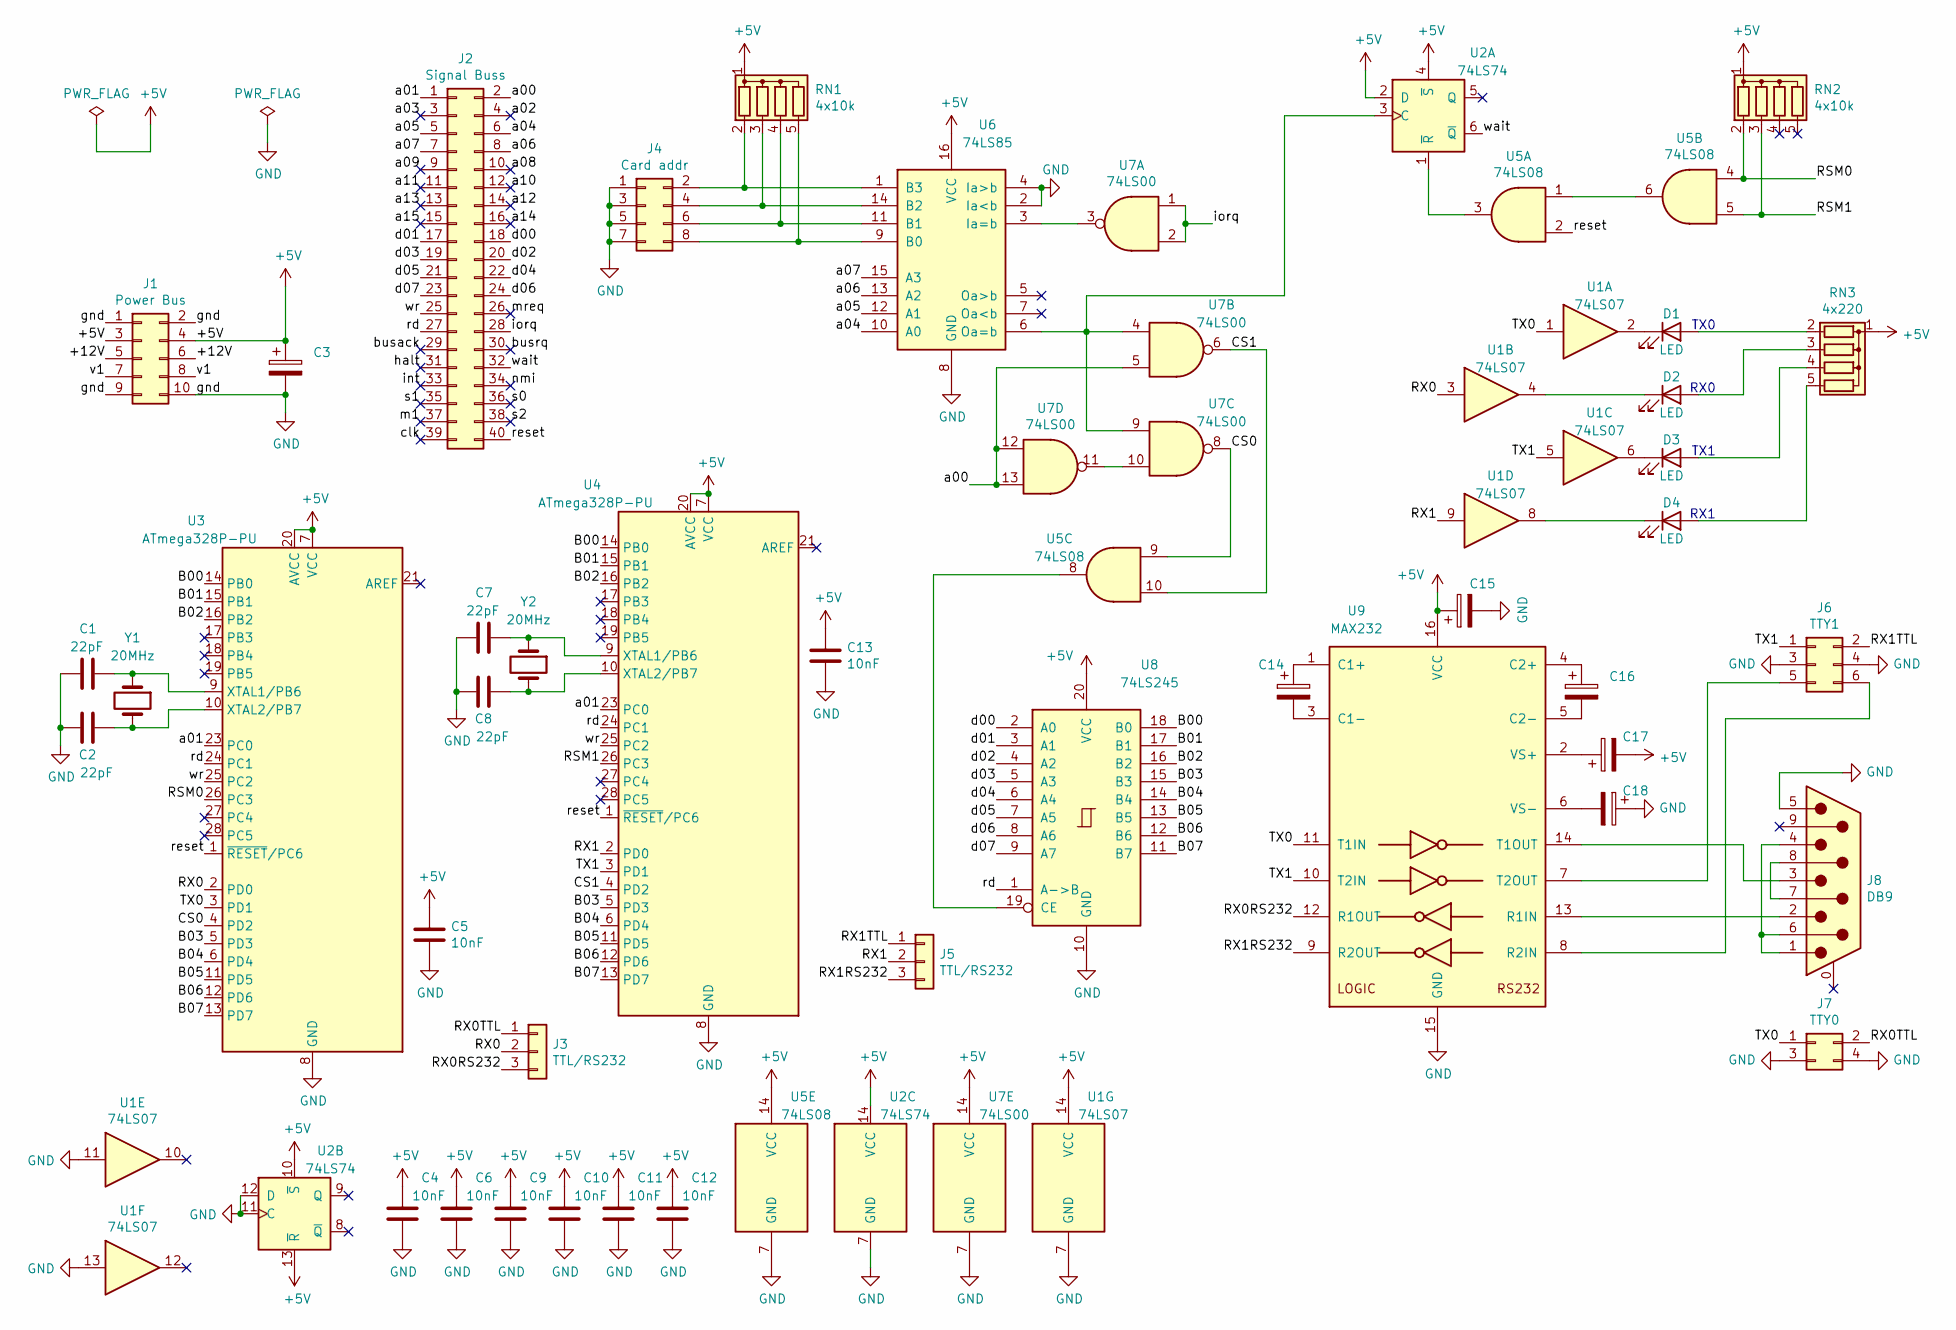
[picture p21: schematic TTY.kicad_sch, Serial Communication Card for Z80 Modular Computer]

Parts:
C1, C2, C7, C8: 22pF; C_Disc_D3.8mm_W2.6mm_P2.50mm
C3, C14, C15, C16, C17, C18: (no value)
C4, C5, C6, C9, C10, C11, C12, C13: 10nF; C_Disc_D3.8mm_W2.6mm_P2.50mm
D1, D2, D3, D4: LED; LED_D3.0mm
J1: Power Bus; PinHeader_2x05_P2.54mm_Vertical
J2: Signal Buss; PinHeader_2x20_P2.54mm_Vertical
J3, J5: TTL/RS232; PinHeader_1x03_P2.54mm_Vertical
J4: Card addr; PinHeader_2x04_P2.54mm_Vertical
J6: TTY1; PinHeader_2x03_P2.54mm_Vertical
J7: TTY0; PinHeader_2x02_P2.54mm_Vertical
J8: DB9; DSUB-9_Male_Horizontal_P2.77x2.84mm_EdgePinOffset4.94mm_Hou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
RN1, RN2: 4x10k; R_Array_SIP5
RN3: 4x220; R_Array_SIP5
U1: 74LS07; DIP-14_W7.62mm_Socket_LongPads
U2: 74LS74; DIP-14_W7.62mm_Socket_LongPads
U3, U4: ATmega328P-PU; DIP-28_W7.62mm_Socket_LongPads
U5: 74LS08; DIP-14_W7.62mm_Socket_LongPads
U6: 74LS85; DIP-16_W7.62mm_Socket_LongPads
U7: 74LS00; DIP-14_W7.62mm_Socket_LongPads
U8: 74LS245; DIP-20_W7.62mm_Socket_LongPads
U9: MAX232; DIP-16_W7.62mm_Socket_LongPads
Y1, Y2: 20MHz; Crystal_HC49-U_Vertical

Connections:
+5V: C3.1, C4.1, C5.1, C6.1, C9.1, C10.1, C11.1, C12.1, C13.1, C15.1, C17.2, J1.3, J1.4, RN1.1 (common), RN2.1 (common), RN3.1 (common), U1.14 (VCC), U2.2 (D), U2.4 (~S), U2.10 (~S), U2.13 (~R), U2.14 (VCC), U3.7 (VCC), U3.20 (AVCC), U4.7 (VCC), U4.20 (AVCC), U5.14 (VCC), U6.16 (VCC), U7.14 (VCC), U8.20 (VCC), U9.16 (VCC)
/+12V: J1.5, J1.6
/B00: U3.14 (PB0), U4.14 (PB0), U8.18 (B0)
/B01: U3.15 (PB1), U4.15 (PB1), U8.17 (B1)
/B02: U3.16 (PB2), U4.16 (PB2), U8.16 (B2)
/B03: U3.5 (PD3), U4.5 (PD3), U8.15 (B3)
/B04: U3.6 (PD4), U4.6 (PD4), U8.14 (B4)
/B05: U3.11 (PD5), U4.11 (PD5), U8.13 (B5)
/B06: U3.12 (PD6), U4.12 (PD6), U8.12 (B6)
/B07: U3.13 (PD7), U4.13 (PD7), U8.11 (B7)
/CS0: U3.4 (PD2), U5.9, U7.8
/CS1: U4.4 (PD2), U5.10, U7.6
/RSM0: RN2.2 (R1), U3.26 (PC3), U5.4
/RSM1: RN2.3 (R2), U4.26 (PC3), U5.5
/RX0: J3.2, U1.3, U3.2 (PD0)
/RX0RS232: J3.3, U9.12 (R1OUT)
/RX0TTL: J3.1, J7.2
/RX1: J5.2, U1.9, U4.2 (PD0)
/RX1RS232: J5.3, U9.9 (R2OUT)
/RX1TTL: J5.1, J6.2
/TX0: J7.1, U1.1, U3.3 (PD1), U9.11 (T1IN)
/TX1: J6.1, U1.5, U4.3 (PD1), U9.10 (T2IN)
/a00: J2.2, U7.5, U7.12, U7.13
/a01: J2.1, U3.23 (PC0), U4.23 (PC0)
/a02: J2.4
/a03: J2.3
/a04: J2.6, U6.10 (A0)
/a05: J2.5, U6.12 (A1)
/a06: J2.8, U6.13 (A2)
/a07: J2.7, U6.15 (A3)
/a08: J2.10
/a09: J2.9
/a10: J2.12
/a11: J2.11
/a12: J2.14
/a13: J2.13
/a14: J2.16
/a15: J2.15
/busack: J2.29
/busrq: J2.30
/clk: J2.39
/d00: J2.18, U8.2 (A0)
/d01: J2.17, U8.3 (A1)
/d02: J2.20, U8.4 (A2)
/d03: J2.19, U8.5 (A3)
/d04: J2.22, U8.6 (A4)
/d05: J2.21, U8.7 (A5)
/d06: J2.24, U8.8 (A6)
/d07: J2.23, U8.9 (A7)
/halt: J2.31
/int: J2.33
/iorq: J2.28, U7.1, U7.2
/m1: J2.37
/mreq: J2.26
/nmi: J2.34
/rd: J2.27, U3.24 (PC1), U4.24 (PC1), U8.1 (A->B)
/reset: J2.40, U3.1 (~RESET/PC6), U4.1 (~RESET/PC6), U5.2
/s0: J2.36
/s1: J2.35
/s2: J2.38
/v1: J1.7, J1.8
/wait: J2.32, U2.6 (~Q)
/wr: J2.25, U3.25 (PC2), U4.25 (PC2)
GND: C1.2, C2.2, C3.2, C4.2, C5.2, C6.2, C7.2, C8.2, C9.2, C10.2, C11.2, C12.2, C13.2, C15.2, C18.1, J1.1, J1.2, J1.9, J1.10, J4.1, J4.3, J4.5, J4.7, J6.3, J6.4, J7.3, J7.4, J8.5, U1.7 (GND), U1.11, U1.13, U2.7 (GND), U2.11 (C), U2.12 (D), U3.8 (GND), U3.22 (GND), U4.8 (GND), U4.22 (GND), U5.7 (GND), U6.2 (Ia<b), U6.4 (Ia>b), U6.8 (GND), U7.7 (GND), U8.10 (GND), U9.15 (GND)
unnamed: C1.1, U3.9 (XTAL1/PB6), Y1.1
unnamed: C2.1, U3.10 (XTAL2/PB7), Y1.2
unnamed: C7.1, U4.9 (XTAL1/PB6), Y2.1
unnamed: C8.1, U4.10 (XTAL2/PB7), Y2.2
unnamed: C14.1, U9.1 (C1+)
unnamed: C14.2, U9.3 (C1-)
unnamed: C16.1, U9.4 (C2+)
unnamed: C16.2, U9.5 (C2-)
unnamed: C17.1, U9.2 (VS+)
unnamed: C18.2, U9.6 (VS-)
unnamed: D1.1 (K), U1.2
unnamed: D1.2 (A), RN3.2 (R1)
unnamed: D2.1 (K), U1.4
unnamed: D2.2 (A), RN3.3 (R2)
unnamed: D3.1 (K), U1.6
unnamed: D3.2 (A), RN3.4 (R3)
unnamed: D4.1 (K), U1.8
unnamed: D4.2 (A), RN3.5 (R4)
unnamed: J4.2, RN1.2 (R1), U6.1 (B3)
unnamed: J4.4, RN1.3 (R2), U6.14 (B2)
unnamed: J4.6, RN1.4 (R3), U6.11 (B1)
unnamed: J4.8, RN1.5 (R4), U6.9 (B0)
unnamed: J6.5, U9.7 (T2OUT)
unnamed: J6.6, U9.8 (R2IN)
unnamed: J8.1, J8.4, J8.6
unnamed: J8.2, U9.13 (R1IN)
unnamed: J8.3, U9.14 (T1OUT)
unnamed: J8.7, J8.8
unnamed: U2.1 (~R), U5.3
unnamed: U2.3 (C), U6.6 (Oa=b), U7.4, U7.9
unnamed: U5.1, U5.6
unnamed: U5.8, U8.19 (CE)
unnamed: U6.3 (Ia=b), U7.3
unnamed: U7.10, U7.11

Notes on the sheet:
RX1
RX0
TX1
TX0

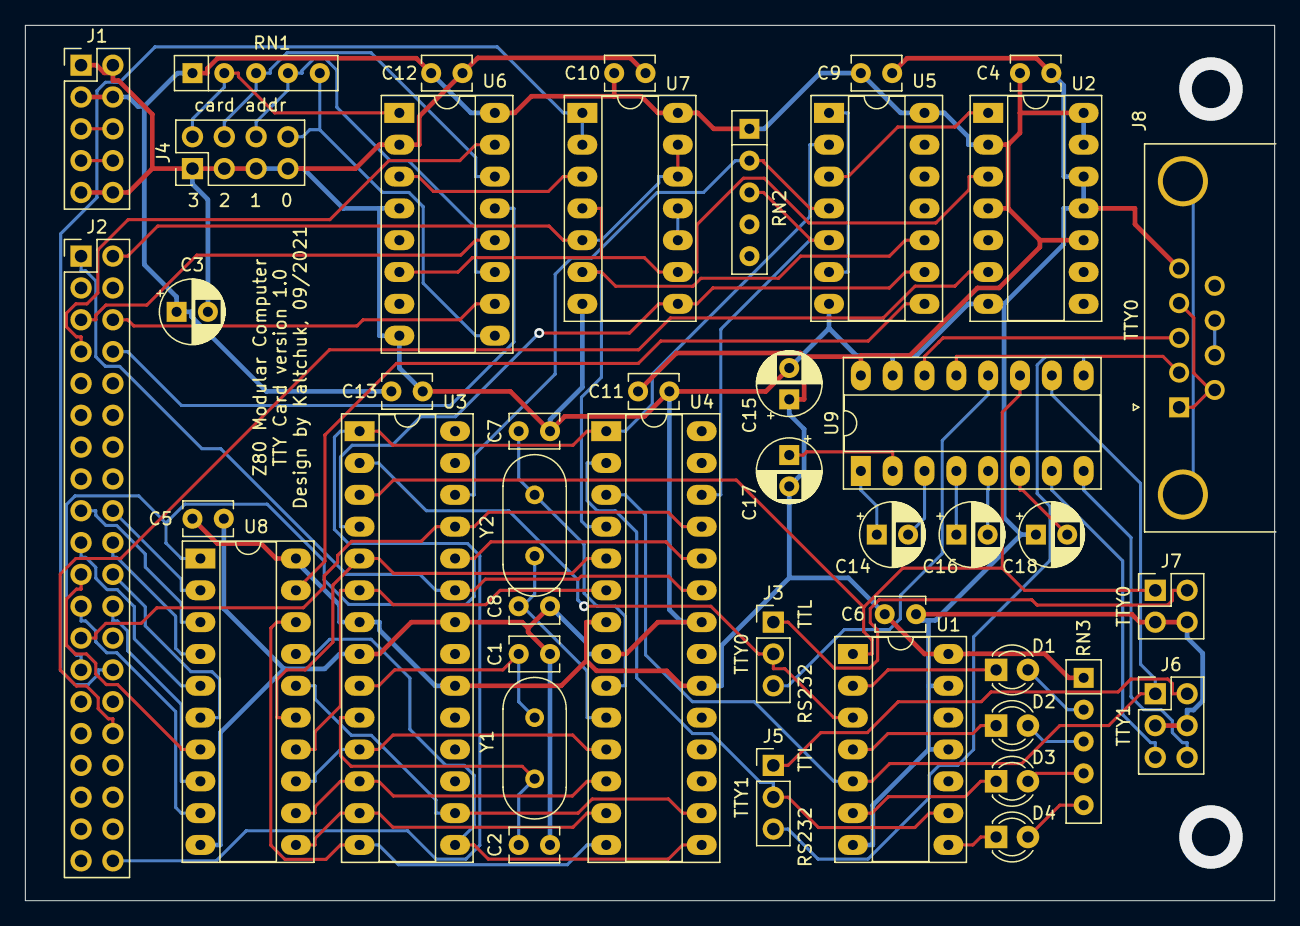
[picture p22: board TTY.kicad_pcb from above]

Board: 2 copper layers, 99.7 x 69.9 mm, 44 parts (0 on the bottom side), 77 nets.

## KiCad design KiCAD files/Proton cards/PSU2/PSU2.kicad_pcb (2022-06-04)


Board: 2 copper layers, 99.7 x 69.8 mm, 20 parts (0 on the bottom side), 15 nets.

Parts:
D1, D2, D3: LED; LED_D3.0mm
H1, H2: MountingHole; Mounting_Hole_0.2in
J1: Ext switch; PinHeader_1x02_P2.54mm_Vertical
J2: To switch; PinHeader_1x02_P2.54mm_Vertical
J3: Mains; IEC60320_2pin
J4: Vo enable; PinHeader_2x02_P2.54mm_Vertical
J5: Power bus; PinHeader_2x05_P2.54mm_Vertical
J6: Mech support; PinHeader_2x05_P2.54mm_Vertical
K1: SRD-05VDC-SL-C; Relay_SPDT_Songel-15x19mm
PS1: MT3608_2-24V_2A
PS2: XPJ-01B_5V_10W; Converter_ACDC_5V_10W_XPJ-01B
R1: 1k2; R_Axial_DIN0207_L6.3mm_D2.5mm_P7.62mm_Horizontal
R2: 390; R_Axial_DIN0207_L6.3mm_D2.5mm_P7.62mm_Horizontal
R3: 330; R_Axial_DIN0207_L6.3mm_D2.5mm_P7.62mm_Horizontal
R4: 240; R_Axial_DIN0207_L6.3mm_D2.5mm_P7.62mm_Horizontal
R5: 150; R_Axial_DIN0207_L6.3mm_D2.5mm_P7.62mm_Horizontal
U1: LM317_TO-220; TO-220-3_Vertical

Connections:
/+3.3V: D3.2 (A), J5.7, J5.8, R4.1, U1.2 (VO)
/+5V: D2.2 (A), J4.2, J4.4, J5.3, J5.4, PS2.4 (+Vo)
/+12V: D1.2 (A), J5.5, J5.6, PS1.4 (+Vout)
GND: J5.1, J5.2, J5.9, J5.10, PS1.1 (-Vin), PS1.3 (-Vout), PS2.3 (-Vo), R1.2, R2.2, R3.2, R5.2
LINE: J2.2, J3.1, K1.1
NEUT: J3.2, PS2.1 (AC/N)
unnamed: D1.1 (K), R1.1
unnamed: D2.1 (K), R3.1
unnamed: D3.1 (K), R5.1
unnamed: J1.1, K1.4
unnamed: J1.2, K1.3
unnamed: J2.1, K1.5, PS2.2 (AC/L)
unnamed: J4.1, PS1.2 (+Vin)
unnamed: J4.3, U1.3 (VI)
unnamed: R2.1, R4.2, U1.1 (ADJ)

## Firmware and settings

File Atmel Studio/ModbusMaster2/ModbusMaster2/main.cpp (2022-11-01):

/*
 * ModbusMaster.c v2.0
 *
 * Created: 28/10/2022 17:29:23
 * Author : Kaltchuk
 *
 */ 

//#define F_CPU	11059200UL
#define F_CPU	20000000UL					// Final version of RS485 Card must us 11059100

#include <avr/io.h>
#include <avr/interrupt.h>
#include <util/delay.h>

// Define Drive enable pin
#define DE			4						// DE pin
#define DE_LO		(PORTC &= ~(1<<DE))		// Receive enable.
#define DE_HI		(PORTC |= (1<<DE))		// Drive enable.

// Define chip select and release pins
#define CS			(PIND & (1<<INT0))		// CS pin
#define RSM			3						// RSM pin
#define RSM_LO		(PORTC &= ~(1<<RSM))
#define RSM_HI		(PORTC |= (1<<RSM))

#define asInput		1
#define asOutput	2

// Define Operations		/WR /RD AO1
#define WR_DATA		2	//	0	1	0
#define WR_COMMAND	3	//	0	1	1
#define RD_DATA		4	//	1	0	0
#define RD_STATUS	5	//	1	0	1		// Used only to read status after readRegister and writeRegister operations.

// Define Commands
#define setBaudrate			1		// receive 1 byte with new baud rate (ENUM). Followed by WR_DATA <baud>
#define getBaudrate			2		// send byte with current baud rate (ENUM). Followed by RD_DATA <baud> (0..9 ==> 1200, 2400, 4800, 9600, 14400, 19200, 28800, 38400, 57600, 115200 bps)
#define clearRXbuffer		3		// clear RX buffer. No arguments following.
#define clearTXbuffer		4		// clear TX buffer. No arguments following.
#define flushTXbuffer		5		// flush TX buffer. No arguments following.
#define enableCRCappend		6		// calculate and append CRC to TX buffer before flushing TX buffer. Default. No arguments following.
#define disableCRCappend	7		// don't do the CRC stuff. No arguments following.
#define sizeRXbuffer		8		// send number of bytes available in RX buffer. Followed by RD_DATA <size>.
#define readRXbuffer		9		// send one byte from RX buffer. Followed by RD_DATA <byte>.
#define writeTXbuffer		10		// receive byte and put it in TX buffer. Followed by WR_DATA <byte>
#define readRegister		11		// read a register. Followed by WR_DATA <register_HI> WR_DATA <register_LO> RD_DATA <val_HI> RD_DATA <val_LO>.
#define writeRegister		12		// write to a register. Followed by WR_DATA <register_HI> WR_DATA <register_LO> WR_DATA <val_HI> WR_DATA <val_LO>.

// Define types of I/Os
#define discInput			0		// R
#define coil				1		// R/W
#define inputReg			3		// R
#define holdingReg			4		// R/W

// Define Status
#define illigalFunction		1
#define illigalAddress		2
#define illigalValue		3
#define timeout				7



#define MAXBUFF		256

char			RXbuf[MAXBUFF]; 					// Buffer for chars that arrived through serial port.
int				RXbufInPtr=0, RXbufOutPtr=0;
char			TXbuf[MAXBUFF]; 					// Buffer for chars to be sent through serial port.
int				TXbufInPtr=0, TXbufOutPtr=0;

char			command=0;
bool			appendCRC=1, opMode=1;

char			tempBuf[8];
int				byteCount;
char			status=0;							// status returned from readRegister or writeRegister operations.

unsigned int long	baud[] = {1200, 2400, 4800, 9600, 14400, 19200, 28800, 38400, 57600, 115200};
unsigned long int	newBaud = 5;					// i.e. initial baud rate = 19200bps

void setDataBus(int modus) {
	if (modus == asInput) {				// Write zeros to PORTs.
		DDRB &= ~0x07;
		DDRD &= ~0xf8;
	}
	else {								// Write ones to PORTs.
		DDRB |= 0x07;
		DDRD |= 0xf8;
	}
}

void CRC(void) {
	bool lsb;
	char i=TXbufOutPtr, j;
	unsigned int crc = 0xFFFF;
	
	while (TXbufInPtr != i) {
		crc ^= (unsigned int)TXbuf[i++];
		for (j = 0; j < 8; j++) {
			lsb = crc & 1;
			crc >>= 1;
			if (lsb == 1)
			  crc ^= 0xA001;
		}
	}
	TXbuf[TXbufInPtr++] = crc & 0xff;
	TXbuf[TXbufInPtr++] = crc >> 8;	
}

void xmit(char toSend) {
	while (!( UCSR0A & (1<<UDRE0)));
	
	UDR0 = toSend;
	while (!( UCSR0A & (1<<TXC0)));
	UCSR0A |= (1<<TXC0);				// Reset TXC flag.
}

void sendTXbuf(void) {
	DE_HI;
	while (TXbufInPtr != TXbufOutPtr) {
		xmit(TXbuf[TXbufOutPtr++]);
		if (TXbufOutPtr == MAXBUFF)
			TXbufOutPtr = 0;
	}
	DE_LO;
}

void reply(char toPost) {
	setDataBus(asOutput);
	PORTB = (PINB&~0x7)|(toPost&0x7);
	PORTD = (PIND&~0xf8)|(toPost&0xf8);
}

char devType(void) {
	int		dev;
	
	dev = (((int)tempBuf[2])<<8) | tempBuf[3];
	
	if (dev < 1000)
		return discInput;
	if (dev < 20000)
		return coil;
	if (dev < 30000)
		return illigalAddress;
	if (dev < 40000)
		return inputReg;
	if (dev < 50000)
		return holdingReg;
	return illigalAddress;
}
void regOperation(void) {
	if (command == readRegister) {
		switch (devType()) {
			case discInput:
				tempBuf[1] = 2;
				break;
			case coil:
				tempBuf[1] = 1;
				break;
			case inputReg:
				tempBuf[1] = 4;
				break;
			case holdingReg:
				tempBuf[1] = 3;
				break;
			case illigalAddress:
				status = illigalAddress;
				return;
		}
	} else {
		switch (devType()) {
			case coil:
				tempBuf[1] = 5;
				break;
			case holdingReg:
				tempBuf[1] = 6;
				break;
			case discInput:
			case inputReg:
				status = illigalFunction;
				return;
			case illigalAddress:
				status = illigalAddress;
				return;
		}
	}
	CRC();
	RXbufInPtr = 0;
	RXbufOutPtr = 0;
	sendTXbuf();
}

void USART_Init(unsigned int baudrateIndex) {
	unsigned int ubrr;
	
	ubrr = (F_CPU / 8 / baud[baudrateIndex]) - 1;
	
	/* Set baud rate */
	UBRR0H = (unsigned char)(ubrr>>8);
	UBRR0L = (unsigned char)ubrr;

	/* Enable double speed */
	UCSR0A |= (1<<U2X0);

	/* Enable receiver, transmitter and also RX_complete_interrupt */
	UCSR0B = (1<<RXCIE0)|(1<<RXEN0)|(1<<TXEN0);

	/* Set frame format: 8N1 */
	UCSR0C = (3<<UCSZ00);
}

ISR(USART_RX_vect) {
	RXbuf[RXbufInPtr++] = UDR0;
	if (RXbufInPtr == MAXBUFF)
		RXbufInPtr = 0;
}

ISR(INT0_vect)	{								// We got a chip_select (CPU wants something).
	char		operation, dataByte;
	
	operation = PINC & 0x7;						// Snapshot from I/O pins.
	dataByte = (PIND & 0xf8)|(PINB & 0x07);		// Snapshot from data bus. 

	switch (operation) {
		case WR_COMMAND:
			switch (dataByte) {
				case clearRXbuffer:
					RXbufInPtr = 0;
					RXbufOutPtr = 0;
					command = 0;
					break;
				case clearTXbuffer:
					TXbufInPtr = 0;
					TXbufOutPtr = 0;
					command = 0;
					break;
				case flushTXbuffer:
					if (appendCRC)
						CRC();
					sendTXbuf();
					TXbufInPtr = 0;
					TXbufOutPtr = 0;
					command = 0;
					break;
				case enableCRCappend:
					appendCRC = 1;
					break;
				case disableCRCappend:
					appendCRC = 0;
					command = 0;
					break;
				case writeRegister:
				case readRegister:
					TXbufInPtr = 0;
					TXbufOutPtr = 0;
				case getBaudrate:
				case setBaudrate:
				case sizeRXbuffer:
				case readRXbuffer:
				case writeTXbuffer:
				command = dataByte;							// What's the command?
				break;
			}
			break;

		case RD_STATUS:
			reply(status);
			break;
			
		case WR_DATA:
			switch (command) {
				case setBaudrate:
					newBaud = dataByte;
					USART_Init(newBaud);
					command = 0;
					break;
				case writeTXbuffer:
					TXbuf[TXbufInPtr++] = dataByte;
					if (TXbufInPtr == MAXBUFF)
						TXbufInPtr = 0;
					break;
				case readRegister:
					if (TXbufInPtr < 4) {
						if (TXbufInPtr == 1)
							TXbufInPtr++;
						TXbuf[TXbufInPtr++] = dataByte;
					}
					if (TXbufInPtr == 4)
						regOperation();
					break;
				case writeRegister:
					if (TXbufInPtr < 6) {
						if (TXbufInPtr == 1)
						TXbufInPtr++;
						TXbuf[TXbufInPtr++] = dataByte;
					}
					if (TXbufInPtr == 6)
						regOperation();
					break;
			}
			break;

		case RD_DATA:
			switch (command) {
				case readRXbuffer:
					if (RXbufInPtr != RXbufOutPtr) {
						reply(RXbuf[RXbufOutPtr++]);
						if (RXbufOutPtr == MAXBUFF)
							RXbufOutPtr = 0;
					} else
						reply(0);
					break;
				case getBaudrate:
					reply(newBaud);
					command = 0;
					break;
				case sizeRXbuffer:
					if (RXbufOutPtr <= RXbufInPtr)
						reply(RXbufInPtr - RXbufOutPtr);
					else
						reply(MAXBUFF - RXbufOutPtr + RXbufInPtr);
					command = 0;
					break;
				case readRegister:

					break;
				default:
					reply(0xff);
			}
	}
	RSM_LO;							// Pulse RSM to release wait line.
	RSM_HI;
	
	setDataBus(asInput);
}

int main(void) {
	USART_Init(newBaud);		// Initialize USART

	DDRC |= (1<<RSM);			// Configure RSM pin as output
	RSM_HI;						// Turn off RSM (active low)
	EIMSK = (1<<INT0);			// Enable INT0 (chip select)
	
	DDRC |= (1<<DE);			// Configure DE pin as output
	DE_LO;						// Put SN76175 in "receive mode"
	
	setDataBus(asInput);

	sei();
	while (1);
}

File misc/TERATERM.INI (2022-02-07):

[BG]
; Use Eterm look-feel Background extension (on/off)
BGEnable=off

; Use AlphaBlend API (on/off)
BGUseAlphaBlendAPI=on

; Susie plugin path
BGSPIPath=plugin

; Fast window sizing/moving
BGFastSizeMove=on

; Flickerless window moving
BGFlickerlessMove=on

; If HideTitle=on and BGNoFrame=on, use window without frame
; you can resize window with Alt + Shift + LeftDrag
BGNoFrame=on

; wildcard => random select
BGThemeFile=theme\*.ini

; This option ignores the BGThemeFile in any case. When the option is on,
; the wallpaper image does not be mixed with theme file image.
BGIgnoreThemeFile=off


[Tera Term]
;	Tera Term version number
Version=4.106

;	Language (English/Japanese/Russian/Korean/UTF-8)
Language=English

; User interface language file that includes message strings.
; Tera Term uses built-in English message when the file or message is not found.
UILanguageFile=lang\Default.lng

; Connecting timeout value(per seconds). No action if the value is zero.
; Connecting socket could be canceled after the value timeout if the value is greater than zero.
; The default value is zero(depends on Windows TCP/IP stack implementation).
ConnectingTimeout=0

; pasting string by clicking mouse right button disabled
DisablePasteMouseRButton=off

; pasting string by clicking mouse middle button disabled
DisablePasteMouseMButton=on

; confirm pasting string by clicking mouse right button
ConfirmPasteMouseRButton=off

; confirm changing clipboard string by clicking mouse right button
ConfirmChangePaste=on
ConfirmChangePasteCR=on
PasteDialogSize=330,220
ConfirmChangePasteStringFile=

; Scroll out the current buffer when the clear screen does.
ScrollWindowClearScreen=on

; Reset scrollback on display activity
AutoScrollOnlyInBottomLine=on

; Starting the selection only by a left button.
SelectOnlyByLButton=on

; New connection by Alt-N Accelerator key
AcceleratorNewConnection=on

; Duplicate session by Alt-D Accelerator key disabled
DisableAcceleratorDuplicateSession=off

; Cygwin connection by Alt-G Accelerator key
AcceleratorCygwinConnection=on

; Send break by Alt-B Accelerator key disabled
DisableAcceleratorSendBreak=off

; New connection Menu disabled
DisableMenuNewConnection=off

; Duplicate session Menu disabled
DisableMenuDuplicateSession=off

; Send break Menu disabled
DisableMenuSendBreak=off

;	ANSI color definition (in the case FullColor=on)
;	* UseTextColor should be off, or the background and foreground color of
;	  VTColor are assigned to color-number 0 and 7 respectively, even if
;	  they are specified in ANSIColor.
;	* ANSIColor is a set of 4 values that are color-number(0--15),
;	  red-value(0--255), green-value(0--255) and blue-value(0--255).
ANSIColor=0,0,0,0, 1,255,0,0, 2,0,255,0, 3,255,255,0, 4,128,128,255, 5,255,0,255, 6,0,255,255, 7,255,255,255, 8,64,64,64, 9,192,0,0, 10,0,192,0, 11,192,192,0, 12,64,64,192, 13,192,0,192, 14,0,192,192, 15,192,192,192
; xterm
; ANSIColor=0,0,0,0, 1,255,0,0, 2,0,255,0, 3,255,255,0, 4,92,92,255, 5,255,0,255, 6,0,255,255, 7,255,255,255, 8,127,127,127, 9,205,0,0, 10,0,205,0, 11,205,205,0, 12,0,0,238, 13,205,0,205, 14,0,205,205, 15,229,229,229
; PuTTY
;ANSIColor=0,0,0,0, 1,255,85,85, 2,85,255,85, 3,255,255,85, 4,85,85,255, 5,255,85,255, 6,85,255,255, 7,255,255,255, 8,85,85,85, 9,187,0,0, 10,0,187,0, 11,187,187,0, 12,0,0,187, 13,187,0,187, 14,0,187,187, 15,187,187,187
; Tera Term Pro 2.3
;ANSIColor=0,0,0,0, 1,255,0,0, 2,0,255,0, 3,255,255,0, 4,0,0,255, 5,255,0,255, 6,0,255,255, 7,255,255,255, 8,128,128,128, 9,128,0,0, 10,0,128,0, 11,128,128,0, 12,0,0,128, 13,128,0,128, 14,0,128,128, 15,192,192,192
; Solarized (http://ethanschoonover.com/solarized)
;ANSIColor=0,7,54,66, 1,203,75,22, 2,88,110,117, 3,101,123,131, 4,131,148,150, 5,108,113,196, 6,147,161,161, 7,253,246,227, 8,0,43,54, 9,220,50,47, 10,133,153,0, 11,181,137,0, 12,38,139,210, 13,211,54,130, 14,42,161,152, 15,238,232,213
; Windows console new scheme (https://blogs.msdn.microsoft.com/commandline/2017/08/02/updating-the-windows-console-colors)
;ANSIColor=0,12,12,12, 1,231,72,86, 2,22,198,12, 3,249,241,165, 4,59,120,255, 5,180,0,158, 6,97,214,214, 7,242,242,242, 8,118,118,118, 9,197,15,31, 10,19,161,14, 11,193,156,0, 12,0,55,218, 13,136,23,152, 14,58,150,221, 15,204,204,204

;	Enable continued-line copy
EnableContinuedLineCopy=on

; Mouse cursor type (arrow/ibeam/cross/hand)
MouseCursor=ibeam

; Translucent window (0 - 255: transparency value)
AlphaBlend=255
AlphaBlendActive=255

; Cygwin install path
CygwinDirectory=

; Viewlog Editor path
ViewlogEditor=C:\Windows\notepad.exe

; Locale for Unicode
;Locale=chs
Locale=english

; CodePage for Unicode
CodePage=1252

; Background color of text uses background color of screen (on/off)
UseNormalBGColor=on

;	Port type (serial/tcpip)
Port=serial

;	Window positions
VTPos=-2147483648,-2147483648
TEKPos=-2147483648,-2147483648

;	Terminal size
TerminalSize=120,50
;	Terminal size=window size (on/off)
TermIsWin=on
;	Auto window resizing option (on/off)
AutoWinResize=off
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

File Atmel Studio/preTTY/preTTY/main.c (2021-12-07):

/*
 * preTTY.c v1.0
 *
 * Created: 29/08/2021 17:29:23
 * Author : kaltchuk
 */ 


#define F_CPU	20000000UL

#include <avr/io.h>
#include <avr/interrupt.h>
#include <util/delay.h>

#define BAUD		250000
#define MYUBRR		((F_CPU/8/BAUD)-1)

#define CS			(PIND&(1<<INT0))
#define RSM			3
#define RSM_LO		(PORTC &= ~(1<<RSM))
#define RSM_HI		(PORTC |= (1<<RSM))

#define asInput		1
#define asOutput	2

#define WR_DATA		2
#define WR_COMMAND	3
#define RD_DATA		4
#define RD_STATUS	5

#define CR			0x0d
#define LF			0x0a

#define MAXBUFF		256

char			uBuffRX[MAXBUFF]; 					// Buffer for chars that arrived through serial port.
int				uBuffRX_inPtr=0, uBuffRX_outPtr=0;

unsigned int long	baud[] = {1200, 2400, 4800, 9600, 14400, 19200, 28800, 38400, 57600, 125000, 250000};

void setDataBus(int modus)
{
	if (modus == asInput)	// Write zeros to PORTs
	{
		DDRB &= ~0x07;
		DDRD &= ~0xf8;
	}
	else					// Write ones to PORTs
	{
		DDRB |= 0x07;
		DDRD |= 0xf8;
	}
}

void xmit(char toSend)
{
	while ( !( UCSR0A & (1<<UDRE0)) )
	{}
	UDR0 = toSend;
}

void reply(char toPost)
{
	setDataBus(asOutput);
	PORTB = (PINB&~0x7)|(toPost&0x7);
	PORTD = (PIND&~0xf8)|(toPost&0xf8);

	RSM_LO;							// Release wait line
	RSM_HI;

	setDataBus(asInput);
}

void USART_Init(unsigned int ubrr)
{
	/* Set baud rate */
	UBRR0H = (unsigned char)(ubrr>>8);
	UBRR0L = (unsigned char)ubrr;

	/* Enable double speed */
	UCSR0A |= (1<<U2X0);

	/* Enable receiver, transmitter and also RX_complete_interrupt */
	UCSR0B = (1<<RXCIE0)|(1<<RXEN0)|(1<<TXEN0);

	/* Set frame format: 8N1 */
	UCSR0C = (3<<UCSZ00);
}

ISR(USART_RX_vect)
{
	uBuffRX[uBuffRX_inPtr++] = UDR0;
	if (uBuffRX_inPtr == MAXBUFF)
		uBuffRX_inPtr = 0;
}

ISR(INT0_vect)									// We got a chip_select (CPU wants something)
{
	char				operation;
	char				dataByte;
	unsigned long int	newBaud;
	
	operation = PINC & 0x7;						// Snapshots from I/O pins
	dataByte = (PIND & 0xf8)|(PINB & 0x07);

	switch (operation)
	{
		case RD_DATA:							// Read data request
			if (uBuffRX_inPtr != uBuffRX_outPtr)
			{
				reply(uBuffRX[uBuffRX_outPtr++]);
				if (uBuffRX_outPtr == MAXBUFF)
					uBuffRX_outPtr = 0;
			}
			else
			{
				RSM_LO;							// Release wait line
				RSM_HI;
			}
		break;
		
		case RD_STATUS:							// Read status request
			if (uBuffRX_inPtr != uBuffRX_outPtr)	// Put 0xff on data bus
				reply(0xff);
			else								// Put 00 on data bus
				reply(0);
		break;
		
		case WR_DATA:							// write data request
			xmit(dataByte);
			RSM_LO;								// Release wait line
			RSM_HI;
		break;
		
		case WR_COMMAND:						// write command request
			if (dataByte < 11)
			{
				newBaud = baud[(int) dataByte];
				USART_Init((F_CPU/8/newBaud)-1);
			}
			RSM_LO;								// Release wait line
			RSM_HI;
		break;
	}
}

int main(void)
{
	char	iniMsg[] = "\r\n*** TTY Card - firmware v1.1. ***\r\n*** by Kaltchuk, sep/2021.    ***\r\n\r\n\0";
	int		i=0;
	
	USART_Init(MYUBRR);		// Initialize USART
	while ( iniMsg[i] != 0)	
	{
		xmit(iniMsg[i++]);
	}
	DDRC |= (1<<RSM);		// Configure RSM pin as output
	RSM_HI;					// Turn off RSM (active low)
	EIMSK = (1<<INT0);		// Enable INT0 (chip select)
	
	sei();
	while (1) 				// If we're not busy attending a service request
	{						// from CPU, let's empty the TX buffer.
	}
}

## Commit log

2020-12-01 Create USB2RS232.kicad_pcb-bak
2020-12-02 Update USB2RS232.kicad_pcb-bak
2020-12-03 Create generic grid.kicad_pcb
    [generic grid.kicad_pcb]
2020-12-03 Create generic grid.kicad_pcb-bak
2020-12-03 Create generic grid.sch
    [generic grid.sch]
2021-01-03 Update stickers.kicad_pcb-bak
2022-04-21 i2c manager
2022-04-22 I2C manager 1.4
2022-04-25 i2c mgr
2022-04-29 i2cmgr 1.5
2022-05-03 Update I2C manager.uvgui.kaltc
2022-05-04 i2cmgr 1.6 updates
2022-05-15 i2c tests
    [clock.obj, sw10.obj]
2022-05-15 i22 manager
    [i2c_manager.obj]
2022-05-21 updates i2c_manager
    [i2c_manager.obj]
2022-05-23 updated i2c manager
2022-05-24 updates i2c card
    [I2C.kicad_sch]
2022-05-24 pcb updates
    [Backplane v2.kicad_pcb, FLASHv2.kicad_pcb, TopBottomLateral.kicad_pcb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]
2022-05-25 enclosure updates
    [TopBottomLateral.kicad_pcb]
2022-05-26 pcb update
    [TopBottomLateral.kicad_pcb]
2022-05-28 i2c manager fix
    [TopBottomLateral.kicad_pcb, i2c_manager.obj]
2022-05-31 i2c manager & enclosure updates
2022-06-01 extension card
    [Extension.kicad_pcb, Extension.kicad_sch]
2022-06-03 remove frontal
    [Front Panel-B_Cu.gbr, Front Panel-B_Mask.gbr, Front Panel-B_SilkS.gbr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]
2022-06-06 office updates
    [TTY.kicad_pcb]
2022-06-07 update PCBs
    [I2C_frontal-B_Cu.gbr, I2C_frontal-B_Mask.gbr, I2C_frontal-B_Silkscreen.gbr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]
2022-06-07 PCBs update
    [I2C_frontal.kicad_pcb]
2022-06-07 telnet server
    [Telnet_Server.kicad_pcb, Telnet_Server.kicad_sch]
2022-06-08 telnet server update
    [Telnet_Server.kicad_sch]
2022-06-18 manual update
    [CPU.csv, FLASHv2.csv, MEM.csv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]
2022-06-19 diskboot update
    [diskboot.obj]
2022-06-25 recovery from doomsday
    [i2c_manager.obj]
2022-08-15 directory modifications.
    [Backplane v2-B_Cu.gbr, Backplane v2-B_Mask.gbr, Backplane v2-B_SilkS.gbr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]
2022-08-25 gpio test
    [flicker.obj]
2022-08-27 8051 tests
    [I2C.kicad_pcb, I2C.kicad_sch, flicker.obj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]
2022-09-15 8051 serial tests
    [serial_test.obj]
2022-09-16 serial tests
    [serial_and_timer_test.obj, serial_test.obj]
2022-09-27 DO-8 modbus server
    [DO-8.obj]
2022-09-27 DO-8 schematics
    [DO-8.kicad_pcb, DO-8.kicad_sch]
2022-09-28 do8 and rs485
    [DO-8.kicad_sch, RS485_echo.obj]
2022-10-09 DI & DO updates
    [DI-16.kicad_sch, DO-08.kicad_sch, untitled.kicad_sch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]
2022-12-21 modbus tests
    [DO-8.obj, RS485_echo.obj, serial_and_timer_test.obj]
2022-12-25 i2c eeprom
2022-12-26 i2c eprom
2023-01-02 DO-08 and PT100
    [PT100.kicad_pcb, PT100.kicad_sch, PT100.obj]
2023-01-06 plc cards
    [DI-08.kicad_pcb, DI-08.kicad_sch, DO-8.obj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]
2023-02-13 RCבשר
    [RCcar.kicad_pcb, RCcar.kicad_sch]
2024-12-13 total commit
    [4051prog.kicad_pcb, 4051prog.kicad_sch, AVRisp 328p adapter.dsn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]
